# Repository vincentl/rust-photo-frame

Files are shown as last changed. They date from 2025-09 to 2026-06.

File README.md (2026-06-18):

# Photo Frame

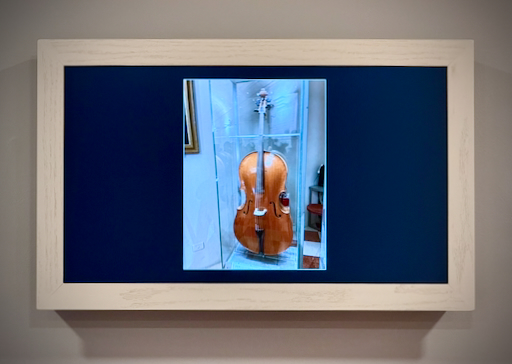
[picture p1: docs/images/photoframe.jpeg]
photo frame on grey wall with cream colored wooden frame displaying black matted image of a string instrument


Build a wall-mounted digital photo frame from a Raspberry Pi 5 and a 4K monitor. It runs a self-managing slideshow from a local photo library: GPU-accelerated transitions, customizable matting, a smart playlist that favors newer photos while keeping the rotation evenly spread, and a built-in Wi-Fi recovery portal — all on-device, no cloud dependency after setup.

**Built for makers and hobbyists** who want a bespoke display they fully control, not a subscription appliance.

---

## What you'll build

A kiosk-mode Raspberry Pi 5 that:

- Cycles through photos in `/var/lib/photoframe/photos` with smooth GPU transitions and matting
- Favors freshly added photos and spreads the rotation so it never feels repetitive
- Wakes and sleeps on a configurable schedule (or stays on always — your choice)
- Recovers from Wi-Fi drops by raising a hotspot with a QR-code-guided web UI for re-provisioning credentials
- Accepts control commands over a Unix socket for scripting and hardware button integration

---

## What you'll need

| Component | Notes |
| --- | --- |
| Raspberry Pi 5 (4 GiB+) | 8 GiB recommended for 4K with effects |
| 4K monitor | Tested with Dell S2725QC 27" 4K. HDMI-CEC is not used. |
| Power | Pi 5 runs off the monitor's USB-C PD port; a 27W USB-C supply only if your monitor lacks PD |
| HDMI cable | Short, high-quality run; the display won't tolerate a marginal cable |
| High-endurance microSD  | 32 GiB+ recommended for always-on use |
| Momentary pushbutton | Optional — wires to Pi 5 power pads for hardware wake/sleep |
| Mounting + enclosure | French-cleat + shadow-box reference build with CAD files in `maker/` |

Full BOM and physical assembly: **[docs/build.md](docs/build.md)**.

---

## Get started

1. **Build the frame** — [docs/build.md](docs/build.md): BOM, button wiring, fabrication
2. **Install the software** — [docs/install.md](docs/install.md): SD card → first wake
3. **Preview effects** — a labeled tour of every transition and mat so you can choose which to configure: stage photos, run `showcase/activate.sh` on the Pi (see [showcase/README.md](showcase/README.md))
4. **Tune the experience** — [docs/configure.md](docs/configure.md): transitions, mats, schedule. Start from a ready-made config in [examples/](examples/README.md) (minimal, showcase tour, or the everything kitchen-sink)
5. **Run it day-to-day** — [docs/operate.md](docs/operate.md): commands and troubleshooting

Optional deeper dives (cloud sync, Wi-Fi internals, power model, memory tuning, kiosk stack) live in **[docs/advanced.md](docs/advanced.md)**; rendering performance, measurement tools, and 4K60 tuning live in **[docs/performance.md](docs/performance.md)**.

If you want to modify the code, see **[CONTRIBUTING.md](CONTRIBUTING.md)** and the contributor guides under **[developer/](developer/)**.

---

## Transitions & mats

The frame ships nine GPU **transitions** (how one photo gives way to the next) and nine **mats** (the border/background framing each photo).

| Transitions | |
| --- | --- |
| `fade` | cross-fade (optionally through black) |
| `wipe` | directional linear wipe with a feathered edge |
| `push` | incoming photo slides in, pushing the old one out |
| `e-ink` | e-paper-style flash + stripe reveal |
| `dissolve` | film-style value-noise threshold dissolve |
| `radial-wipe` | circle or diamond reveal growing from a center point |
| `venetian-blinds` | horizontal/vertical slat reveal |
| `crossfade-zoom`  | cross-fade with a gentle Ken-Burns zoom |
| `iris` | mechanical camera-iris: blades close over the photo and reopen on the next |

| Mats | |
| --- | --- |
| `fixed-color` | solid color border (one or more swatches) |
| `blur` | blurred copy of the photo as the backdrop |
| `studio` | museum mat board with a 45° bevel and linen-weave texture |
| `fixed-image` | your own image as the backdrop |
| `gradient` | linear or radial gradient between two colors |
| `vignette` | solid color with darkened edges |
| `cinematic-blur` | blurred backdrop with darken + vignette (Apple-TV-aerial look) |
| `passe-partout`  | clean 45° bevel mat board, no weave (a crisper `studio`) |
| `drop-shadow` | photo floated above a solid mat with a soft drop shadow |

Preview them live with the [showcase](showcase/README.md) tour. For commented examples of every option see [`config.yaml`](config.yaml); for the complete reference (every key, default, and behavior) see the Transition and Matting sections of [docs/configure.md](docs/configure.md).

---

## Repository layout

```
crates/photoframe/     Main slideshow application (GPU rendering, viewer pipeline)
crates/buttond/        Hardware button daemon + wake/sleep scheduling
crates/wifi-manager/   Captive portal and Wi-Fi recovery agent
crates/config-model/   Shared configuration types
setup/                 Provisioning scripts for Raspberry Pi OS
docs/                  build, install, configure, operate, advanced
showcase/              showcase.yaml, activate/deactivate scripts — labeled tour of every effect
maker/                 Physical build files (STL, SVG, SCAD)
developer/             Contributor guides (testing, architecture) + debug scripts
tests/                 Manual smoke tests and diagnostics scripts
config.yaml            Annotated example configuration
```

---

## How it works (optional deep dive)

The runtime is five async pipeline tasks — plus a Unix control-socket task — communicating over bounded channels. This keeps memory predictable and decouples CPU decode from GPU rendering.

```mermaid
flowchart LR
  MAIN[Main] --> FILES[PhotoFiles]
  MAIN --> MAN[PhotoManager]
  MAIN --> LOAD[PhotoLoader]
  MAIN --> AFFECT[PhotoEffect]
  MAIN --> VIEW[PhotoViewer]
  MAIN --> CTRL[Control socket]

  FILES -->|inventory updates| MAN
  MAN -->|invalid photo| FILES
  MAN -->|photo requests| LOAD
  LOAD -->|decoded image| AFFECT
  AFFECT -->|processed image| VIEW
  LOAD -->|invalid photo| FILES
  VIEW -->|displayed event| MAN

  BUTTOND[buttond / CLI] -->|set-state, toggle| CTRL
  CTRL -->|viewer commands| VIEW
```

- **PhotoFiles** — watches the library and maintains an inventory of available images
- **PhotoManager** — schedules photos on a virtual timeline. A half-life _weight_ favors newly added photos and fades them toward parity over a configurable period. Photos copied in while the frame is running debut within a few slides via a priority queue (it wins against the rotation at odds equal to its weight), so a just-added album appears almost immediately, then settles into the spaced rotation. A refractory _minimum-spacing_ rule keeps that rotation even — a photo can't return until a configurable fraction of the library has played — which avoids clumps and starvation _without changing how often each photo appears_ (set `playlist.order: weighted-random` for plain independent sampling). Weighting-preserving and offline-simulatable via `--playlist-dry-run`
- **PhotoLoader** — decodes JPEG/PNG in parallel (configurable concurrency) to RGBA pixel buffers
- **PhotoEffect** — optionally applies print-simulation effects (paper texture, gallery lighting)
- **PhotoViewer** — GPU-accelerated rendering with configurable matting and transitions via WGPU/Wayland
- **Control socket** (Unix) — accepts `set-state` / `toggle-state` commands from `buttond` (hardware button and wake/sleep schedule) or the CLI, and forwards them to the viewer

---

## References

- **Studio mat weave texture.** Adapted from Mike Cauchi's breakdown of tillable cloth shading. ["Research – Tillable Images and Cloth Shading"](https://www.mikecauchiart.com/single-post/2017/01/23/research-tillable-images-and-cloth-shading).
- **Print simulation shading.** Based on Rohit A. Patil, Mark D. Fairchild, and Garrett M. Johnson, ["3D Simulation of Prints for Improved Soft Proofing"](https://repository.rit.edu/cgi/viewcontent.cgi?article=1159&context=other).

---

## AI Statement

This project was developed with significant assistance from multiple AI tools:

- **Anthropic**: Claude Code with Sonnet & Opus models was used for design discussions, code generation, debugging, and drafting documentation.
- **OpenAI**: Codex with various GPT models was used for design discussions, code generation, debugging, and drafting documentation.

---

## License

MIT License — see [LICENSE](LICENSE) for full text.

© 2026 Vincent Lucarelli

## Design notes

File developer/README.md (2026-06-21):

# Developer

Documentation and tooling for working on the photo frame. End-user docs live in
[../README.md](../README.md) and [../docs/](../docs/); the contributor entry
point is [../CONTRIBUTING.md](../CONTRIBUTING.md).

## Guides

- **[testing.md](testing.md)** — automated checks, the on-device test plan, and the release checklist.
- **[architecture.md](architecture.md)** — setup-script architecture and kiosk-stack debugging.

## Scripts

Run these on a live Pi unless noted (the guides give context):

- `capture-system-baseline.sh` — snapshot system + toolchain versions under `artifacts/upgrade-baseline-<timestamp>/` (used by the dependency upgrade runbook).
- `overlay-test.sh` — overlay takeover smoke-test for Sway (focus/fullscreen behavior before Wi-Fi recovery testing).
- `suspend-wifi.sh` — simulate a Wi-Fi authentication failure to exercise the wifi-manager recovery path.
- `fake-btime.sh` — copy a file with a forced creation time (btime); handy for testing the playlist's new-photo weighting.
- `gather-playlist-metrics.sh` — pull `photo-log.txt` + `photo-list.txt` off the frame (needs `metrics: true`) for the last N days or all retained journal. `gather-playlist-metrics.sh [DAYS|all] [OUTDIR]`.
- `analyze-playlist-metrics.py` — **runs off-device** on those two files: audits coverage/starvation, recurrence spacing, weighting, and FIFO debut latency. Self-documenting header (how to gather/run/interpret) plus `--help`.
- `systemd/wifi-overlay-test.service` — unit used by the overlay takeover test.

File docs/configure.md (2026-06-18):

# Configure

The active configuration on an installed system is `/etc/photoframe/config.yaml` (edit with `sudo`). When running from source, pass the config path on the CLI.

After editing, restart the kiosk to apply:

```bash
sudo systemctl stop greetd.service && sleep 1 && sudo systemctl start greetd.service
```

> Always edit `/etc/photoframe/config.yaml`, not the template at `/opt/photoframe/etc/photoframe/config.yaml` — the template gets overwritten on redeploy.

The visual feature blocks (`transition`, `matting`, `photo-effect`) all use a shared `selection` + `active` structure described below.

## Quick start

For most edits, this is the sequence:

1. Set `photo-library-path` to your actual photo root.
2. Tune slide pacing with `global-photo-settings.dwell-ms`.
3. Pick one transition preset in `transition.active`.
4. Pick one mat preset in `matting.active`.
5. Validate without launching the viewer:

   ```bash
   cargo run -p photoframe -- --playlist-dry-run 1
   ```

## Choosing a starting config

You don't have to start from scratch. The repo ships several starting points
(details and a comparison table in [examples/README.md](../examples/README.md)):

- [`config.yaml`](../config.yaml) — the rich, fully-commented default the installer
  seeds; every transition and mat with varied colors and angles. Most people start here.
- [`examples/minimal.yaml`](../examples/minimal.yaml) — the smallest valid file; build up
  from defaults.
- [`examples/use-showcase.yaml`](../examples/use-showcase.yaml) — a labeled tour of every
  transition and mat (see [showcase/README.md](../showcase/README.md)).
- [`examples/everything.yaml`](../examples/everything.yaml) — every kind *and* every
  parameter variant, to trim down.

Copy one over `/etc/photoframe/config.yaml` (or crib blocks from it) and restart the kiosk.

## Starter configuration

```yaml
photo-library-path: /var/lib/photoframe/photos
# ├── cloud/  # managed by sync jobs; safe to resync or replace wholesale
# └── local/  # manual drops (USB, scp) that should survive sync resets

# Render/transition settings
transition:
  selection: random # fixed, random, or sequential
  active:
    - kind: fade
      duration-ms: 400
global-photo-settings:
  dwell-ms: 12000 # Time an image remains fully visible (ms)
  oversample: 1.0 # GPU render oversample vs. screen size
  max-upscale-factor: 1.0 # Limit for enlarging small images
viewer-preload-count: 3 # Images the viewer preloads; also sets viewer channel capacity
loader-max-concurrent-decodes: 4 # Concurrent decodes in the loader
startup-shuffle-seed: null # Optional deterministic seed for initial shuffle

photo-effect:
  active: [] # Optional effects; add entries (e.g., print-simulation) to enable

playlist:
  new-multiplicity: 3 # How many copies of a brand-new photo to schedule per cycle
  half-life: 3 days # How quickly that multiplicity decays back toward 1

matting:
  selection: random
  active:
    - kind: fixed-color
      minimum-mat-percentage: 0.0 # % of each screen edge reserved for the mat border
      colors: [[0, 0, 0], [32, 32, 32]]
    - kind: blur
      minimum-mat-percentage: 3.5
      sigma: 32.0
      sample-scale: 0.125
      backend: neon  # arm64 vector path; falls back to cpu automatically
```

If the frame launches to a black screen, check that `photo-library-path` points to a directory the runtime can read and that the kiosk account has access. The directory should contain `cloud/` and `local/` subdirectories — the runtime merges both. Validate a YAML edit quickly with `cargo run -p photoframe -- --playlist-dry-run 1`, which parses the config without opening the render window.

## Top-level keys

| Role | Keys |
| --- | --- |
| **Required** | `photo-library-path` |
| **Schema** | `config-version` |
| **Core timing** | `transition`, `global-photo-settings`, `playlist` |
| **Performance tuning**  | `viewer-preload-count`, `loader-max-concurrent-decodes`, `global-photo-settings.oversample` |
| **Deterministic runs**  | `startup-shuffle-seed` |
| **Presentation** | `photo-effect`, `matting` |
| **Greeting / Sleep** | `greeting-screen`, `sleep-screen` |
| **Runtime control** | `control-socket-path` |
| **External scheduling** | `awake-schedule` (consumed by `buttond`) |
| **Power button daemon** | `buttond` |
| **Showcase / preview**  | `showcase` |

## Key reference

### `config-version`

- **Purpose:** Declares which config-schema version the file targets, so a config written for a newer, incompatible schema fails fast with a clear message instead of a confusing per-key error.
- **Required?** Optional; defaults to the current supported version (`1`).
- **Accepted values & defaults:** A positive integer. This build supports `1`. A value higher than the build supports is rejected at startup with a message telling you to update photoframe.
- **Notes:** Leave at `1` unless a release note instructs otherwise. The version only bumps on a breaking config-schema change, which will be documented in the git history / release notes.

### `photo-library-path`

- **Purpose:** Sets the root directory that will be scanned recursively for supported photo formats.
- **Required?** Yes.
- **Accepted values & defaults:** Any absolute or relative filesystem path. The setup pipeline provisions `/var/lib/photoframe/photos` with `cloud/` and `local/` subdirectories.
- **Effect on behavior:** Switching the path changes the library the watcher monitors; the viewer reloads the playlist when the directory contents change.
- **Notes:** Keep the `cloud/` and `local/` folders under the configured root. Use `cloud/` for sync-managed content (rclone, Nextcloud) and `local/` for manual imports the sync should never prune.

### `control-socket-path`

- **Purpose:** Selects where the application exposes its Unix domain control socket.
- **Required?** Optional; defaults to `/run/photoframe/control.sock`.
- **Accepted values & defaults:** Any filesystem path, typically under `/run`, `/run/user/<uid>`, or another writable runtime directory.
- **Notes:** The kiosk provisioning script creates `/run/photoframe` (mode `0770`, owned by `kiosk:kiosk`) and installs a tmpfiles entry so the directory exists after every boot. If you override the setting, pre-create the directory with matching ownership: `sudo install -d -m 0770 -o kiosk -g kiosk /run/photoframe`.

### `transition`

- **Purpose:** Controls how the viewer blends between photos.
- **Required?** Optional; when omitted the frame uses a 400 ms fade.
- **Accepted values & defaults:** Mapping documented in [Transition configuration](#transition-configuration).
- **Effect on behavior:** Adjust duration, direction, randomness, or transition family — from subtle fades to bold pushes or e‑ink reveals.

### `global-photo-settings`

- **Purpose:** Core photo timing and sizing parameters.
- **Required?** Optional; sensible defaults apply when omitted.
- **Keys and defaults:**
  - `dwell-ms` (u64, default `2000`): How long to show the current photo before transitioning.
  - `oversample` (float, default `1.0`): GPU render oversample relative to screen size. Must be positive.
  - `max-upscale-factor` (float, default `1.0`): Maximum enlargement applied when fitting small photos inside the mat.

### `viewer-preload-count`

- **Purpose:** Number of decoded images the viewer keeps queued ahead of the current slide.
- **Required?** Optional. Default `3`.
- **Effect on behavior:** Higher counts buffer more content, smoothing playback on slower storage but increasing memory usage. See [Advanced › Memory tuning](advanced.md#memory-tuning) for sizing guidance.

### `loader-max-concurrent-decodes`

- **Purpose:** Limits how many images the CPU decoding task processes simultaneously.
- **Required?** Optional. Default `4`. Minimum `1`.

### `startup-shuffle-seed`

- **Purpose:** Seeds the initial RNG used when shuffling the first playlist.
- **Required?** Optional. `null` (default) draws entropy from the system RNG.
- **Effect:** Providing a seed freezes the opening order — useful for demos, debugging, or deterministic tests.

### `playlist`

- **Purpose:** Tunes how the weighting system surfaces new photos and how evenly the slideshow spreads them.
- **Required?** Optional.
- **Defaults:** three copies for new images, one-day half-life, `weighted-spread` order at `min-spacing` 0.7.

See [Playlist weighting](#playlist-weighting) for the algorithm.

### `photo-effect`

- **Type:** mapping (see [Photo effect configuration](#photo-effect-configuration))
- **Default:** disabled (`active: []`)
- **What it does:** Inserts an optional post-processing stage between the loader and viewer. The built-in `print-simulation` effect relights each frame with directional shading and paper sheen. Add it to `active` to enable; leave the list empty to keep the stage off.

### `greeting-screen`

- **Purpose:** Styles the GPU-rendered welcome card displayed while the library is warming up.
- **Required?** Optional.
- **Keys:**
  - `message` (string, default `Initializing…`)
  - `font` (string font name; falls back to bundled face)
  - `stroke-width` (float DIP, default `16.0`)
  - `corner-radius` (float DIP, default `0.75 × stroke-width`)
  - `duration-seconds` (float ≥ 0, default `4.0`)
  - `colors.background`, `colors.font`, `colors.accent` (hex sRGB strings)
- **Effect:** The renderer fits and centers the message inside a rounded double-line frame. `duration-seconds` guarantees the greeting remains on screen for at least that many seconds before the first photo appears.
- **Notes:** Colors accept `#rgb`, `#rgba`, `#rrggbb`, or `#rrggbbaa`. Low-contrast combinations log a warning.

### `sleep-screen`

- **Purpose:** Styles the card shown as the frame transitions into sleep.
- **Keys:** Mirror `greeting-screen` aside from `duration-seconds`, which does not apply when sleeping.
- **Effect:** Shares the same renderer as the greeting card, so sizing rules and readability checks are identical.

### Wake/sleep control

- **How it works:** The application has no internal schedule. After startup it remains asleep until another client sends `set-state` or `toggle-state` commands over the control socket.
- **Manual control:** Pipe JSON such as `{"command":"set-state","state":"awake"}` or `{"command":"toggle-state"}` to `/run/photoframe/control.sock` (override via `control-socket-path`).
- **Automation:** Deploy `buttond` (see below) and populate the shared `awake-schedule` block. `buttond` evaluates the schedule, issues `set-state` commands at the appropriate boundaries, and runs display power hooks on your behalf.

Example schedule fragment consumed by `buttond`:

```yaml
awake-schedule:
  timezone: America/New_York
  awake-scheduled:
    daily:
      - ["07:30", "22:00"]
    weekend:
      - ["09:00", "23:00"]
```

`awake-schedule` supports wrap-past-midnight windows, weekday/weekend overrides, and per-day exceptions. Times use `HH:MM` or `HH:MM:SS`. To wrap past midnight, give a range whose start is **later** than its end — e.g. `["21:00", "07:00"]` keeps the frame awake from 9 PM until 7 AM the next morning. An empty list for a day key (e.g. `friday: []`) means **sleep all day on that day** — remove the key to fall back to the `daily` window.

### `buttond` (power button daemon)

`buttond` watches the Pi 5 power-pad button via evdev and orchestrates scheduled wake/sleep transitions. It also drives DPMS commands so the panel actually powers down between schedule windows.

```yaml
buttond:
  device: null                      # optional explicit evdev path
  debounce-ms: 20                   # ignore chatter within this window
  single-window-ms: 250             # treat releases shorter than this as taps
  double-window-ms: 400             # wait this long for a second tap
  force-shutdown: true              # for systemctl: add -i and --no-ask-password
  shutdown-command:
    program: /usr/bin/systemctl
    args: [poweroff]
  screen:
    off-delay-ms: 3500
    display-name: HDMI-A-2          # wlr-randr output name; null = auto-detect
    on-command:
      program: /opt/photoframe/bin/powerctl
      args: [wake]
    off-command:
      program: /opt/photoframe/bin/powerctl
      args: [sleep]
```

Pair the block with a top-level `awake-schedule` to describe the desired wake windows.

**`buttond.screen.display-name` discovery.** The connector name must be queried inside the kiosk Wayland session:

```bash
# display is usually wayland-1; find it with: sudo ls /run/user/$(id -u kiosk)/wayland-*
sudo -u kiosk env XDG_RUNTIME_DIR=/run/user/$(id -u kiosk) WAYLAND_DISPLAY=wayland-1 wlr-randr
```

Common values: `HDMI-A-1`, `HDMI-A-2`. Setting `display-name` explicitly avoids auto-detect ambiguity on systems with multiple connectors.

**`force-shutdown`** controls whether `buttond` augments a systemctl command with `-i` (ignore inhibitors) and `--no-ask-password`. The default `true` makes `systemctl poweroff -i --no-ask-password` succeed without prompts. If you point `shutdown-command.program` at something other than `systemctl`, `buttond` strips those flags automatically.

**Runtime behavior:**

- **Single press:** resolves the current screen state and sends the appropriate `set-state` command to the control socket, then toggles the screen. If the display was off it immediately runs the wake command; if on, it delays for `off-delay-ms` (so the sleep card renders) before running the sleep command. The daemon inspects `wlr-randr` on each press, so restarts and manual overrides stay in sync.
- **Double press:** executes `shutdown-command`. Polkit allows `kiosk` to issue the request without prompting.
- **Long press:** bypassed so Pi 5 firmware can force power-off.
- **Scheduled transitions:** when `awake-schedule` is present, `buttond` waits for the greeting delay, applies the schedule's current state, then drives transitions using `set-state`.
- **Manual override:** a single press overrides the schedule until the next scheduled wake/sleep boundary, then the frame resumes following the schedule automatically. Press again to undo immediately. For example, pressing to sleep during a wake window keeps the frame asleep until that window ends; pressing to wake during a sleep window keeps it awake until the next scheduled wake.

`buttond` auto-derives `XDG_RUNTIME_DIR` and `WAYLAND_DISPLAY` for its `wlr-randr`/sway probes. Auto-detection scans `/dev/input/by-path/*power*` before falling back to `/dev/input/event*`. Set `buttond.device` if the wrong input is chosen. Provisioning pins `HandlePowerKey=ignore` in `/etc/systemd/logind.conf` so logind doesn't interpret presses as shutdown requests; only `buttond` reacts.

### `matting`

- **Purpose:** Chooses the mat/background style rendered behind every photo.
- **Required?** Optional.
- **Defaults:** `{ selection: fixed, active: [{ kind: fixed-color }] }` with a black swatch.

See [Matting configuration](#matting-configuration) for the full reference.

### `showcase`

- **Purpose:** Turns the slideshow into a labeled, deterministic tour of every registered transition and mat. On-screen captions identify each effect so you can copy the name directly into your real config.
- **Required?** Optional; defaults to disabled.
- **Keys:**

| Key | Type | Default | Meaning |
|-----|---|---|---|
| `enabled` | `bool` | `false` | Activates showcase mode. Overrides `transition.active` and `matting.active` with auto-enumerated sequential lists. |
| `caption` | `bool` | `true` | Show a text label (`transition: X mat: Y`) in the bottom-left corner of each frame. |
| `dwell-ms` | `u64` | `4000` | Milliseconds each photo is held; overrides `global-photo-settings.dwell-ms` when showcase is on. |
| `fixed-image-path` | path | — | Opt-in: include the `fixed-image` mat in the tour using this file as the backdrop. Omitting the path silently skips `fixed-image`. |

When `showcase.enabled` is true, `startup-shuffle-seed` defaults to `1` if unset, and `transition.active`/`matting.active` in the same file are ignored.

See [showcase/README.md](../showcase/README.md) and [Showcase mode](#showcase-mode) for usage.

## Showcase mode

Showcase mode is the fastest way to choose transitions and mats. It auto-enumerates every built-in effect, displays each one with a live caption, and advances to the next after a configurable dwell.

**Workflow (on the Pi):**

1. Stage media under `/var/lib/photoframe/showcase/photos/` (and optionally a `backgrounds/background.jpg` backdrop). See [showcase/README.md](../showcase/README.md).
2. Run `./showcase/activate.sh` — it backs up your live config, swaps in `showcase/showcase.yaml`, and restarts the kiosk into the tour.
3. Watch the captions. When you see an effect you like, the caption tells you the exact `kind` key.
4. Copy the kind(s) into your real `config.yaml` under `transition.active` and/or `matting.active`.
5. Run `./showcase/deactivate.sh` to restore your normal slideshow.

**Self-maintaining:** the tour is built at startup from `TransitionKind::ALL` and `MattingKind::ALL`. When future effects are added to the frame, they automatically appear in the tour without any edits to `showcase.yaml`.

**Interactive control** (e.g. advancing manually via a socket command) is not implemented — the tour advances on a timed dwell. This fits the frame's passive, keyboard-less Pi kiosk model; a `showcase-next` control command may be added in the future.

## Playlist weighting

Each photo is scheduled on a virtual timeline. A photo's **weight** sets how often it
appears: `weight(age) = max(1, new_multiplicity × 0.5^(age / half_life))`. Brand-new
photos peak at `new-multiplicity` and decay by half every `half-life` toward the
equilibrium weight of 1. After each showing a photo is rescheduled a random gap ahead
whose average length is `1 / weight`, so higher-weight photos recur sooner while still
being spaced apart (no bursts, no back-to-back repeats). Adding or removing photos
updates the schedule incrementally without resetting progress.

**Scheduling `order`** selects how each photo's showings are *spaced* around that
`1 / weight` average, without changing the average itself (so weighting is identical
across orders):

- `weighted-spread` (default) draws a **refractory (minimum-wait) gap**: a deterministic
  floor that no showing may fall below, plus exponential jitter above it. The
  `min-spacing` knob (`[0.0, 1.0)`) sets the floor as a fraction of one library "lap" — a
  photo's mean recurrence interval, which equals the library size in displays. So
  `min-spacing = 0.5` means *"a photo cannot return until at least half the library has
  played."* `0.7` (the shipped value) is a good balance of even coverage and
  unpredictability.
- `weighted-random` draws a plain **exponential** gap — memoryless, which makes it
  statistically equivalent to i.i.d. uniform-with-replacement. Simple, but high gap
  variance: some photos clump together while others go unseen for a long time. Identical
  to `weighted-spread` with `min-spacing: 0.0`; opt in only if you want raw randomness.

The gap law is `gap = f/weight + (1 − f)/weight · Exp(1)` with `f = min-spacing`. Its
mean is `1/weight` for every `f`, so **a photo's long-run show frequency never
changes** — only its spacing does (coefficient of variation `= 1 − f`). The floor also
auto-scales with weight, so a high-weight new photo is still allowed back sooner.

**Prompt debut for new photos.** The minimum-spacing floor would otherwise delay a
freshly copied-in photo's *first* appearance by a full `min-spacing` lap (tens of
minutes on a large library). To avoid that, photos discovered while the frame is
running enter a small priority queue and debut ahead of the timeline, chosen by a
biased coin: the new photo wins against the normal rotation at odds equal to its weight
(`w : 1`). So a fresh photo (weight ≈ `new-multiplicity`) appears within a few slides,
while the rest of the rotation still shows ~`1/(w+1)` of the time — no stall. After its
debut the photo joins the spaced timeline normally. This applies only to runtime
additions; the startup scan and `--playlist-dry-run` schedule straight onto the
timeline, so simulation stays deterministic.

Turn on `metrics: true` (see [Performance → Measuring](performance.md#measuring)) and
grep `photo_display_metric` to measure the effect — the `gap` column is the number of
displays between successive showings of a photo. Under `weighted-spread` it stays around
or above `min-spacing × inventory` (the floor is exact in the scheduler's virtual clock;
display counts vary slightly), and its variance shrinks as `min-spacing` rises.

`age` is the difference between the current time and the photo's filesystem creation timestamp — i.e. **when the file was staged to the frame, not its EXIF capture date**. The frame prefers the filesystem birth time (`st_birthtime`), falling back to mtime and then to "now" only if birth time is unavailable; EXIF is never consulted. So copying photos onto the frame makes them "new" regardless of when they were taken. With `metrics: true`, each `photo_display_metric` line reports `age_days` and `created_source` (`birthtime`/`mtime`/`now`) so you can confirm photos are aged by birth time and not silently falling back to mtime — which a timestamp-preserving copy (`cp -p`, `rsync -t`/`-a`) could otherwise reintroduce. The clock defaults to `SystemTime::now()` but can be frozen via `--playlist-now <RFC3339>`.

### Testing the weighting

```bash
cargo run -p photoframe --release -- \
  config.yaml \
  --playlist-now 2025-01-01T00:00:00Z \
  --playlist-dry-run 32 \
  --playlist-seed 1234
```

Prints the **weight** (relative show frequency; equilibrium = 1.0) for each discovered photo and the first 32 scheduled entries. Run with the same seed twice to confirm deterministic output.

### Playlist knobs

| Field | Required? | Default | Accepted values | Effect on the slideshow |
| --- | --- | --- | --- | --- |
| `new-multiplicity` | Optional  | `3` | Integer ≥ 1 | Sets the peak weight for a brand-new photo; higher values surface newcomers more often before they decay. |
| `half-life` | Optional  | `1 day` | Positive duration string parsed by [`humantime`](https://docs.rs/humantime) | Controls how quickly the weight decays back to equilibrium; shorter half-lives return to normal faster. |
| `order` | Optional  | `weighted-spread` | `weighted-spread`, `weighted-random` | Scheduling algorithm. `weighted-spread` (default) adds a minimum-wait floor before a photo can recur; `weighted-random` is plain exponential-gap (i.i.d. random). Weighting (average frequency) is identical for both. |
| `min-spacing` | Optional  | `0.7` | Float in `[0.0, 1.0)` | For `weighted-spread` only: minimum wait before a photo repeats, as a fraction of one library lap. `0.0` equals `weighted-random`; `0.5` waits half the library. Preserves show frequency; only spacing changes. Ignored by `weighted-random`. |

## Photo-effect configuration

The optional `photo-effect` task sits between the loader and the viewer. When enabled it reconstructs the decoded RGBA pixels, applies any configured effects, and forwards the modified image downstream. Leave `photo-effect.active` empty (or omit the block) to short-circuit the stage. Duplicate entries to weight the random picker or alternate presets sequentially.

### Scheduling effects

| Key | Required? | Default | Accepted values | Effect |
| --- | --- | --- | --- | --- |
| `selection` | Optional  | `fixed` when `active` has one entry, otherwise `random` | `fixed`, `random`, `sequential` | Controls how the viewer iterates through `active`. `fixed` locks to the first entry, `random` chooses independently per slide, `sequential` advances in order and loops. |
| `active` | Yes | — | Array of effect entry maps | Declares the effect variants that are eligible. Repeat entries to weight the random picker or alternate presets in sequential mode. |

### Print-simulation effect

`print-simulation` mimics how a framed print interacts with gallery lighting. It derives a shallow height-field from local luminance gradients, shades that relief with a configurable key light, and layers in ink compression plus paper sheen so highlights glow like coated stock.

- `light-angle-degrees` (float, default `135.0`): direction of the simulated gallery lighting in degrees clockwise from +X.
- `relief-strength` (float ≥ 0, default `0.35`): scale factor on the derived height-field.
- `ink-spread` (float ≥ 0, default `0.18`): tone compression coefficient that emulates dye absorption.
- `sheen-strength` (float ≥ 0, default `0.22`): how strongly paper sheen blends into highlights.
- `paper-color` (RGB array, default `[245, 244, 240]`): base tint of the reflective sheen layer.
- `debug` (bool, default `false`): when `true`, only the left half of the image receives the effect — useful for A/B comparison.

## Transition configuration

The `transition` block controls how the viewer blends between photos. Supply one or more entries under `transition.active`; each begins with a required `kind` (`fade`, `wipe`, `push`, `e-ink`, `dissolve`, `radial-wipe`, `venetian-blinds`, `crossfade-zoom`, or `iris`) followed by family-specific fields.

| Key | Required? | Default | Accepted values | Effect |
| --- | --- | --- | --- | --- |
| `selection` | Optional  | `fixed` when `active` has one entry, otherwise `random` | `fixed`, `random`, or `sequential` | Controls how the viewer iterates through `active`. |
| `active` | Yes | — | Array of transition entry maps | Declares the transition variants that are eligible. Repeat entries to weight the random picker or alternate presets in sequential mode. |

When `selection` is omitted, the runtime infers it: a single entry becomes `fixed`; multiple entries default to `random`. `selection: fixed` requires exactly one entry, while `selection: sequential` or `selection: random` accept any non-empty list.

Each active entry accepts:

- **`duration-ms`** (integer, default `400` for `fade`, `wipe`, `push`; `1600` for `e-ink`): total runtime of the transition. Must be positive.

The remaining knobs depend on the family:

- **`fade`**
  - **`through-black`** (boolean, default `false`): fade to black completely before revealing the next image.
- **`wipe`**
  - **`angles`** (array of floats, default `[0.0]`): wipe directions in degrees (`0°` left→right, `90°` top→bottom). At least one finite value required. Each angle expands into its own canonical option; repeat values to bias direction.
  - **`angle-jitter`** (float ≥ 0, default `0.0`): random jitter within ±the supplied degrees.
  - **`softness`** (float, default `0.05`, clamped `0.0–0.5`): feathers the wipe edge.
- **`push`**
  - **`angles`** (array of floats, default `[0.0]`): direction the new image pushes from.
  - **`angle-jitter`** (float ≥ 0, default `0.0`): randomizes the push direction.
- **`e-ink`**
  - **`flash-count`** (integer, default `0`, capped at `6`): alternating black/flash pulses before the reveal.
  - **`reveal-portion`** (float, default `0.55`, clamped `0.05–0.95`): fraction of the timeline spent flashing before stripes start uncovering.
  - **`stripe-count`** (integer ≥ 1, default `24`): horizontal bands sweeping in.
  - **`flash-color`** (`[r, g, b]` array, default `[255, 255, 255]`): RGB color for the bright flash phases. Channels outside `0–255` are clamped.
- **`dissolve`** — threshold a value-noise field by progress (classic film dissolve).
  - **`softness`** (float 0–0.5, default `0.1`): width of the smoothstep band around the threshold. `0` = hard per-pixel pop.
  - **`scale`** (float > 0, default `64.0`): noise cell size in pixels (smaller = finer grain).
- **`radial-wipe`** — circle or diamond reveal growing from a center point.
  - **`softness`** (float 0–0.5, default `0.1`): edge feather width.
  - **`shapes`** (list of `circle` and/or `diamond`, default `[circle]`): distance metric (Euclidean vs. Manhattan). Each entry expands into its own slot, so `[circle, diamond]` shows both.
  - **`center`** (`[x, y]` normalized UV, default `[0.5, 0.5]`): reveal origin.
- **`venetian-blinds`** — horizontal or vertical stripe reveal.
  - **`stripe-count`** (integer ≥ 1, default `16`): number of blind slats.
  - **`softness`** (float 0–0.5, default `0.1`): feather of each slat's edge.
  - **`orientations`** (list of `horizontal` and/or `vertical`, default `[horizontal]`): slat direction. Each entry expands into its own slot, so `[horizontal, vertical]` shows both.
- **`crossfade-zoom`** — fade combined with a subtle scale (gentle Ken-Burns dissolve).
  - **`zoom`** (float 0–0.5, default `0.06`): maximum fractional scale change.
  - **`current-zooms-in`** (boolean, default `true`): if true the outgoing photo scales up while fading.
  - **`next-zooms-in`** (boolean, default `true`): if true the incoming photo starts slightly zoomed and settles.
- **`iris`** — mechanical camera-iris diaphragm (default `duration-ms` `2600`): annular petals with rounded ends pivot closed over the current photo, then reopen on the next. Petal geometry (radii, width, pivots, swing) is derived from the screen size and blade count, so only look-related knobs are exposed.
  - **`blades`** (integer, default `9`, clamped `5–14`): petal count.
  - **`color`** (`[r, g, b]` array, default `[42, 42, 49]`): base petal color. Mid-dark colors show the petal shading best; near-black flattens it.
  - **`petal-sheen`** (float 0–1, default `0.45`): strength of the directional sheen — a fixed virtual light that brightens blades facing it and darkens those opposite, making the individual petals read as distinct. `0` renders perfectly flat petals, distinguished only by the overlap-shadow seams (the look of a real anodized-metal iris); `1.0` is the maximum lighting swing.
  - **`overlap-shadow`** (float 0–1, default `0.6`): darkness of the soft shadow each petal casts on the one beneath it along the overlap seam.
  - **`min-aperture`** (float 0–0.4, default `0.05`): fraction of the screen circumradius left open at full close; the photos crossfade behind the petals while the aperture is at its smallest.
  - **`swirl`** (float −1–1, default `-0.45`): signed twist of the whole petal rosette while closing, as if both iris rings counter-rotate. `0` keeps the rosette orientation fixed; the sign sets the twist direction.

Examples are in [Transition examples](#transition-examples).

## Matting configuration

The `matting` block prepares the background behind each photo. During parsing the viewer normalizes the section into a canonical list:

1. Read `matting.active` from top to bottom and record each entry's `kind` plus its options.
2. Expand inline collections in place. Every swatch in a `colors` array, every `photo-average` token, and every fixed-image `path` becomes its own canonical slot while preserving the entry's order.
3. Attach the resulting slots to their underlying renderer (`fixed-color`, `blur`, `studio`, or `fixed-image`).

`matting.selection` operates on that expanded list. `random` samples from every canonical slot — duplicates weight the draw — while `sequential` walks the expanded order before looping. Duplicating colors, paths, or `active` entries is the way to bias rotation; the outer `selection` controls traversal.

| Key | Required? | Default | Accepted values | Effect |
| --- | --- | --- | --- | --- |
| `selection` | Optional  | `fixed` when the canonical list has one slot; otherwise `random` | `fixed`, `random`, or `sequential` | Governs how the viewer iterates through the canonical mat list. |
| `active` | Yes | — | Array of mat entry maps | Declares the mat variants. Duplicate swatches or paths expand into multiple canonical slots. |
| `fill-when-fits` | Optional  | disabled (omit to keep matting on every photo) | Map (see below) | Renders photos already close to the screen aspect full-bleed (no mat) so they fully use a large display. |

### `fill-when-fits`

When present, each photo is evaluated **before** mat selection: if its aspect ratio is close enough to the display that filling the screen only crops a little, the viewer may render it edge-to-edge (center-crop to cover) instead of matting it. Because the decision happens before selection, an ineligible photo simply falls through to normal mat selection — the `sequential` counter and `random`/`fixed` pools are untouched.

- **`maximum-crop-percentage`** (float, default `5.0`): a photo is eligible when filling the screen crops less than this percentage off the single overflowing axis. The check is purely aspect-ratio based, so it is independent of resolution. A photo is also only eligible when it is large enough to fill the screen within `global-photo-settings.max-upscale-factor`.
- **`skip-matting-probability`** (float, default `1.0`, clamped `0–1`): for an eligible photo, the biased-coin probability of actually skipping the mat. `1.0` always fills eligible photos, `0.0` never does (feature effectively off), and values in between mix full-bleed photos with matted ones.

Each active entry accepts:

- **`minimum-mat-percentage`** (float, default `0.0`): fraction of each screen edge reserved for the mat border. Clamped `0–45%`.

The remaining controls depend on `kind`:

- **`fixed-color`**
  - **`colors`** (array of `[r, g, b]` triples, default `[[0, 0, 0]]`): one or more RGB swatches to rotate through. Channels outside `0–255` are clamped.
  - **`color`** (`[r, g, b]` triple): convenience alias for `colors` with one swatch.
- **`blur`**
  - **`sigma`** (float, default `32.0`): Gaussian blur radius applied to a scaled copy of the photo.
  - **`sample-scale`** (float, default `0.125`): ratio between canvas resolution and the intermediate blur buffer. Higher values sharpen the backdrop at higher cost.
  - **`backend`** (`cpu` or `neon`, default `neon`): blur implementation. `neon` opts into the vector-accelerated path on 64-bit ARM and falls back to `cpu` when unavailable.
- **`studio`**
  - **`colors`** (array containing `[r, g, b]` triples and/or the string `photo-average`; default `[photo-average]`): palette entries used for the mat base. `photo-average` reuses the slide's average color. **`color`** is a convenience alias for a single entry.
  - **`bevel-width-px`** (float, default `3.0`).
  - **`bevel-color`** (`[r, g, b]` array, default `[255, 255, 255]`).
  - **`texture-strength`** (float, default `1.0`): strength of the simulated paper weave (`0.0` = flat matte).
  - **`warp-period-px`** (float, default `5.6`): horizontal spacing between vertical warp threads.
  - **`weft-period-px`** (float, default `5.2`): vertical spacing between horizontal weft threads.
- **`fixed-image`**
  - **`path`** (string or string array, required): filesystem paths to the backdrop image(s). The renderer loads them at startup; an empty array disables the entry.
  - **`fit`** (`cover`, `contain`, or `stretch`; default `cover`).
- **`gradient`** — linear or radial gradient between two colors.
  - **`start-color`** (`[r, g, b]`, default `[20, 20, 28]`): color at the top / left / center.
  - **`end-color`** (`[r, g, b]`, default `[70, 70, 90]`): color at the bottom / right / outer edge.
  - **`direction`** (`vertical`, `horizontal`, or `radial`; default `vertical`).
  - **`angle-degrees`** (float, default `0.0`): optional rotation for linear gradients; ignored for `radial`.
- **`vignette`** — solid color with darkened edges.
  - **`colors`** (array of `[r, g, b]` triples and/or `photo-average`; default `[[241, 233, 210]]` (parchment)): base mat color(s). Multiple entries expand to multiple slots. **`color`** is a convenience alias for a single value (also accepts `photo-average`).
  - **`strength`** (float 0–1, default `0.6`): how dark the corners get.
  - **`radius`** (float 0–1, default `0.75`): where the falloff begins, as a fraction of the half-diagonal.
  - **`softness`** (float 0–1, default `0.5`): width of the falloff band.
- **`cinematic-blur`** — blurred photo backdrop with a darken and vignette overlay (Apple-TV-aerial look).
  - **`sigma`** (float, default `32.0`): same as `blur.sigma`.
  - **`sample-scale`** (float, default `0.125`): same as `blur.sample-scale`.
  - **`backend`** (`cpu` or `neon`, default `neon`): same as `blur.backend`.
  - **`darken`** (float 0–1, default `0.35`): uniform darkening applied over the blur.
  - **`vignette-strength`** (float 0–1, default `0.5`): extra edge darkening.
- **`passe-partout`** — clean 45° core-bevel mat board without linen weave (crisper alternative to `studio`).
  - **`colors`** (array of `[r, g, b]` triples and/or `photo-average`; default `[photo-average]`): mat board color(s). Multiple entries expand to multiple slots. **`color`** is a convenience alias for a single entry.
  - **`bevel-width-px`** (float, default `3.0`).
  - **`bevel-color`** (`[r, g, b]`, default `[255, 255, 255]`).
- **`drop-shadow`** — soft drop shadow under the photo on a solid mat.
  - **`colors`** (array of `[r, g, b]` triples and/or `photo-average`; default `[[235, 235, 235]]`): mat background color(s). Multiple entries expand to multiple slots. **`color`** is a convenience alias for a single value (also accepts `photo-average`).
  - **`shadow-color`** (`[r, g, b]`, default `[0, 0, 0]`): shadow tint.
  - **`shadow-opacity`** (float 0–1, default `0.4`): shadow strength at its darkest.
  - **`shadow-blur-px`** (float, default `24.0`): softness of the shadow edge.
  - **`shadow-offset-px`** (`[x, y]` integer pair, default `[0, 12]`): shadow displacement; positive y is downward.

> Store operator-managed background images under `/var/lib/photoframe/backgrounds`. The setup pipeline treats `/opt/photoframe` as read-only and refreshes it on redeploy.

Examples are in [Matting examples](#matting-examples).

## Photo-effect examples

### Sequential print-simulation presets

```yaml
photo-effect:
  selection: sequential
  active:
    - kind: print-simulation
      light-angle-degrees: 110.0
    - kind: print-simulation
      light-angle-degrees: 60.0
      debug: true
```

## Transition examples

### Simple fade

```yaml
transition:
  active:
    - kind: fade
      duration-ms: 450
```

### Fade through black

```yaml
transition:
  active:
    - kind: fade
      duration-ms: 600
      through-black: true
```

### Weighted random mix

```yaml
transition:
  selection: random
  active:
    - kind: fade
      duration-ms: 450
    - kind: push
      duration-ms: 520
      angles: [0.0]
    - kind: push
      duration-ms: 520
      angles: [180.0]
```

Repeating the `push` entry gives that family twice the draw weight versus `fade`.

### Sequential rotation with duplicates

```yaml
transition:
  selection: sequential
  active:
    - kind: push
      duration-ms: 520
      angles: [0.0]
    - kind: wipe
      duration-ms: 520
      angles: [90.0]
    - kind: push
      duration-ms: 520
      angles: [180.0]
```

## Matting examples

### Single studio mat

```yaml
matting:
  active:
    - kind: studio
      minimum-mat-percentage: 3.5
      bevel-width-px: 4.0
```

### Weighted random palette with duplicates

```yaml
matting:
  selection: random
  active:
    - kind: fixed-color
      colors:
        - [0, 0, 0]
        - [32, 32, 32]
    - kind: fixed-color
      colors:
        - [210, 210, 210]
        - [240, 240, 240]
      minimum-mat-percentage: 6.0
    - kind: blur
      minimum-mat-percentage: 7.5
      sigma: 18.0
```

The first entry contributes two canonical slots (dark swatches), the second adds two more (light swatches), and the blur entry adds one slot. With `selection: random`, four out of five draws land on a solid mat; blur shows roughly 20% of the time.

### Sequential rotation with fixed-image

```yaml
matting:
  selection: sequential
  active:
    - kind: studio
      minimum-mat-percentage: 6.0
    - kind: fixed-image
      path: [/var/lib/photoframe/backgrounds/linen.png]
      fit: contain
    - kind: studio
      minimum-mat-percentage: 4.0
```

### Full-bleed for near-fit photos

```yaml
matting:
  fill-when-fits:
    maximum-crop-percentage: 5.0
    skip-matting-probability: 1.0
  selection: random
  active:
    - kind: fixed-color
      colors:
        - [0, 0, 0]
    - kind: blur
```

Photos within 5% of the display's aspect ratio fill the screen edge-to-edge with no mat; everything else rotates through the black swatch and blur mats as usual. Lower `skip-matting-probability` (for example `0.5`) to occasionally still mat the near-fit photos.

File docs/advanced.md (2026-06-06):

# Advanced

Optional and deeper-dive topics: cloud sync, Wi-Fi recovery internals, power/sleep model, memory tuning, and the kiosk stack.

---

## Cloud sync

The frame can keep `/var/lib/photoframe/photos/cloud/` in sync with cloud storage on a timer. Photos in `cloud/` appear in rotation alongside anything in `local/`. Everything below is optional — skip it if you only add photos manually.

### How it works

- The sync service downloads photos into `/var/lib/photoframe/photos/cloud/`.
- `/var/lib/photoframe/photos/local/` is never touched.
- `photoframe-sync.timer` triggers the sync (hourly default).
- The timer is **disabled by default**; it activates only after you configure a source.

Sync is safe while the frame is displaying photos: it stages downloads, then promotes them to `cloud/` in a single step. Unchanged files are hard-linked across staging and `cloud/`, so sync uses no extra disk space.

### Supported providers

The frame uses [rclone](https://rclone.org), which supports 40+ providers including Google Drive (`drive`), Dropbox (`dropbox`), S3 (`s3`), OneDrive (`onedrive`), Backblaze B2 (`b2`), iCloud Drive (`iclouddrive`), SFTP, WebDAV. Full list: `rclone help backends`.

For a NAS on your local network, you can use rsync directly — see [Using rsync instead](#using-rsync-instead).

### Setup

**1. Configure an rclone remote** on the Pi:

```bash
rclone config
```

The wizard walks through provider selection and OAuth (it prints a URL to authorize in a browser, then asks for the confirmation code). Verify when done:

```bash
rclone listremotes        # e.g. "gdrive:"
rclone ls gdrive:My\ Photos/Frame
```

**2. Copy the rclone config to the kiosk user.** rclone stores config at `~/.config/rclone/rclone.conf`. The wizard ran as your operator user, but the sync service runs as `kiosk`:

```bash
sudo mkdir -p /home/kiosk/.config/rclone
sudo cp ~/.config/rclone/rclone.conf /home/kiosk/.config/rclone/rclone.conf
sudo chown -R kiosk:kiosk /home/kiosk/.config/rclone
```

**3. Set the sync source.** Edit `/etc/photoframe/sync.env`:

```bash
sudo nano /etc/photoframe/sync.env
```

Uncomment and set:

```bash
RCLONE_REMOTE=gdrive:My Photos/Frame
```

Format is `remote-name:path` — the remote name must exactly match `rclone listremotes`.

**4. Test a manual sync:**

```bash
sudo systemctl start photoframe-sync.service
sudo journalctl -u photoframe-sync.service -f
ls /var/lib/photoframe/photos/cloud/
```

**5. Enable the hourly timer:**

```bash
sudo systemctl enable --now photoframe-sync.timer
systemctl list-timers photoframe-sync.timer
```

### Changing the sync schedule

```bash
sudo systemctl edit photoframe-sync.timer
```

Add (replacing `OnCalendar=` with your schedule):

```ini
[Timer]
OnCalendar=
OnCalendar=*-*-* 02:00:00
```

The empty `OnCalendar=` clears the default before applying yours. Common values:

| Schedule | `OnCalendar=` |
| --- | --- |
| Every hour (default) | `hourly` |
| Every 15 minutes | `*:0/15` |
| Once a day at 2 AM | `*-*-* 02:00:00` |
| Twice a day | `*-*-* 06,18:00:00` |

### Using rsync instead

```bash
sudo nano /etc/photoframe/sync.env
```

Set:

```bash
SYNC_TOOL=rsync
RSYNC_SOURCE=user@nas.local:/photos/frame/
# RSYNC_FLAGS=-av --delete  # optional override
```

The Pi must be able to SSH to the source without a password. Set up a key for the `kiosk` user:

```bash
sudo -u kiosk ssh-keygen -t ed25519 -N "" -f /home/kiosk/.ssh/id_ed25519
sudo -u kiosk ssh-copy-id user@nas.local
```

### Sync troubleshooting

| Symptom | Likely cause | Fix |
| --- | --- | --- |
| `RCLONE_REMOTE must be set` in logs | `sync.env` not configured | Edit `/etc/photoframe/sync.env` |
| `Failed to create file system for ... not found` | Remote name wrong | `rclone listremotes`; check spelling |
| `directory not found` | Path doesn't exist | `rclone lsd gdrive:` to list folders |
| Auth errors / token expired | OAuth token needs refresh | `rclone config reconnect gdrive:` as operator, then copy config to kiosk |
| Photos don't appear after sync | Wrong file format | Only JPEG and PNG; `rclone ls` to verify types |
| `permission denied` writing to `cloud/` | Permissions issue | `sudo chown -R kiosk:kiosk /var/lib/photoframe/photos/cloud` |

If you configured rclone as your operator user but the service runs as `kiosk`, the most common issue is the rclone config not being present for `kiosk` — copy it as in step 2.

---

## Wi-Fi recovery

`wifi-manager` is the frame's single entry point for Wi-Fi monitoring, hotspot recovery, and captive-portal provisioning. It wraps NetworkManager's `nmcli`, spawns the recovery web UI, and persists operational breadcrumbs under `/var/lib/photoframe`.

### What it does

- Polls NetworkManager for the interface's connection state.
- Treats Wi-Fi as online when the interface is associated to an infrastructure SSID (link-level only — no internet reachability requirement).
- Creates/updates the `pf-hotspot` NetworkManager profile and brings it online with a random three-word passphrase.
- Serves an HTTP UI for SSID/password entry on `192.168.4.1:8080`, plus a QR code (`/var/lib/photoframe/wifi-qr.png`) phones can scan to jump to the portal.
- Uses Sway IPC to present a fullscreen overlay with hotspot instructions whenever Wi-Fi needs attention. Can also stop/relaunch the photo app (`app-handoff` mode).
- Emits structured logs for deterministic states (`Online`, `OfflineGrace`, `RecoveryHotspotActive`, `ProvisioningAttempt`, `RecoveryBackoff`).

### Subcommands

The deployed binary lives at `/opt/photoframe/bin/wifi-manager`:

| Subcommand | Purpose |
| --- | --- |
| `watch` | Default daemon. Monitors connectivity, raises hotspot/UI when offline, reconnects when provisioning succeeds. |
| `ui` | Runs only the HTTP UI server (auto-spawned by `watch`; useful for debugging). |
| `qr` | Generates `/var/lib/photoframe/wifi-qr.png`. |
| `nm` | Thin wrapper around `nmcli` operations. Safe to run manually for diagnostics. |
| `overlay` | Renders the on-device recovery overlay window. Auto-invoked by the watcher. |

`--help` and `--version` are permitted as root; all other modes refuse `UID==0`.

### Configuration

Template at `/opt/photoframe/etc/wifi-manager.yaml` (staged from `setup/assets/app/etc/wifi-manager.yaml`):

```yaml
interface: wlan0
check-interval-sec: 5
offline-grace-sec: 30
recovery-mode: app-handoff
recovery-reconnect-probe-sec: 300
recovery-connect-timeout-sec: 20
wordlist-path: /opt/photoframe/share/wordlist.txt
var-dir: /var/lib/photoframe
hotspot:
  connection-id: pf-hotspot
  ssid: PhotoFrame-Setup
  ipv4-addr: 192.168.4.1
ui:
  # Bind the recovery portal to the hotspot address so it is reachable only on
  # the recovery AP, never on the home LAN.  Leave unset to follow hotspot
  # ipv4-addr automatically; set 0.0.0.0 only for local testing.
  bind-address: 192.168.4.1
  port: 8080
photo-app:
  launch-command:
    - /usr/local/bin/photoframe
    - /etc/photoframe/config.yaml
  app-id: photoframe
overlay:
  command:
    - swaymsg
  photo-app-id: photoframe
  overlay-app-id: wifi-overlay
```

| Key | Description |
| --- | --- |
| `interface` | Wireless device monitored (default `wlan0`). |
| `check-interval-sec` | Base delay between connectivity probes; small jitter added internally. |
| `offline-grace-sec` | Seconds offline before the hotspot activates. |
| `recovery-mode` | `app-handoff` (default) stops/relaunches photo app; `overlay` keeps slideshow running under overlay. |
| `recovery-reconnect-probe-sec` | Seconds between auto-reconnect probes while hotspot mode is active. |
| `recovery-connect-timeout-sec` | Maximum wait for infrastructure association when applying credentials. |
| `wordlist-path` | Source of the random three-word passphrase. |
| `var-dir` | Runtime artifact directory. |
| `hotspot.connection-id` | NetworkManager profile name. |
| `hotspot.ssid` | Recovery hotspot SSID. |
| `hotspot.ipv4-addr` | Hotspot interface address. |
| `ui.bind-address`, `ui.port` | HTTP UI bind. |
| `photo-app.launch-command`, `photo-app.app-id` | Used in `app-handoff` mode. |
| `overlay.command`, `overlay.photo-app-id`, `overlay.overlay-app-id` | Sway IPC wiring for the overlay. |

After editing: `sudo systemctl restart photoframe-wifi-manager.service`.

### Runtime files

All under `/var/lib/photoframe`, owned by `kiosk`:

- `hotspot-password.txt` — current random passphrase for `PhotoFrame-Setup`
- `wifi-qr.png` — QR pointing to `http://<hotspot-ip>:<port>/`
- `wifi-request.json` — ephemeral credential request from `POST /submit` (mode `0600`)
- `wifi-last.json` — latest provisioning attempt record (inputs masked, result + timestamps)
- `wifi-state.json` — watcher state (`state`, `reason`, optional `attempt_id`)

### NetworkManager permissions

`wifi-manager` runs as `kiosk`. The setup pipeline installs `/etc/polkit-1/rules.d/90-photoframe-nm.rules` granting the kiosk group the NetworkManager actions needed to add, modify, and activate Wi-Fi profiles. Without this rule, manual `nm` subcommands fail with `Insufficient privileges`.

### Service management

```bash
sudo journalctl -u photoframe-wifi-manager.service -f          # tail logs
sudo systemctl restart photoframe-wifi-manager.service          # after config edit
/opt/photoframe/bin/print-status.sh                             # status summary
sudo -u kiosk /opt/photoframe/bin/wifi-manager nm add --ssid "HomeWiFi" --psk "secret"
sudo nmcli connection up pf-hotspot                             # force recovery hotspot for testing
```

For day-2 triage steps, see [Operate › Wi-Fi failure triage](operate.md#wi-fi-failure-triage).

### Disable wifi-manager

```bash
sudo systemctl stop photoframe-wifi-manager.service
sudo systemctl disable photoframe-wifi-manager.service
sudo systemctl mask photoframe-wifi-manager.service       # prevents setup scripts from re-enabling
sudo nmcli connection delete pf-hotspot || true            # optional: drop the hotspot profile
```

Re-enable: `sudo systemctl unmask photoframe-wifi-manager.service && sudo systemctl enable --now photoframe-wifi-manager.service`.

---

## Power and sleep

`buttond` owns wake/sleep scheduling and DPMS commands. Configuration is documented in [Configure › `buttond`](configure.md#buttond-power-button-daemon) — this section explains the model and the `powerctl` tool.

### Always-on vs. scheduled

- **No `awake-schedule`:** `buttond` keeps the frame awake at all times. Manual sleep/wake commands still work.
- **With `awake-schedule`:** `buttond` drives the frame between awake and asleep at each boundary, applying the schedule's current state after the greeting delay.

### powerctl

`/opt/photoframe/bin/powerctl` bootstraps the Wayland environment, issues `wlr-randr` DPMS requests, and falls back to `vcgencmd display_power`.

> `powerctl` must run as the `kiosk` user. It searches for a Wayland session owned by the running UID. Any other user produces "no sway process found for uid N".

```bash
sudo -u kiosk /opt/photoframe/bin/powerctl wake
sudo -u kiosk /opt/photoframe/bin/powerctl sleep
sudo -u kiosk /opt/photoframe/bin/powerctl wake HDMI-A-2   # explicit connector
```

When `buttond.screen.display-name` is set in config, `buttond` always passes it to `powerctl`. When omitted, `powerctl` auto-detects the first connected output.

### Manual overrides

Pipe JSON to the control socket to override the schedule temporarily:

```bash
echo '{"command":"set-state","state":"awake"}'  | sudo -u kiosk socat - UNIX-CONNECT:/run/photoframe/control.sock
echo '{"command":"set-state","state":"asleep"}' | sudo -u kiosk socat - UNIX-CONNECT:/run/photoframe/control.sock
echo '{"command":"toggle-state"}'               | sudo -u kiosk socat - UNIX-CONNECT:/run/photoframe/control.sock
```

Manual overrides persist until the next schedule boundary — the override clears the moment the schedule's own desired state matches it, at which point the frame resumes following the schedule. Pressing again toward the opposite state agrees with the schedule and clears the override immediately (a natural "undo"). Overrides are in-memory, so a `buttond` restart resets to schedule-following.

### Pi 5 + Dell S2725QC notes

- **Skip `/sys/class/backlight`** — external HDMI panels don't expose a kernel backlight; writing there is a no-op.
- **Primary method:** `wlr-randr --output <NAME> --off|--on` via `powerctl`.
- **Fallback:** `vcgencmd display_power 0|1` still works on Pi 5 KMS. Default `powerctl` chains both.
- **CEC:** the Dell S2725QC does not implement HDMI-CEC. `cec-ctl` cannot power it down.

---

## Memory tuning

How `photoframe` uses RAM at runtime, and how to tune it down.

### Budget by Pi model

The frame keeps several decoded frames in memory simultaneously (configurable via `viewer-preload-count`). On a 3840×2160 display with `oversample: 1.0`, a single RGBA image is ~33 MiB. With the default preload of 3 plus intermediate matting copies, steady-state can exceed 400 MiB before OS overhead.

| Pi RAM | OS + system | Available to frame | Default preload | Recommended oversample |
| --- | --- | --- | --- | --- |
| 2 GiB | ~500 MiB | ~1.5 GiB | reduce to 1 | 0.75 |
| 4 GiB | ~500 MiB | ~3.5 GiB | 3 (default) | 1.0 |
| 8 GiB | ~500 MiB | ~7.5 GiB | 4–5 | 1.0–1.5 |

Heavy matting (studio, blur, fixed-image) and large backgrounds increase usage. Monitor with:

```bash
ps -o pid,rss,vsz,comm -p $(pgrep photoframe)
# or in htop: F4 to filter by 'photoframe'
```

### Pipeline: where memory goes

1. **Loader decode buffer** — source decoded to raw RGBA. Channel between loader and viewer holds `viewer-preload-count` of these.
2. **Matting worker input** — clone of the decoded frame sent to the CPU matting pipeline.
3. **Matting output canvas** — full-screen RGBA canvas at display resolution × `oversample`. ~33 MiB per 4K frame.
4. **GPU upload staging** — padded staging buffer aligned for WGPU row requirements, held until upload completes.
5. **Fixed-image backgrounds** — each configured background is decoded once and cached at full canvas resolution indefinitely.

With three frames in flight, copies 1–4 stack across all three.

### Mitigation levers

Apply in order — each has diminishing returns:

**1. Reduce `viewer-preload-count`** (highest impact)

```yaml
viewer-preload-count: 1   # default 3
```

Cutting from 3 to 1 trims ~200 MiB on a 4K display. 1–2 still hides most decode latency on fast SD cards.

**2. Dial back `oversample`**

```yaml
global-photo-settings:
  oversample: 0.75   # default 1.0
```

Reduces every matting canvas and GPU texture by 44% (0.75² = 0.56).

**3. Cull large backgrounds.** Each `fixed-image` background is cached at full canvas resolution forever. A list of five 4K backgrounds adds ~165 MiB permanently. Keep the list short or pre-scale backgrounds.

**4. Switch to lighter matting styles.** `fixed-color` requires no intermediate copies. `blur` and `studio` are heavier. Disabling matting (`active: []`) is the most aggressive option.

**5. Constrain source resolution.** Pre-scale very large source photos (50 MP RAW exports) to display resolution before adding them.

### Profiling

```bash
watch -n 2 'ps -o pid,rss,vsz,comm -p $(pgrep photoframe)'
```

The footprint stabilizes after the first few transitions. Take a steady-state reading with the frame awake and cycling, then compare before and after each tuning change.

### What happens when memory runs out

The Linux OOM killer terminates processes. `photoframe` is not always the first target — `wireplumber` and others may go first. Signs of OOM: photos stop updating; `photoframe` exits and greetd restarts the session (greeting reappears); `dmesg` shows "Out of memory: Kill process".

```bash
sudo dmesg | grep -i "oom\|killed" | tail -20
sudo journalctl -t photoframe -n 100 | grep -i "killed\|error"
```

---

## Kiosk stack

The frame boots straight into the Wayland app via greetd on Debian 13 (Trixie). greetd launches a dedicated Sway session on tty1 and runs the photo frame as the `kiosk` user — no display manager shims or PAM templates.

### Provisioning

`sudo ./setup/system/install.sh` (called from `install-all.sh`) performs the kiosk-related actions:

- Verifies `/etc/os-release` reports `VERSION_CODENAME=trixie`.
- Applies Pi 5 boot tweaks (set `ENABLE_4K_BOOT=0` to skip the 4K60 profile).
- Installs Wayland/kiosk dependencies: `greetd`, `sway`, `swaybg`, `swayidle`, `swaylock`, `wayland-protocols`, `dbus`, `dbus-user-session`.
- Creates the locked `kiosk` user with `video`, `render`, `input`, and `seat` group membership (`seat` is required to access `/run/seatd.sock`).
- Provisions `/run/photoframe` as `kiosk:kiosk` mode `0770` plus a tmpfiles entry for boot-time creation.
- Installs `/usr/local/bin/photoframe-session`.
- Writes `/etc/greetd/config.toml` so tty1 runs `photoframe-session` as `kiosk`.
- Disables competing display managers (`gdm3`, `sddm`, `lightdm`), enables `greetd` as `display-manager`, and masks `getty@tty1.service`.
- Deploys the `photoframe-wifi-manager.service`, `buttond.service`, and `photoframe-sync.timer` units.

### Expected state

`/etc/greetd/config.toml`:

```toml
[terminal]
vt = 1

[default_session]
command = "/usr/local/bin/photoframe-session"
user = "kiosk"
```

- The wrapper launches Sway via `dbus-run-session`; `seatd.service` provides seat management (Sway connects to `/run/seatd.sock`).
- Sway config: `/usr/local/share/photoframe/sway/config`.
- `greetd` owns tty1; no autologin hacks.
- Launch chain: `greetd → photoframe-session → dbus-run-session → sway` (with `seatd.service` providing seat access via `/run/seatd.sock`).

### Verification

```bash
grep VERSION_CODENAME /etc/os-release
sudo systemctl status greetd
sudo systemctl status display-manager
sudo journalctl -u greetd -b
```

Expected: `greetd` reports `active (running)`; the unit command line includes `/usr/local/bin/photoframe-session`; the journal shows the kiosk session and slideshow startup.

### Idempotent reruns

Re-running provisioning after OS or app updates is supported. Idempotent status lines like `getty@tty1.service already masked; skipping disable/mask` are normal.

For deeper debug workflows (manual Sway launch, overlay tests, kiosk-shell environment export), see [developer/architecture.md › Debugging the kiosk stack](../developer/architecture.md#debugging-the-kiosk-stack).

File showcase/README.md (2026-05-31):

# Photo frame showcase

A self-maintaining tour that cycles through **every** registered transition and
mat, with each photo labeled in the bottom-left corner so you can map what you
see to a config key.

- **Config:** [`showcase.yaml`](showcase.yaml) — `showcase.enabled: true` with a
  4-second dwell and `startup-shuffle-seed: 1` for a reproducible run.
- **How it works:** when `showcase.enabled: true`, the frame ignores any
  `transition.active` / `matting.active` in the config and builds both lists
  automatically from its internal `TransitionKind::ALL` / `MattingKind::ALL`
  arrays. Adding a new effect to the frame automatically adds it to the tour —
  no manual edits required.

## Quick start (on the Pi)

```bash
# 1. Stage your media (use your own or grab the reference set — see "The photo set" below)
sudo install -d -o kiosk -g kiosk -m 0755 \
  /var/lib/photoframe/showcase/photos \
  /var/lib/photoframe/showcase/backgrounds
sudo cp /path/to/your/*.jpg /var/lib/photoframe/showcase/photos/
sudo cp /path/to/backdrop.jpg /var/lib/photoframe/showcase/backgrounds/background.jpg
sudo chown -R kiosk:kiosk /var/lib/photoframe/showcase

# 2. Activate (backs up your config, swaps in showcase.yaml, restarts the kiosk)
./showcase/activate.sh
#    watch it: journalctl -t photoframe -f

# 3. Restore your normal slideshow when done
./showcase/deactivate.sh
```

`activate.sh` creates the media directories for you (owned by the `kiosk`
service user) and warns if `photos/` is empty, so you can run it first and stage
photos after — but the slideshow stays empty until photos are present.

## Media locations

| Path | Purpose |
|---|---|
| `/var/lib/photoframe/showcase/photos/` | Slideshow photos. Must be readable by the `kiosk` service user — staging here (not under your home directory) avoids permission issues. |
| `/var/lib/photoframe/showcase/backgrounds/background.jpg` | Backdrop for the `fixed-image` mat. Kept outside `photos/` so it isn't shown as a slideshow photo. If absent, the `fixed-image` mat is simply skipped. |

## What the caption shows

Each frame displays a single line in the bottom-left, e.g.:

```
transition: crossfade-zoom    mat: passe-partout
```

When `fill-when-fits` triggers (a near-16:9 photo renders full-bleed), the mat
label reads `full-bleed`. Copy the names you like directly into your real
`config.yaml`.

## The photo set

Provide **9 photos** in `photos/`. The spread of aspect ratios is what makes the
mat showcase effective (portrait photos in a widescreen frame show the most mat).

| Count | Role | Aspect | Notes |
|---|---|---|---|
| 3 | **Fill** (full-bleed) | ≈ 16:9 (1.69–1.87) | render edge-to-edge with no mat |
| 4 | Portrait, matted | e.g. 2:3, 3:4, 4:5 | big pillarbox mats — the best mat showcase |
| 1 | Landscape, matted | ≈ 3:2 | close-ish but crops > 5%, so it shows the threshold declining a near-fit photo |
| 1 | **Panorama**, matted | extreme wide, e.g. 3:1 | best mat demo, and proves fill-when-fits declines wide photos |

Target balance: **4 landscape (3 fill + 1 matted) : 4 portrait : 1 panorama**.

A reference set with this exact spread is available as a release asset. Run
`showcase/download-photos.sh` to fetch it into `showcase/photos/` (already
gitignored), then copy from there when staging on the Pi.

For the `fixed-image` backdrop, use a 16:9 image ≥ 3840×2160 at
`backgrounds/background.jpg`.

## Turning off the caption

Set `showcase.caption: false` in `showcase.yaml` for a clean loop with no labels
(useful for screen-recordings of the effects), then re-run `./activate.sh`.

## Running locally (dev machine)

`make showcase` runs the tour against the path in `showcase.yaml`. That path
defaults to the Pi location `/var/lib/photoframe/showcase/photos`; for a local
run, copy `showcase.yaml` and point `photo-library-path` at a local folder, then
`cargo run -p photoframe -- your-local-showcase.yaml`. Note the frame needs a
Wayland/X compositor — it won't open a window from a bare SSH shell.

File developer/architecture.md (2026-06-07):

# Architecture & kiosk-stack debugging

How the provisioning pipeline is structured, and how to debug the kiosk stack on
a live Pi. For the test plan and release gate see [testing.md](testing.md).

---

## Setup script architecture

The provisioning pipeline lives under `setup/` and is fully idempotent — every stage can be re-run safely after OS updates or image refreshes.

### Standard deployment flow

```bash
./setup/install-all.sh                # all-in-one
./setup/tools/verify.sh               # post-install health check
sudo ./setup/system/tools/diagnostics.sh
```

`install-all.sh` provisions the OS (sudo), builds and deploys the app as your unprivileged user, and activates kiosk services. Set `CARGO_BUILD_JOBS` to cap build parallelism on low-memory devices.

### System provisioning (Trixie only)

```bash
sudo ./setup/system/install.sh
```

Run before building so toolchain and kiosk dependencies are ready. `install.sh` executes numbered modules under `setup/system/modules/`:

- `10-apt-packages.sh` — graphics stack, NetworkManager, Sway, build tools.
- `20-rust.sh` — system-wide Rust toolchain under `/usr/local/cargo`.
- `40-kiosk-user.sh` — locked `kiosk` user, runtime directories, polkit rule.
- `50-greetd.sh` — Sway session wrapper greetd launches on tty1.
- `60-systemd.sh` — `photoframe-wifi-manager.service`, `buttond.service`, `photoframe-sync.timer`.

Plus `dtoverlay=vc4-kms-v3d-pi5,cma-512` boot config for GPU CMA, swapfile replaced with `systemd-zram-generator` (half-RAM zram), Pi 5 firmware tweaks (`ENABLE_4K_BOOT=0` to skip the 4K60 profile).

### Application deployment

```bash
./setup/application/deploy.sh
```

Compiles the workspace, stages binaries and documentation under `setup/application/build/stage`, ensures the kiosk service user exists, and installs artifacts into `/opt/photoframe`. Modules:

- `10-build.sh` — compiles `wifi-manager`, `photoframe`, `buttond` in release mode (never as root).
- `20-stage.sh` — stages binaries, config templates, wordlist, and `docs/` content.
- `30-install.sh` — installs into `/opt/photoframe`; seeds `/etc/photoframe/config.yaml` if missing.

### Diagnostics

```bash
sudo ./setup/system/tools/diagnostics.sh
```

Inspects the greetd session, kiosk user, and display-manager wiring. Run from the device when display login fails or the kiosk session won't start.

### Shared systemd helper library

Provisioning and diagnostics scripts use `setup/lib/systemd.sh`. Source pattern:

```bash
SCRIPT_DIR="$(cd "$(dirname "${BASH_SOURCE[0]}")" && pwd)"
# shellcheck source=../lib/systemd.sh
source "${SCRIPT_DIR}/../lib/systemd.sh"
```

Helper groups:

- Availability and reload: `systemd_available`, `systemd_daemon_reload`
- Unit lifecycle: `systemd_enable_unit`, `systemd_start_unit`, `systemd_restart_unit`, `systemd_stop_unit`
- Enable/disable/mask: `systemd_enable_now_unit`, `systemd_disable_unit`, `systemd_disable_now_unit`, `systemd_mask_unit`, `systemd_unmask_unit`, `systemd_set_default_target`
- State checks: `systemd_unit_exists`, `systemd_is_active`, `systemd_is_enabled`, `systemd_status`, `systemd_unit_property`
- Unit/drop-in management: `systemd_install_unit_file`, `systemd_install_dropin`, `systemd_remove_dropins`

---

## Debugging the kiosk stack

For developer-only debugging on a live Pi when normal operator runbooks aren't enough.

### Manual debug launch (advanced)

In normal operation `photoframe` is started by greetd via `/usr/local/bin/photoframe-session`. For low-level debugging you can run a standalone Sway session as `kiosk`.

Prerequisite (one-time):

```bash
sudo loginctl enable-linger kiosk
```

Launch:

```bash
sudo -u kiosk \
  XDG_RUNTIME_DIR="/run/user/$(id -u kiosk)" \
  dbus-run-session \
  sway -c /usr/local/share/photoframe/sway/config
```

### Debugging without journald capture

Logs to stdout:

```bash
sudo -u kiosk \
  XDG_RUNTIME_DIR="/run/user/$(id -u kiosk)" \
  dbus-run-session \
  env PHOTOFRAME_LOG=stdout \
  env RUST_LOG='photoframe::tasks::viewer=debug,info' \
  sway -c /usr/local/share/photoframe/sway/config
```

Logs to file:

```bash
sudo -u kiosk \
  XDG_RUNTIME_DIR="/run/user/$(id -u kiosk)" \
  dbus-run-session \
  env PHOTOFRAME_LOG='file:/var/tmp/photoframe.log' \
  env RUST_LOG='photoframe::tasks::viewer=debug,info' \
  sway -c /usr/local/share/photoframe/sway/config

sudo tail -f /var/tmp/photoframe.log
```

### Overlay takeover test

Verify overlay focus/fullscreen behavior before Wi-Fi recovery testing.

One-time install:

```bash
sudo install -D -m 0755 developer/overlay-test.sh /usr/local/bin/overlay-test
sudo install -D -m 0644 developer/systemd/wifi-overlay-test.service /etc/systemd/system/wifi-overlay-test.service
sudo systemctl daemon-reload
```

Run:

```bash
sudo systemctl start wifi-overlay-test.service
sudo -u kiosk bash developer/overlay-test.sh status
sudo -u kiosk bash developer/overlay-test.sh hide
```

Troubleshooting:

- `systemctl status greetd` — Sway session up?
- `sudo sh -lc 'uid=$(id -u kiosk); ls "/run/user/$uid"/sway-ipc.*.sock'` — IPC socket present?
- `journalctl -u wifi-overlay-test.service -n 50 --no-pager`

### Kiosk shell with live Sway environment

Open an interactive shell as `kiosk` with compositor environment exported:

Stale `sway-ipc.*.sock` files from earlier sessions can linger in the runtime dir, so sort by mtime
(`-t`) and take the newest — not the lowest PID:

```bash
sudo sh -lc '
  uid=$(id -u kiosk)
  RUNDIR="/run/user/$uid"
  SWAYSOCK="$(ls -t "$RUNDIR"/sway-ipc.*.sock | head -1)"
  WAYLAND_DISPLAY="$(basename "$(ls -t "$RUNDIR"/wayland-* | head -1)")"
  exec sudo --preserve-env=RUNDIR,SWAYSOCK,WAYLAND_DISPLAY \
    -u kiosk env XDG_RUNTIME_DIR="$RUNDIR" SWAYSOCK="$SWAYSOCK" WAYLAND_DISPLAY="$WAYLAND_DISPLAY" bash -l
'
```

Inside that shell:

- Verify env: `echo "$XDG_RUNTIME_DIR" "$SWAYSOCK" "$WAYLAND_DISPLAY"`
- Test IPC: `swaymsg -s "$SWAYSOCK" -t get_tree >/dev/null && echo ok || echo fail`

### Manually simulate a Wi-Fi failure

`developer/suspend-wifi.sh` stashes the active profile keyfile, swaps in a Wi-Fi connection with a deliberately wrong PSK, and tries to activate it. Run from a multiplexer or with `nohup` so it survives SSH drops:

```bash
sudo nohup bash developer/suspend-wifi.sh wlan0 >/tmp/wifi-test.log 2>&1 & disown
```

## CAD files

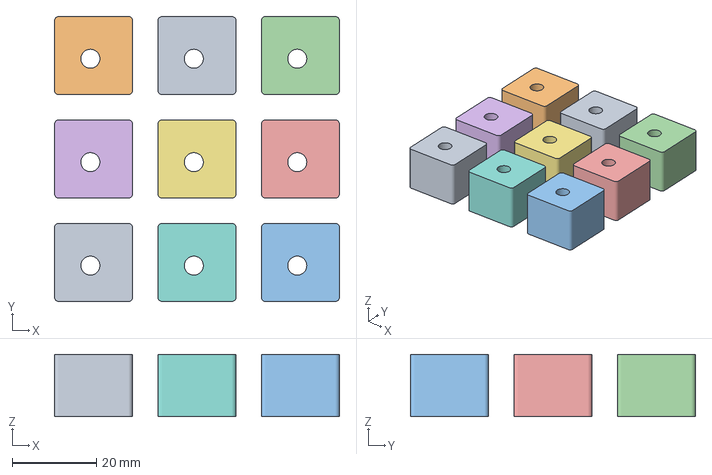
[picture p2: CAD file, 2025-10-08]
maker/cleat-spacers.3mf
67.5 x 67.5 x 14.8 mm
cleat-spacers.stl x 9

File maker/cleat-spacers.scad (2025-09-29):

// Simple blocks with a hole to space cleat on Dell S2725QC, OpenSCAD (units: mm)

// ----- Parameters you can tweak -----
corner_radius = 1.0;   // "slightly rounded corners" — adjust if you like
hole_d        = 4.5;   // hole diameter
edge_offset   = 11.0;  // distance of hole center from right/top edges

// Part specs
size1   = 17.0;   height1 = 10.75; // Part 1
size2   = 18.5;   height2 = 14.0;  // Part 2

$fn = 64; // smoothness for circles/cylinders

// ----- Helper: rounded square that ends up exactly 'size' × 'size' -----
module rounded_square(size, r=1.0) {
    // Build a size×size rounded rectangle by minkowski-expanding a smaller square
    // with a circle of radius r. The inner square is (size-2r).
    minkowski() {
        square(size - 2*r, center=false);
        circle(r=r);
    }
}

// ----- Helper: block with through-hole at (right/top) offsets -----
module block_with_hole(size, height, r, hole_dia, offset_rt) {
    difference() {
        // Main body
        linear_extrude(height)
            rounded_square(size, r);

        // Through-hole: 11 mm from right and 11 mm from top edges
        translate([size - offset_rt, size - offset_rt, -1])
            cylinder(h = height + 2, d = hole_dia);  // overshoot Z so it's definitely through
    }
}

// ----- Individual parts -----
module part1() block_with_hole(size1, height1, corner_radius, hole_d, edge_offset);
module part2() block_with_hole(size2, height2, corner_radius, hole_d, edge_offset);

// ----- Preview both (side-by-side). Comment one out to export STLs separately. -----
translate([0, 0, 0])      part1();
translate([max(size1,size2) + 10, 0, 0]) part2();

// To export:
// 1) Comment out the other part so only one remains visible.
// 2) Design -> Export -> Export as STL.

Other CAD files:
maker/cleat-spacers.stl

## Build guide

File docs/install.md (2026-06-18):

# Install

Blank microSD → running slideshow. Follow the steps in order.

**Time:** ~20 min active + 20–40 min unattended build on a Pi 5.

**Command context:** run as your operator account (e.g. `frame`) over SSH; use `sudo` where shown.

> **sudo requires your password.** Raspberry Pi OS no longer configures passwordless sudo. Every `sudo` command in this guide will prompt for the password you set during imaging. Enter it once — your session caches it for ~15 minutes, so subsequent `sudo` calls won't re-prompt.

---

## Two accounts you'll meet

- **Operator account** (e.g. `frame`) — your SSH login. You use this for maintenance, `sudo`, and `scp`.
- **Service account** (`kiosk`) — runs greetd, Sway, the photo app, the Wi-Fi manager, and `buttond`. You'll need `sudo -u kiosk` for anything that touches the Wayland session (`powerctl`, `socat` to the control socket).

---

## Prepare an SSH key

Raspberry Pi Imager wants a public key during setup:

```bash
ls ~/.ssh/id_*.pub
# or generate one:
ssh-keygen -t ed25519 -f ~/.ssh/photoframe -C "frame@photoframe.local"
```

Optional shortcut in `~/.ssh/config`:

```
Host photoframe
    HostName photoframe.local
    User frame
    IdentityFile ~/.ssh/photoframe
    IdentitiesOnly yes
```

---

## Step 1 — Flash the SD card

1. Install [Raspberry Pi Imager](https://www.raspberrypi.com/software/).
2. Insert your microSD; launch the imager.
3. **Choose Device:** Raspberry Pi 5
4. **Choose OS:** Raspberry Pi OS (64-bit) — the **Trixie** (Debian 13) build.
5. **Choose Storage:** your microSD.
6. **Edit Settings**:
   - Hostname: `photoframe`
   - Username/password: create a dedicated user (e.g. `frame`) with a strong password — **this password is required even with key-only SSH** because `sudo` authenticates against it
   - Configure Wireless LAN: SSID, passphrase, country code
   - Set locale, timezone, keyboard
7. **Services**: enable SSH → **Allow public-key authentication only** → paste your public key.
8. **Save → Yes → Write** and wait for verification.

---

## Step 2 — First boot and OS check

1. Insert the SD card, connect the display, power on.
2. Wait ~1 minute for Wi-Fi association, then SSH:

   ```bash
   ssh -i ~/.ssh/photoframe frame@photoframe.local
   ```

3. Confirm the OS — the setup scripts require Trixie:

   ```bash
   grep VERSION_CODENAME /etc/os-release    # must say trixie
   ```

4. Update packages:

   ```bash
   sudo apt update && sudo apt upgrade -y
   ```

---

## Step 3 — Clone and install

```bash
sudo apt install -y git
git clone https://github.com/vincentl/rust-photo-frame.git photoframe
cd photoframe
./setup/install-all.sh
```

The script uses `sudo` internally for system-level steps (your credential is still cached from Step 2 — no extra prompt). It:

- Installs system packages (graphics stack, NetworkManager, Sway, greetd, build tools) and a system-wide Rust toolchain.
- Stages a bootloader EEPROM update if one is available (older Pi 5 bootloaders reduce GPU memory bandwidth by ~35%; the staged update applies on the next reboot).
- Builds the four crates (`photoframe`, `buttond`, `wifi-manager`, `config-model`).
- Provisions the `kiosk` user, polkit rules, runtime directories, zram swap, and Pi 5 boot tweaks.
- Installs binaries, unit files, and a starter config to `/opt/photoframe`.
- Wires up greetd on tty1 and starts the kiosk session, Wi-Fi watcher, and `buttond`.

> **Build killed with `signal: 9`?** The Rust build ran out of memory. Cap parallelism: `CARGO_BUILD_JOBS=2 ./setup/install-all.sh`.

When the script returns, **reboot once** (`sudo reboot`) so any staged bootloader update takes effect, then SSH back in — this also picks up the `kiosk` group membership added during setup. Then verify:

```bash
exit
ssh -i ~/.ssh/photoframe frame@photoframe.local
cd photoframe
./setup/tools/verify.sh
```

You should see all checks green. Warnings appear yellow; errors red.

### What got installed where

```txt
/opt/photoframe/       Read-only runtime: binaries, unit files, config templates
/var/lib/photoframe/   Writable state: photos, hotspot artifacts, runtime files
/etc/photoframe/       Active configuration (edit this with sudo)
```

Re-running the installer updates `/opt/photoframe` without touching `/etc/photoframe/config.yaml` or your photo library.

The first install seeds `/etc/photoframe/config.yaml` from the repo's rich default `config.yaml`. To start from a different baseline (a minimal file, the showcase tour, or the everything kitchen-sink), copy one from [`examples/`](../examples/README.md) over it and restart the kiosk.

---

## Step 4 — Add your photos

Photos live under `/var/lib/photoframe/photos`, scanned recursively. Use the `local/` subdirectory for manual imports (the `cloud/` subdirectory is reserved for the optional sync service).

From your laptop, use `rsync` (not `scp` — the sftp subsystem doesn't load supplementary groups, so `scp` writes silently fail):

```bash
rsync -a -e "ssh -i ~/.ssh/photoframe" /path/to/photos/ frame@photoframe.local:/var/lib/photoframe/photos/local/
```

Or locally on the Pi:

```bash
cp /path/to/photos/* /var/lib/photoframe/photos/local/
```

Confirm:

```bash
find /var/lib/photoframe/photos -type f | wc -l
```

**Supported formats:** JPEG, PNG. Other formats are silently skipped.

**Custom mat backgrounds:** drop JPEG/PNG files into `/var/lib/photoframe/backgrounds/`, then uncomment the `fixed-image` block in `/etc/photoframe/config.yaml`. See [Configure](configure.md).

---

## Step 5 — First boot: what to expect

When everything is working, the display goes through these states in order:

1. **Blank** (a few seconds) — greetd is launching Sway and handing off the compositor.
2. **Greeting card** ("Warming up your photo memories…", a few seconds) — the app is scanning the library and pre-decoding the first images.
3. **Display goes dark — this is normal.** After the greeting the frame enters sleep state. The process is running, the GPU is idle, and it's waiting for either a wake command or a scheduled wake window.
4. **Photos cycle** — once awake, the slideshow begins.

### Wake the frame

Send a JSON command over the Unix control socket:

```bash
echo '{"command":"set-state","state":"awake"}' \
  | sudo -u kiosk socat - UNIX-CONNECT:/run/photoframe/control.sock
```

Photos should begin cycling within a few seconds.

### Confirm it's healthy

```bash
sudo systemctl status greetd photoframe-wifi-manager buttond
```

All three should report `active (running)`. Live photo logs:

```bash
sudo journalctl -t photoframe -f
```

Healthy output:

```
photoframe: scanning /var/lib/photoframe/photos
photoframe: found 42 photos
photoframe: loaded sunset.jpg (3840x2160)
photoframe: displaying photo 3 of 42
photoframe: transition fade 450ms
```

If the greeting never appeared at all, see [Operate › Troubleshooting](operate.md#black-screen-from-the-start--no-greeting-ever-appears).

### Always-on operation

Leave `awake-schedule` commented out in `/etc/photoframe/config.yaml` (the default) and the frame stays awake until you explicitly send a sleep command. To run on a schedule, see [Configure › Wake/sleep control](configure.md#wakesleep-control).

---

## Step 6 (optional) — Cloud photo sync

The installer ships a disabled `photoframe-sync` service that pulls photos from a cloud provider or NAS into `/var/lib/photoframe/photos/cloud/` on a timer. See [Advanced › Cloud sync](advanced.md#cloud-sync) for the full guide.

---

## Step 7 (optional) — Remote administration

SSH key auth over LAN is the recommended baseline. For access outside your network:

- **Tailscale** — private mesh with stable hostnames across NAT
- **Raspberry Pi Connect** — browser-based remote access

Keep direct LAN SSH as a fallback so you can recover if the remote agent goes down.

---

## First-install troubleshooting

| Symptom | Likely cause | Quick fix |
| --- | --- | --- |
| Build killed with `signal: 9` | OOM during Rust build | `CARGO_BUILD_JOBS=2 ./setup/install-all.sh` |
| `VERSION_CODENAME` is not `trixie` | Wrong OS image | Re-flash with Raspberry Pi OS (64-bit) Trixie |
| `verify.sh` reports failures | Service didn't start | `sudo systemctl status greetd` and check `journalctl -u greetd -b` |
| Screen dark after greeting | Frame in sleep state — normal | Send the wake command from Step 5 |
| Permission denied writing photos | New `kiosk` group not picked up by SSH session | `exit`, then SSH back in |

For anything else, see [Operate › Troubleshooting](operate.md#troubleshooting).

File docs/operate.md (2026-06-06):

# Operate

Day-to-day commands, status checks, and troubleshooting for a frame you own and maintain.

> Run commands from your operator SSH session unless noted. `sudo -u kiosk` is required for anything that touches the Wayland session (`powerctl`, `socat` to the control socket from a root shell).

---

## Command cheat sheet

### Control the frame

| What you want | Command |
| --- | --- |
| Wake (start cycling) | `echo '{"command":"set-state","state":"awake"}' \| sudo -u kiosk socat - UNIX-CONNECT:/run/photoframe/control.sock` |
| Sleep (stop cycling, blank) | `echo '{"command":"set-state","state":"asleep"}' \| sudo -u kiosk socat - UNIX-CONNECT:/run/photoframe/control.sock` |
| Toggle wake ↔ sleep | `echo '{"command":"toggle-state"}' \| sudo -u kiosk socat - UNIX-CONNECT:/run/photoframe/control.sock` |
| Screen on (DPMS) | `sudo -u kiosk /opt/photoframe/bin/powerctl wake` |
| Screen off (DPMS) | `sudo -u kiosk /opt/photoframe/bin/powerctl sleep` |
| Screen on, explicit output | `sudo -u kiosk /opt/photoframe/bin/powerctl wake HDMI-A-2` |

### Check status

| What you want | Command |
| --- | --- |
| Quick health check | `./setup/tools/verify.sh` |
| Full status summary | `/opt/photoframe/bin/print-status.sh` |
| Live photo logs | `sudo journalctl -t photoframe -f` |
| Wi-Fi manager logs | `sudo journalctl -u photoframe-wifi-manager.service -f` |
| Button daemon logs | `sudo journalctl -u buttond.service -f` |
| All service status | `sudo systemctl status greetd photoframe-wifi-manager buttond` |
| Count photos in library | `find /var/lib/photoframe/photos -type f \| wc -l` |
| List display outputs | `sudo -u kiosk env XDG_RUNTIME_DIR=/run/user/$(id -u kiosk) WAYLAND_DISPLAY=wayland-1 wlr-randr` |
| Check control socket | `sudo ls -l /run/photoframe/control.sock` |

### Manage

| What you want | Command |
| --- | --- |
| Restart kiosk (reliable) | `sudo systemctl stop greetd.service && sleep 1 && sudo systemctl start greetd.service` |
| Edit config | `sudo nano /etc/photoframe/config.yaml` |
| Apply config changes | restart kiosk (above) |
| Add photos from laptop | `rsync -a -e ssh /path/to/photos/ frame@photoframe.local:/var/lib/photoframe/photos/local/` |
| Add photos locally | `sudo cp /path/*.jpg /var/lib/photoframe/photos/local/ && sudo chown kiosk:kiosk /var/lib/photoframe/photos/local/*` |
| Trigger manual cloud sync | `sudo systemctl start photoframe-sync.service` |
| Update software | `git pull && ./setup/application/deploy.sh` |

> **Don't use `systemctl restart greetd`** — it can race with logind seat handoff on tty1 and leave the session in a bad state. Always stop, sleep, then start.

### Diagnose

| What you want | Command |
| --- | --- |
| Last 50 photo logs | `sudo journalctl -t photoframe -n 50 --no-pager` |
| Logs since boot | `sudo journalctl -t photoframe -b --no-pager` |
| Wi-Fi state | `sudo cat /var/lib/photoframe/wifi-state.json` |
| Check swap | `swapon --show` |
| Collect log bundle | `tests/collect_logs.sh` |
| Run diagnostics script | `sudo ./setup/system/tools/diagnostics.sh` |

---

## Daily operations

### Running the showcase

The showcase is a labeled tour of every transition and mat so you can choose which to configure. See [showcase/README.md](../showcase/README.md) for the full guide and photo setup.

```bash
# 1. Stage media (once)
sudo install -d -o kiosk -g kiosk -m 0755 \
  /var/lib/photoframe/showcase/photos /var/lib/photoframe/showcase/backgrounds
sudo cp /path/to/*.jpg /var/lib/photoframe/showcase/photos/
sudo cp /path/to/backdrop.jpg /var/lib/photoframe/showcase/backgrounds/background.jpg
sudo chown -R kiosk:kiosk /var/lib/photoframe/showcase

# 2. Activate (backs up config, swaps in showcase.yaml, restarts the kiosk)
./showcase/activate.sh
journalctl -t photoframe -f          # watch the tour

# 3. Restore your normal slideshow
./showcase/deactivate.sh
```

### Daily health check

```bash
./setup/tools/verify.sh
/opt/photoframe/bin/print-status.sh
sudo systemctl status greetd photoframe-wifi-manager buttond
```

Expected: all three services `active (running)`, `print-status.sh` exits cleanly.

### Reading the photo logs

`sudo journalctl -t photoframe -f` shows the slideshow loop:

| Line pattern | Meaning |
| --- | --- |
| `loaded <path>` | A photo was decoded and queued |
| `displaying photo N of M` | Active cycling |
| `transition <kind> <duration>ms` | GPU transition started |
| `invalid photo <path>` | Decode failed; that file is skipped until restart |
| `state change: asleep → awake` | Frame received a wake command |
| `schedule: sleeping until HH:MM` | `buttond` put the frame to sleep based on schedule |

### Adding photos

Both `local/` (manual imports, never overwritten by sync) and `cloud/` (managed by the sync service) under `/var/lib/photoframe/photos` are scanned recursively. Supported formats: JPEG, PNG.

From your laptop, use `rsync` (not `scp` — the sftp subsystem doesn't load supplementary groups, so `scp` writes silently fail):

```bash
rsync -a -e "ssh" /path/to/photos/ frame@photoframe.local:/var/lib/photoframe/photos/local/
# With a non-default key:
rsync -a -e "ssh -i ~/.ssh/photoframe" /path/to/photos/ frame@photoframe.local:/var/lib/photoframe/photos/local/
```

Or locally on the Pi:

```bash
sudo cp /path/to/photos/*.jpg /var/lib/photoframe/photos/local/
sudo chown kiosk:kiosk /var/lib/photoframe/photos/local/*.jpg
```

If you get **permission denied** during `rsync`, your SSH session predates the install (which added your account to the `kiosk` group). Log out and reconnect.

### Editing configuration

Edit `/etc/photoframe/config.yaml` (not the template at `/opt/photoframe/etc/photoframe/config.yaml` — that's overwritten on redeploy). Restart the kiosk to apply changes. See [Configure](configure.md) for the full reference.

### Updating the software

```bash
cd ~/photoframe
git pull
./setup/application/deploy.sh
```

`deploy.sh` builds in the background and restarts services at the end. `/etc/photoframe/config.yaml` and `/var/lib/photoframe/` are untouched. If the update includes system-level changes (new packages, unit changes), run the full installer instead:

```bash
./setup/install-all.sh
```

### Triggering a manual cloud sync

If `photoframe-sync.timer` is enabled, it runs automatically. To trigger now:

```bash
sudo systemctl start photoframe-sync.service
sudo journalctl -u photoframe-sync.service -f
```

Check the next scheduled run: `systemctl list-timers photoframe-sync.timer`. To set up cloud sync for the first time, see [Advanced › Cloud sync](advanced.md#cloud-sync).

### Wi-Fi recovery validation

After a fresh install, confirm Wi-Fi recovery works *before* mounting the frame:

```bash
make -f tests/Makefile wifi-recovery
```

If your SSH session is over `wlan0`, run inside `tmux` so it survives the test disconnecting Wi-Fi:

```bash
tmux new -s wifi-recovery
ALLOW_WIFI_SSH_DROP=1 make -f tests/Makefile wifi-recovery
# After reconnect:
tmux attach -t wifi-recovery
```

For deeper Wi-Fi behavior, see [Advanced › Wi-Fi recovery](advanced.md#wi-fi-recovery).

---

## Troubleshooting

### Screen shows greeting then goes black

**This is the most common first-boot surprise — it's not a crash.** After the greeting the frame enters sleep state. The GPU is idle and the display blanks. The frame is waiting for a wake command or a schedule window.

```bash
echo '{"command":"set-state","state":"awake"}' \
  | sudo -u kiosk socat - UNIX-CONNECT:/run/photoframe/control.sock
```

If you have an `awake-schedule` configured, also check that the current local time falls inside a wake window and that the timezone is correct. An empty list for a day key (e.g. `friday: []`) means **sleep all day on that day** — delete the key to fall back to `daily`.

### `powerctl wake` returns "no sway process found for uid N"

`powerctl` looks for a Wayland session owned by the running UID. The kiosk session belongs to `kiosk`, not your operator account. Always run with `sudo -u kiosk`:

```bash
sudo -u kiosk /opt/photoframe/bin/powerctl wake
```

### No photos cycling after the frame wakes

1. **Library empty?** `find /var/lib/photoframe/photos -type f | head -20` — add photos if it returns nothing.
2. **Permission error?** If you copied as root, `sudo chown -R kiosk:kiosk /var/lib/photoframe/photos/`.
3. **Unsupported format?** Only JPEG and PNG decode; check `sudo journalctl -t photoframe -n 50 --no-pager` for `invalid photo` lines.

### Black screen from the start — no greeting ever appears

The kiosk session (greetd + Sway) didn't start.

```bash
sudo systemctl status greetd.service
sudo journalctl -u greetd.service -b --no-pager | tail -40
```

Re-run the deploy: `./setup/application/deploy.sh`. greetd may not fully initialize without an active HDMI signal — confirm the display is connected and powered on before booting.

### Frame wakes or sleeps at the wrong time

Most often a misconfigured `awake-schedule`. Check:

- `timezone` is a valid IANA name (`America/New_York`, `Europe/London`, etc.). Wrong timezones fire boundaries at unexpected local times.
- A `day-of-week: []` entry (e.g. `friday: []`) means **sleep all day**. Delete the key to fall back to `daily`.
- The `daily` window is the default when no specific day key matches.

Restart `buttond` after editing: `sudo systemctl restart buttond.service`. `buttond` logs each evaluation — `sudo journalctl -u buttond.service -f` shows the next boundary.

### Build fails with "signal: 9" / "killed"

OOM during the Rust build. Common on Pi 4, rare on Pi 5.

```bash
CARGO_BUILD_JOBS=2 ./setup/install-all.sh
# or, deploy only:
CARGO_BUILD_JOBS=2 ./setup/application/deploy.sh
```

Verify swap: `swapon --show` should list `zram0`. If missing, re-run `sudo ./setup/system/install.sh`.

### Install fails: "OS codename must be trixie"

Setup requires Debian 13. Re-flash with the Trixie 64-bit Raspberry Pi OS image. See [Install › Step 1](install.md#step-1--flash-the-sd-card).

### Wi-Fi provisioning hotspot never appears

When the frame loses Wi-Fi, it should raise the `PhotoFrame-Setup` hotspot after about 30 seconds.

```bash
sudo systemctl status photoframe-wifi-manager.service
sudo journalctl -u photoframe-wifi-manager.service -f
```

If the service is stopped: `sudo systemctl start photoframe-wifi-manager.service`. If it's running but no hotspot appears, confirm the configured interface matches your hardware:

```bash
grep '^interface:' /opt/photoframe/etc/wifi-manager.yaml
nmcli -t -f DEVICE,TYPE,STATE device status
```

Wait the full grace period (30 s default) after disconnecting. For deeper Wi-Fi triage, see [Advanced › Wi-Fi recovery](advanced.md#wi-fi-recovery).

### Wi-Fi failure triage

When recovery is stuck, gather artifacts before changing anything:

1. `/opt/photoframe/bin/print-status.sh`
2. ```bash
   sudo cat /var/lib/photoframe/wifi-state.json
   sudo cat /var/lib/photoframe/wifi-last.json
   sudo ls -l /var/lib/photoframe/wifi-request.json
   ```
3. ```bash
   nmcli dev status
   nmcli connection show --active
   ```
4. Confirm Sway socket exists for kiosk:
   ```bash
   sudo sh -lc 'uid=$(id -u kiosk); ls "/run/user/$uid"/sway-ipc.*.sock'
   ```
5. Try the manual credential apply path:
   ```bash
   sudo -u kiosk /opt/photoframe/bin/wifi-manager nm add --ssid "<ssid>" --psk "<password>"
   ```
6. Collect a log bundle:
   ```bash
   tests/collect_logs.sh
   sudo journalctl -u photoframe-wifi-manager.service --since "15 min ago" --no-pager
   ```

If step 5 reports `Insufficient privileges`, re-run provisioning to reinstall the polkit rule.

### Cannot write photos to `/var/lib/photoframe/photos`

Your operator account was added to the `kiosk` group during install, but your current SSH session predates that change.

```bash
exit
ssh frame@photoframe.local
groups   # should now include "kiosk"
```

### Monitor stays on but photos freeze or stop updating

Likely an OOM kill. Check:

```bash
sudo journalctl -t photoframe -n 100 --no-pager | grep -i "killed\|oom\|memory"
sudo dmesg | grep -i "oom\|killed" | tail -20
```

To reduce memory use, edit `/etc/photoframe/config.yaml`:

```yaml
viewer-preload-count: 1    # was 3
global-photo-settings:
  oversample: 0.75         # was 1.0
```

Restart the kiosk after editing. See [Advanced › Memory tuning](advanced.md#memory-tuning) for a full budget breakdown.

### Display power commands run but the monitor stays on

Output name mismatch. Find the connector:

```bash
# wlr-randr must run in the kiosk Wayland session (display is usually wayland-1;
# find it with: sudo ls /run/user/$(id -u kiosk)/wayland-*)
sudo -u kiosk env XDG_RUNTIME_DIR=/run/user/$(id -u kiosk) WAYLAND_DISPLAY=wayland-1 wlr-randr
```

Update `buttond.screen.display-name` in `/etc/photoframe/config.yaml` to match (e.g. `HDMI-A-2`), then `sudo systemctl restart buttond.service`. See [Advanced › Power and sleep](advanced.md#power-and-sleep).

### `socat` command not found

```bash
sudo apt install -y socat
```

### `verify.sh` reports warnings about greetd

On a first deploy, `verify.sh` may warn about greetd if system provisioning was not yet complete. Re-run both stages:

```bash
sudo ./setup/system/install.sh
./setup/application/deploy.sh
./setup/tools/verify.sh
```

### Collect logs for a bug report

```bash
tests/collect_logs.sh
sudo journalctl -t photoframe --since "30 min ago" --no-pager > /tmp/photoframe.log
sudo journalctl -u photoframe-wifi-manager.service --since "30 min ago" --no-pager >> /tmp/photoframe.log
```

Attach both outputs when filing an issue.

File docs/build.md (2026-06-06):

# Build the Frame

> ## ⚠️ Safety & Disclaimer — Read Before You Build ⚠️
>
> This project involves 🔥 **heat and fire risk**, ⚡ **mains electrical work**, and 🛠️ **power tools** (laser cutter, table/miter saw, drill). It also describes 🧱 **mounting a heavy display on a wall**, which can fall and cause serious injury or death if improperly secured.
>
> - 🔥 **Thermals / fire:** A powered display sealed in a wooden enclosure is a long-term fire hazard if ventilation or cooling is inadequate. Do not leave it running unattended until you have verified safe sustained operating temperatures.
> - ⚡ **Electrical:** Mains wiring and outlet work must comply with your local electrical code and may legally require a licensed electrician and/or a permit. If in doubt, hire a professional.
> - 🧱 **Mounting:** Anchor the wall mount to structural framing rated for the load. Verify your fasteners, anchors, and wall type — a falling display can injure or kill.
> - 📏 **Your hardware differs:** Component specs, VESA depth, monitor power delivery, and dimensions vary between builds. Re-verify every measurement, clearance, and electrical assumption against **your** parts before cutting, drilling, or powering on.
>
> This guide is provided **"as is," without warranty of any kind**, express or implied. **You assume all risk.** The author(s) accept **no liability** for any injury, death, property damage, or loss arising from building, using, modifying, or relying on this project. By proceeding you accept full responsibility for your own safety and for compliance with all applicable laws and codes.

---

## Bill of materials

**Display & Compute**

| Item | Spec / Notes |
| --- | --- |
| Monitor | Dell 27" 4K, model S2725QC. Portrait-capable, USB-C with PD (powers the Pi), 100mm VESA. |
| Raspberry Pi 5 | 4GB handles 1080p with effects; 8GB recommended for 4K with heavy matting. Pi 4 is untested. |
| Active cooler for Raspberry Pi 5 | GeeekPi aluminum heatsink and cooling fan, or similar. |
| Power expansion board for Raspberry Pi 5 | GeeekPi with Always-ON switch & automatic startup, or similar. |
| microSDXC card | 32GB+ high-endurance recommended for always-on writes; SanDisk 128GB Extreme or similar. |

**Cabling & Controls**

| Item | Spec / Notes |
| --- | --- |
| 4K HDMI cable | Short (≤1m), high-quality; this build uses a 50cm cable with a 90° right-angle micro-HDMI connector. |
| USB-C cable | 6 inch. Powers the Pi from the monitor's USB-C PD port. |
| Momentary pushbutton | Optional; with 2-pin connector. Wires to the Pi 5 J2 power pads for hardware wake/sleep — see [Power button wiring](#power-button-wiring). |
| 2-pin header, right angle | Soldered to the Raspberry Pi J2 power button pads. |

**Frame — Wood & Joinery**

| Item | Spec / Notes |
| --- | --- |
| Birch plywood | Ripped to 2.625″-wide strips for the frame box. |
| Oak stock | ¼″ × 3.5″ × 48″, ripped to ¼″ × 1.625″ strips for the face frame. |
| Pocket screws | Two per joint. |
| Wood glue | Titebond III or similar. |
| Adhesive felt | 2″-wide roll, cut to thin strips. |

**Finish**

| Item | Spec / Notes |
| --- | --- |
| Flat black spray paint | Coats the plywood box.  |
| Paint or stain | For the oak face frame. |

**Mounting & Hardware**

| Item | Spec / Notes |
| --- | --- |
| Poplar 1×3 stock | Ripped at 45° for the French cleat; a same-thickness block serves as the bottom-VESA spacer. |
| Laser-cut mounting bracket | 1.5mm black acrylic Raspberry Pi bracket. SVG design in [`../maker/`](../maker/). |
| 3D-printed spacer blocks | PETG; space the wood cleat off the top VESA points. STL in [`../maker/`](../maker/). |
| M4 × 40mm flat-head cap screws (×4) | Through cleat/spacer into the VESA mount; verify length against VESA requirements. |
| M2.5 spacers and standoffs | Stack power hat over fan; machine screws fasten the bracket to the standoffs. |
| Cleat-to-wall fasteners | Wood/lag screws into studs (or wall anchors) to hang the French cleat. |
| Assorted screws | Flat-head wood screws, machine screws. |

---

## Power button wiring

The button is **optional**. The frame can be controlled entirely over SSH or via a wake/sleep schedule. If you want a physical button:

**What to use:** a normally-open momentary pushbutton (6mm tactile or a panel-mount button).

**Where it goes:** the Raspberry Pi 5 has a dedicated 2-pin **power button header (J2)** near the USB-C inlet. This is _not_ a GPIO pin — it's the same circuit as the button on the official Pi 5 case. Wire your button across pins 1 and 2 of J2. No resistors or capacitors needed; debouncing is handled in software by `buttond`. In the reference build a right-angle 2-pin header is soldered to the J2 pads and the momentary button connects to it with a dupont lead.

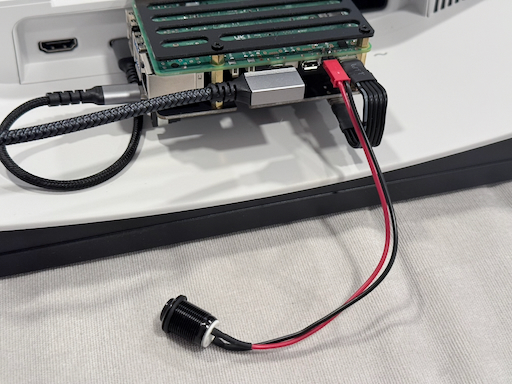
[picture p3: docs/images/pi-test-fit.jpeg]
Raspberry Pi 5 mounted on the monitor back with red and black wires running to a momentary button


**What it does:**

| Monitor State | Press | Action |
| --- | --- | --- |
| On | Single press | `buttond` toggles wake/sleep via the control socket |
| On | Double press | Executes the configured shutdown command (`systemctl poweroff`) |
| On | Long hold | Bypassed in software — Pi 5 firmware forces a hardware power-off (works even if the software is unresponsive) |
| Off | Press | Powers Pi on |

**Skipping the button:** leave J2 unwired and use SSH commands (see [Operate](operate.md)) or an `awake-schedule` (see [Configure](configure.md)) instead. The default `buttond` config has `device: null`, which skips evdev enumeration.

---

## Physical assembly

The reference build uses a French cleat for mounting, a 3D-printed Pi bracket on the rear of the monitor, and a wooden shadow box around the panel. CAD/laser files live in `../maker/`:

| File | Purpose |
| --- | --- |
| [`../maker/cleat-spacers.scad`](../maker/cleat-spacers.scad) / `.stl` / `.3mf` | French cleat spacer blocks (3D print) |
| [`../maker/cleat-drill-template.svg`](../maker/cleat-drill-template.svg) | Drill template for the cleat bolt pattern |
| [`../maker/pi5_bracket.svg`](../maker/pi5_bracket.svg) | Laser-cut bracket for mounting the Pi 5 to VESA hardware |

### Target hardware

- VESA pattern: 100×100 mm, M4 thread with shallow ~10 mm engagement
- Bolt length must clear the full stack — wood cleat + spacer + bracket — while still engaging the VESA thread (this build uses M4 × 40 mm)
- Spacer blocks raise cleat hardware 6 mm off the shell to prevent crushing

### Tools

| Tool | Notes |
| --- | --- |
| 3D printer (FDM) | Cleat spacers, optional Pi bracket. Print in PETG — these are load-bearing, and PLA can creep under sustained load near a warm panel. |
| Laser cutter | Required for the Pi bracket — the mounting holes need tighter tolerance than hand tools hold. |
| Drill + bits | M4 clearance for VESA, pilot holes for cleat |
| Pocket-screw jig | Frame joints; wood screws are a fallback |
| Miter or circular saw | Shadow-box lumber |

### Steps

The photos throughout this section are from the reference build — a deep frame around a 27″ Dell S2725QC, with a birch-plywood box, an oak face frame, and the Pi hung off the monitor's VESA mount on a French cleat. Treat them as one worked instance of the general steps, not the only way.

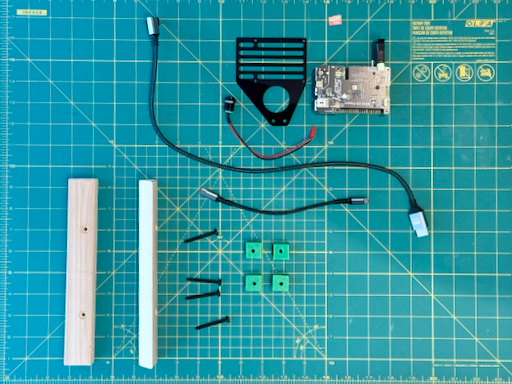
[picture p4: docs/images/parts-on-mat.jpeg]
wood cleat, cables, screws, spacer blocks, button, Raspberry Pi, and mounting bracket laid out on a green cutting mat


**1. Print the cleat spacers.** Slice `cleat-spacers.3mf` (or the STL) in PETG at 0.2 mm layer height, 40%+ infill, no supports. They sit between the cleat hardware and the monitor's rear shell so clamping force is distributed and the plastic doesn't crush.

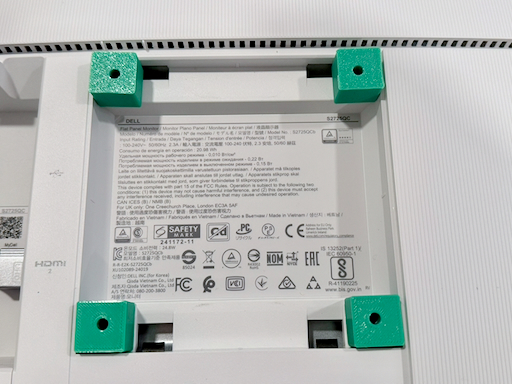
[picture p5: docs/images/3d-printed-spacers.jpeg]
four green 3D-printed spacer blocks positioned over the monitor's VESA mounting holes


**2. Mount the French cleat.** Print `cleat-drill-template.svg` at 100% scale and verify 100×100 mm spacing against your monitor before drilling. Install M4 × 40 mm flat-head cap screws through the cleat and spacers into the VESA holes, engaging ~10 mm of VESA thread — snug, not tight. Confirm the monitor hangs plumb on the receiver before finalizing.

For the wall-side receiver, span at least one stud. In the reference build the wall cleat is over 16″ long to land on a stud, with the far end carried by a 50 lb butterfly drywall anchor; the plaster patch covers a first outlet location that was blocked by a second stud inches from the anchor.

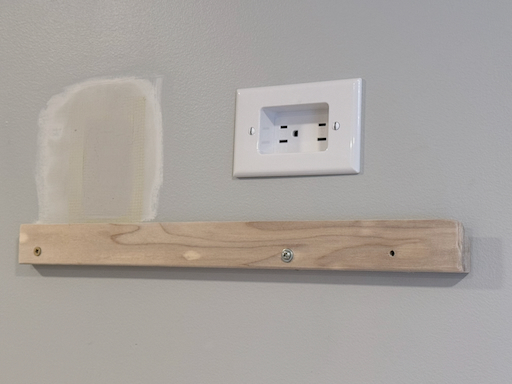
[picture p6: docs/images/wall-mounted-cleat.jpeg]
grey wall with a recessed electrical outlet, a plaster patch, and a long wooden French cleat


**3. Mount the Raspberry Pi.** Laser-cut `pi5_bracket.svg` from 3 mm acrylic — the M2.5 mounting holes have to land on the Pi's hole pattern precisely, which hand-drilling won't hold. Mount the Pi on the bracket with M2.5 standoffs, and orient it so the USB-C and micro-HDMI ports face the cable routing path.

Stack the power hat over the fan on the standoffs, and — if you're adding the button — solder the 2-pin header to the J2 power pads now (see [Power button wiring](#power-button-wiring)).

**Verify cooling (after first boot).** The Pi 5 drives the fan from the kernel, so confirm it once the Pi is running — ideally under load (the software build is a good moment). Read the live RPM, the cooling level, and the temperature:

```bash
# Live fan RPM (Pi 5 fan header / official Active Cooler):
grep -H . /sys/class/hwmon/hwmon*/fan1_input 2>/dev/null
# Cooling level the kernel is driving (0 = off … up to max):
for d in /sys/class/thermal/cooling_device*; do
  echo "$(cat "$d/type"): $(cat "$d/cur_state")/$(cat "$d/max_state")"
done
vcgencmd measure_temp
```

Under load the RPM should be clearly non-zero and the temperature should stay well under 80 °C (the Pi 5 throttles around 80–85 °C). If `fan1_input` doesn't exist, your fan isn't on the Pi's managed header — some HATs power it directly — so verify it the analog way: feel for airflow.

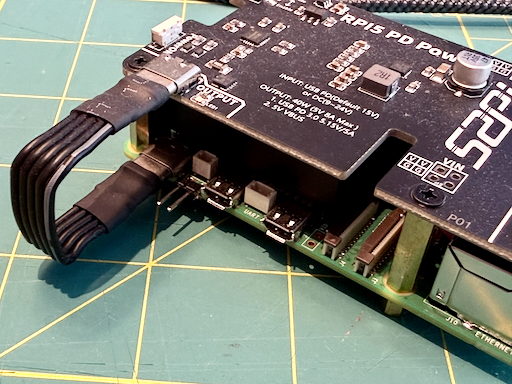
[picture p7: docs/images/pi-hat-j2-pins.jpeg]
Raspberry Pi 5 with power hat, a short hat-to-Pi USB cable, and a 2-pin header soldered to the J2 power pads


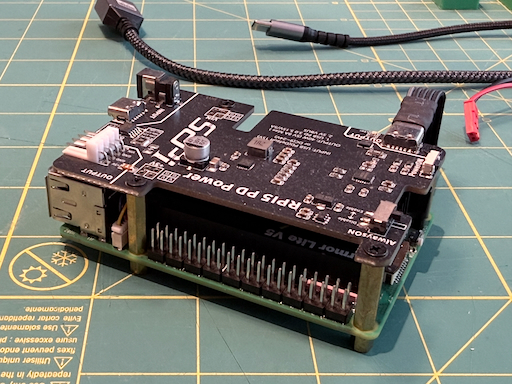
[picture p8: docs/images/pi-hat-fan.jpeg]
side view of the Raspberry Pi assembly with the power hat and fan stacked


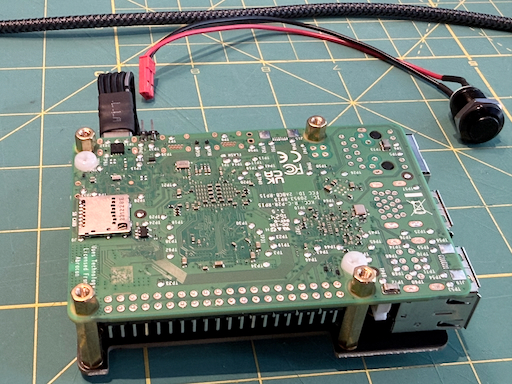
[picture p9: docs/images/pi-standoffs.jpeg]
bottom of the Raspberry Pi 5 with four brass M2.5 standoffs


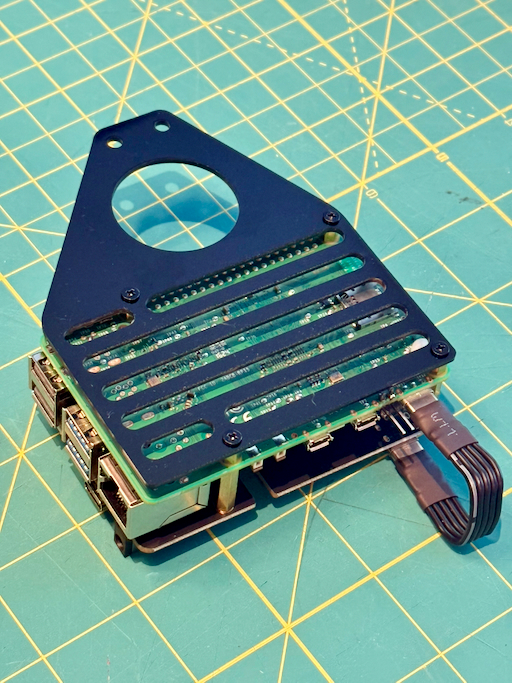
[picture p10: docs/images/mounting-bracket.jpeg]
black acrylic bracket fastened to the Pi standoffs with machine screws


The bracket then screws to the cleat spacer through pre-drilled pilot holes, so the whole Pi assembly rides on the monitor's VESA cleat.

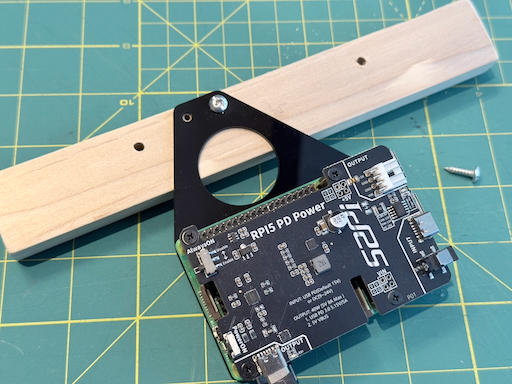
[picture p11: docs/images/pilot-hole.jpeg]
wood French cleat spacer with VESA bolt holes and a pre-drilled pilot hole for the bracket screw


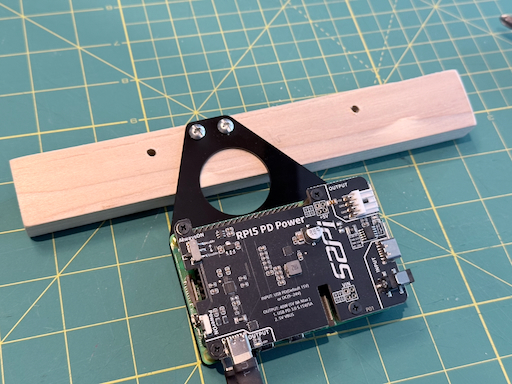
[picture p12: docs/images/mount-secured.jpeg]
acrylic Pi bracket secured to the wood cleat spacer with two flat-head screws


**4. Build the shadow box.** A shallow wooden frame around the monitor that conceals the Pi, cables, and hardware.

- **Depth:** Determine the wall-to-front-of-monitor distance and subtract approximately 0.5" for ventilation.
- **Construction:** 3/4-inch birch plywood with pocket screws at corners; wood glue.
- **Finish:** Matte black for the shadow box and paint or stain of choice for the face frame.

_As built:_ a birch-plywood box behind an oak face frame. The box is made from 2.625″-wide plywood strips; target inside dimensions 24 1/16″ × 14″, each cut ~1/16″ oversize for a snug fit, with two pocket screws and glue per joint. The face frame is ripped from ¼″ × 3.5″ oak into ¼″ × 1.625″ strips (one 48″ length yields a full frame); target inside opening 23½″ × 13¼″.

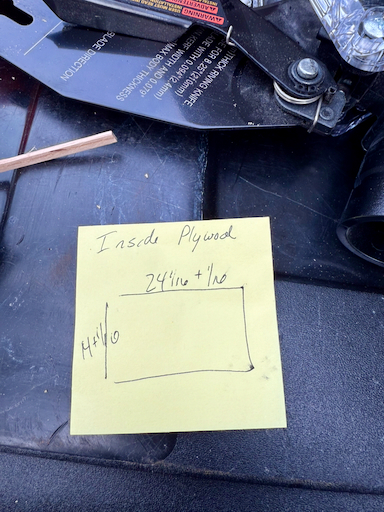
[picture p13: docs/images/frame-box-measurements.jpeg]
sticky note with a hand-drawn rectangle marked 24 1/16″ + 1/16″ wide and 14″ + 1/16″ tall — inside plywood box


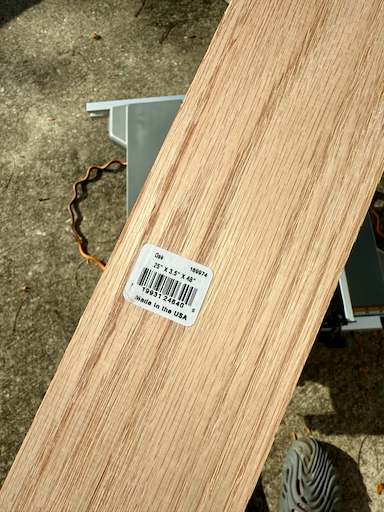
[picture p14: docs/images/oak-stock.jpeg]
oak stock labeled 0.25″ × 3.5″ × 48″ ripped into face-frame strips


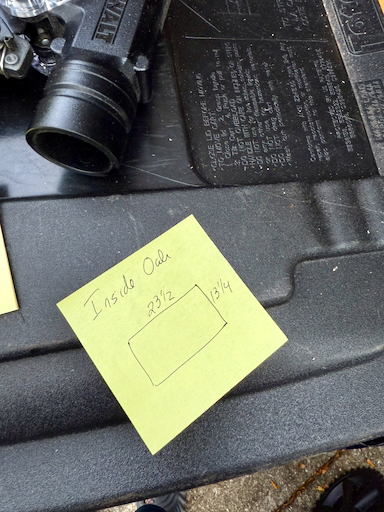
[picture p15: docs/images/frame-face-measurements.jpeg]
sticky note with a hand-drawn rectangle labeled 23½ × 13¼ — inside edge of the face frame


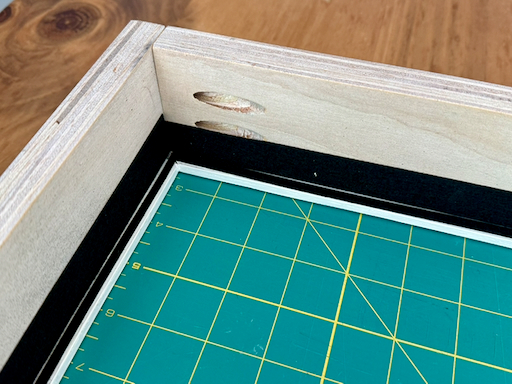
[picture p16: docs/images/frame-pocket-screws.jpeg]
inside view of the frame showing the angled holes for two pocket screws per joint


Line the face-frame back and the plywood sides with thin strips cut from 2″ adhesive felt — it protects the monitor's face and edges and gives a snug fit.

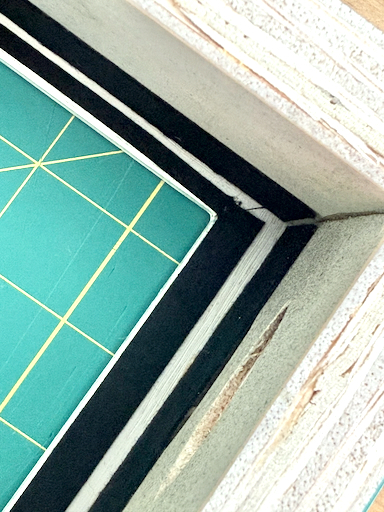
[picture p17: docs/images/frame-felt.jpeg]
corner of the plywood box with black adhesive-felt strips lining the inside


Drill the cross member to clear the monitor's speakers and vents. The button hole gets a larger counterbore on the inside to recess its retaining nut; the larger holes are sized and placed to line up with the panel's existing vents and speakers.

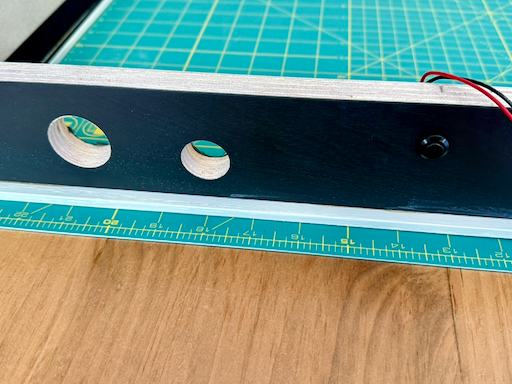
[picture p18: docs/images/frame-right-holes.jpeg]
black cross member with the button hole and two large holes aligned to the monitor's right speaker and a vent


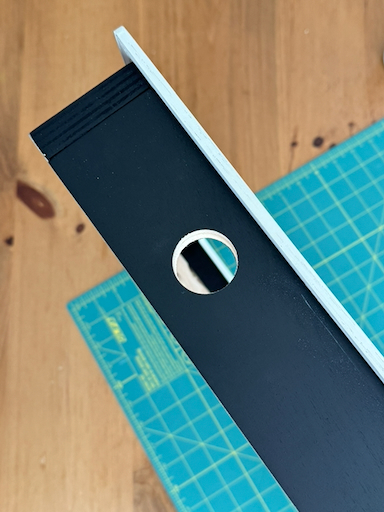
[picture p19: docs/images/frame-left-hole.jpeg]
black cross member with a 1.25″ hole drilled for the left speaker


The finished box stands ½″ off the wall, leaving a continuous gap behind the frame for convective airflow:

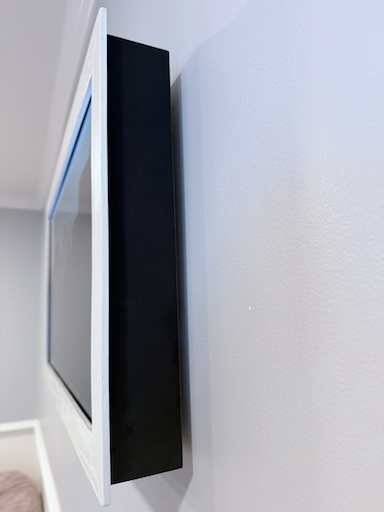
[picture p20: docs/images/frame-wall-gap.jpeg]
grey wall showing the half-inch gap to the black-painted side member of the frame


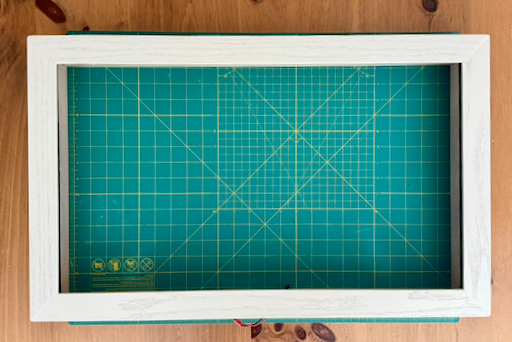
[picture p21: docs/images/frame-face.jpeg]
finished cream-colored oak face frame, front view, on a green cutting mat


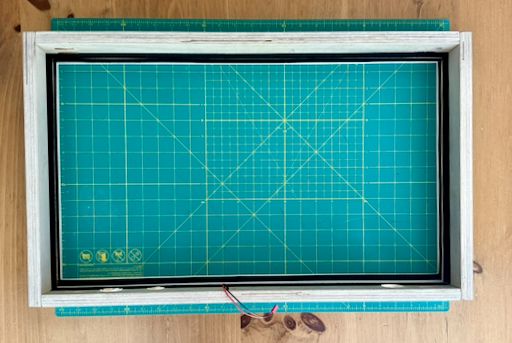
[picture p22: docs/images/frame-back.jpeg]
raw plywood edge of the box, rear view, with the momentary-button wiring visible at the bottom


**5. Cable management.**

- **HDMI:** short, high-quality micro-HDMI to HDMI. A right-angle micro-HDMI connector at the Pi is critical — it keeps the cable from side-loading the fragile micro-HDMI port.
- **USB-C power:** short, high-quality cable.
- **Button wire (if present):** route from J2 to the button cutout. A 2-pin JST or dupont connector at the Pi end makes service easy.

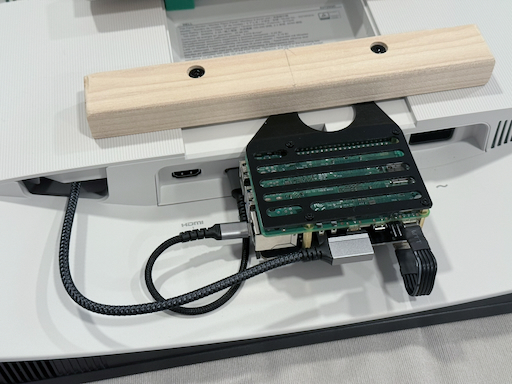
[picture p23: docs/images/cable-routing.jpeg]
HDMI and USB-C cables routed neatly across the back of the monitor


The monitor's own power cord is easiest to dress _after_ the cleat engages the wall — resting the excess on top of the upper cleat is cleaner than threading it between the cleats.

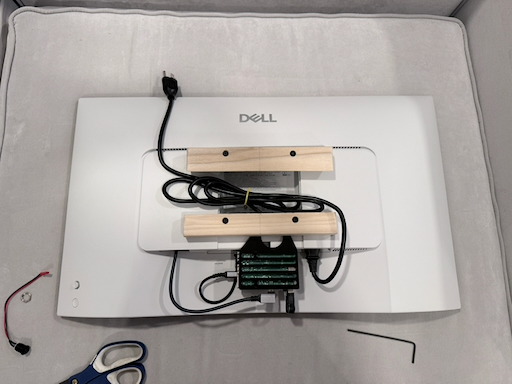
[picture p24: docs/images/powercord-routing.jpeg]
monitor power cord zip-tied and routed near the French cleats


**6. Final assembly.** With the Pi, cleat, and cables mounted to the monitor, hang it on the wall cleat and confirm it boots to the desktop, then fit the wooden frame over the panel. After installing the [software](install.md) and letting the slideshow run ~30 minutes, check temperatures over SSH with `vcgencmd measure_temp` — it should stay well under 80°C. Also sweep an infrared thermometer across several spots on the wall behind the frame to confirm no hot spots are building up in the enclosure. If anything climbs, widen the wall gap or improve airflow before leaving the frame unattended.

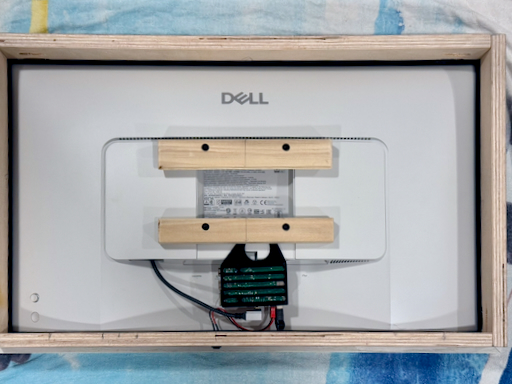
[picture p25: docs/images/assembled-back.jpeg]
monitor face-down on a towel showing the wooden frame, French cleats, and mounted Raspberry Pi 5


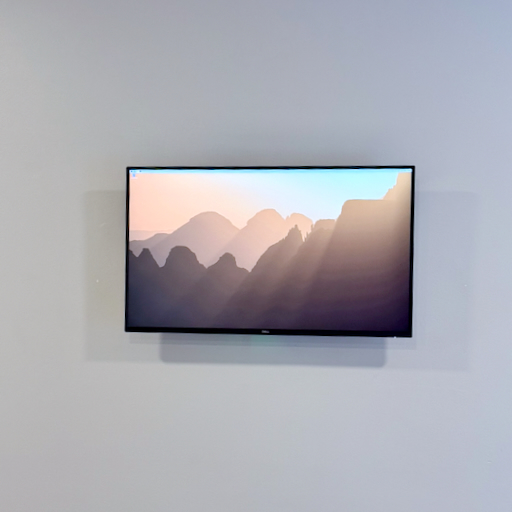
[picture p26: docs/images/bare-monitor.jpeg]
bare Dell monitor mounted on the wall showing the default Raspberry Pi OS desktop


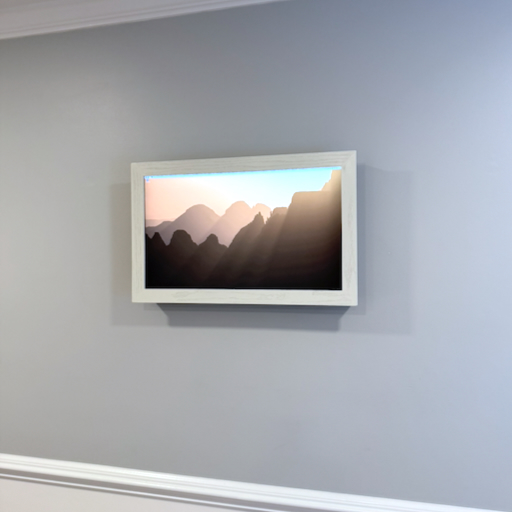
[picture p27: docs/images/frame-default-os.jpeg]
wooden frame installed around the default Raspberry Pi OS desktop on the wall


---

## Finished build

With the software running, the frame shows a brief greeting while the first photos warm up, and a sleep card before it powers the panel down.

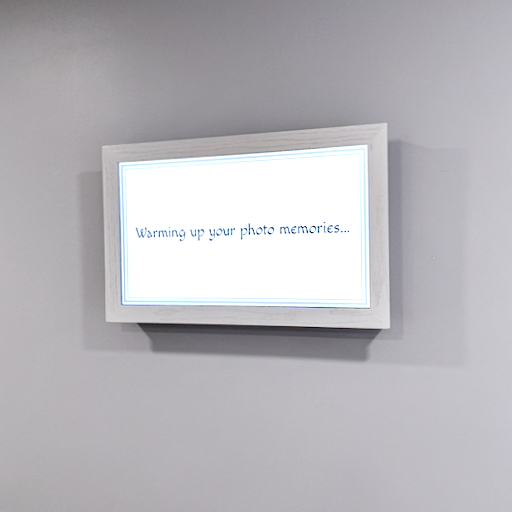
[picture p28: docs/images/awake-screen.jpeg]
wall-mounted photo frame with a white screen and black lettering reading "Warming up your photo memories..."


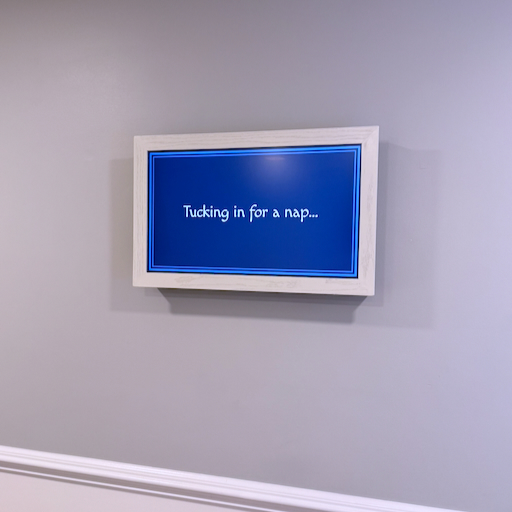
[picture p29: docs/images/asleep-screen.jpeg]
wall-mounted photo frame with a dark blue-grey screen and cream lettering reading "Tucking in for a nap..."


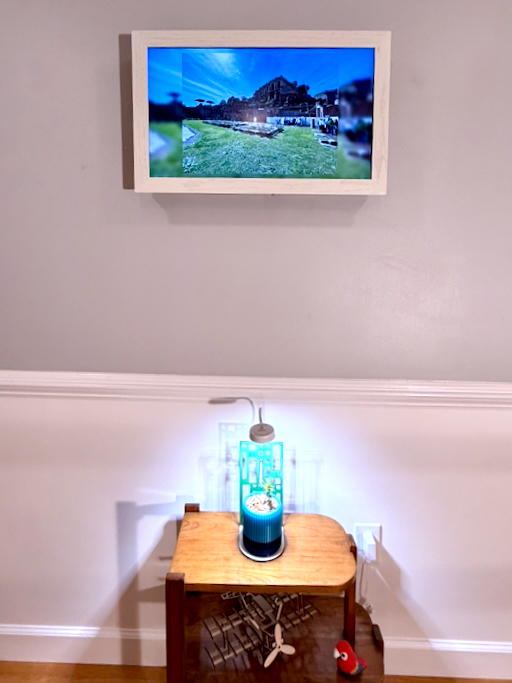
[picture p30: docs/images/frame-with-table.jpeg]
full wall view of the finished photo frame above a table


---

## Assembly checklist

- [ ] Cleat spacers printed and fit-checked on VESA holes
- [ ] French cleat mounted; monitor hangs plumb
- [ ] Pi bracket cut and Pi mounted
- [ ] HDMI connected with a right-angle micro-HDMI at the Pi
- [ ] USB-C power connected
- [ ] Button wire routed (if using)
- [ ] Shadow box built; ½″ wall gap for airflow
- [ ] Software fully installed and tested
- [ ] Thermal check passed (fan spins under load; temp stays < ~80 °C)

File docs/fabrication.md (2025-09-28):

# Fabrication

Document the physical build of your frame here—laser cutting, 3D printing, carpentry, and finishing work. The sections below capture the standard approach; adapt them to match your tools and materials.

## Laser cutting
- Export bezel or mat templates from your CAD tool in SVG or DXF format.
- Test the cut on cardboard to validate fit before committing to acrylic or wood.
- Mask visible surfaces to avoid smoke staining during the cut.

## 3D printing
- Model brackets that clamp the Raspberry Pi to VESA mount points or the display chassis.
- Print test pieces with draft settings to dial in tolerances before switching to final material.
- Add channels or clips for cable routing if you plan to hide wiring behind the frame.

## Carpentry and finishing
- Build a shallow shadow-box to house the monitor. Leave ventilation slots near the top for heat exhaust.
- Use pocket screws or biscuits on long runs so the frame remains rigid after repeated removals from the wall.
- Finish with paint or stain that complements the room lighting; satin sheens minimize glare from the display.

## Assembly checklist
1. Dry-fit the monitor, Pi, brackets, and wiring before final gluing or finishing.
2. Attach French cleats or your preferred wall-mounting hardware.
3. Install the electronics, route cables, and secure strain relief.
4. Close the frame, power it on, and run the software setup steps.

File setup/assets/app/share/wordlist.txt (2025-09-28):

acorn
airplane
ant
apple
apricot
apron
artichoke
asparagus
ball
balloon
bamboo
banana
basket
bean
bear
bed
bee
beet
berry
bike
bird
blackberry
blanket
block
blocks
blossom
blueberry
boat
book
bottle
bowl
broccoli
broom
brush
bus
butterfly
button
cabbage
cactus
camel
canoe
cantaloupe
car
cards
carrot
cart
cat
cauliflower
celery
chair
chard
checkers
cherry
chess
chicken
clock
clover
coconut
comb
corn
cow
crab
cucumber
cup
currant
daisy
dandelion
date
deer
desk
dice
dog
doll
dolphin
domino
donkey
door
drum
duck
eagle
eggplant
elephant
fern
ferry
fig
fish
fork
fox
frisbee
frog
game
garlic
giraffe
glass
glider
goat
goldfish
goose
grape
grapefruit
guava
hamster
helicopter
hippo
holly
honeysuckle
horse
hula
ivy
jeep
jellyfish
jet
jigsaw
jug
jump
kale
kangaroo
kayak
key
kite
kitten
kiwi
lamb
lamp
lavender
leek
lego
lemon
lettuce
lily
lime
lion
llama
lobster
lotus
magnolia
mango
maple
marble
marigold
melon
mint
mirror
monkey
moped
moss
motorcycle
mouse
mushroom
nectarine
oak
octopus
okra
olive
onion
orange
orchid
otter
owl
paddle
paint
palm
panda
pansy
papaya
parrot
parsnip
pea
peach
pear
penguin
pepper
petal
pig
pine
pineapple
plane
plate
plum
pomegranate
pony
poppy
potato
pumpkin
puppy
puzzle
rabbit
raccoon
racket
radio
radish
raft
raspberry
rocket
rope
rose
rowboat
rug
sage
sailboat
sandbox
scooter
seal
shark
sheep
ship
skunk
sled
slide
sloth
snail
snake
spinach
spoon
squash
squirrel
starfish
stool
strawberry
subway
sunflower
swan
swing
table
tag
tangerine
taxi
tiger
toad
tomato
top
towel
toy
tractor
train
tram
tricycle
truck
tulip
turnip
turtle
van
violet
wagon
watermelon
whale
whistle
white
willow
window
wolf
worm
yam
yo-yo
zebra
zucchini

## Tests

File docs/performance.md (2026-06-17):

# Performance

How the viewer reaches smooth 4K60 transitions on a Raspberry Pi 5, how to
measure it, and what to check when frame rates regress. Everything here was
learned the hard way during a week of profiling in June 2026; the punchline
is that **not one of the root causes was a slow shader** — they were
firmware, a missing driver package, the presentation mode, and CPU/GPU
contention. Measure the whole pipeline before optimizing any pass.

## Measuring

Two built-in tools, no extra software required:

**Per-transition stats** are logged at info level when any transition
finishes, but only when `metrics: true` is set in `config.yaml` (off by
default to keep the journal quiet):

```
journalctl -t photoframe -f | grep transition_frame_metric
# transition=iris frames=73 avg_fps=28.1 avg_frame_ms=35.5 best_frame_ms=2.3 worst_frame_ms=77.8
```

The same `metrics: true` flag also emits a `photo_display_metric` line each
time a photo reaches the screen, for auditing the scheduler's randomness:

```
journalctl -t photoframe -f | grep photo_display_metric
# seq=412 inventory=1873 distinct=389 shown_count=1 gap=-1 weight=1.00 age_days=4.2 created_source=birthtime path=/var/lib/photoframe/photos/cloud/2021/img_0420.jpg
```

`gap` is the number of displays since that photo was last shown (`-1` the
first time it appears); under uniform random selection it averages the
inventory size. `age_days` is the photo's age — `now − created_at` — which
drives the weight, and `created_source` records where `created_at` came from:
`birthtime` (the intended filesystem staging time), `mtime`, or `now` (a
fallback when birth time is unavailable). If `created_source` is ever not
`birthtime`, photos are being aged by something other than when they landed on
the frame, so check the sync tooling and filesystem (see the note in
[configure.md → Playlist weighting](configure.md#playlist-weighting)). To audit coverage, grep these lines over a long run, list
the library recursively (`find <photo-library-path> -type f`), and diff the
two sets: paths that never appear are starved, and a `gap` distribution that
clusters well below `inventory` means photos repeat too soon.

Each process also logs a one-time `playlist_scheduler` line at startup (before
`seq=1`) recording the scheme and parameters that produced the series, so a
journal spanning restarts or config changes can be segmented and interpreted:

```
journalctl -t photoframe | grep -E 'playlist_scheduler|photo_display_metric'
# playlist_scheduler order=weighted-spread refractory=0.700 min_spacing=0.700 new_multiplicity=3 half_life_secs=259200
```

`refractory` is the effective minimum-gap fraction in play (`0.000` for
`weighted-random`, which ignores `min_spacing`); `min_spacing` echoes the raw
config value.

Finally, the first time each photo reaches the screen it logs a one-shot
`photo_first_shown` line carrying `latency_secs` — the precise gap between the
file's birth time and its first appearance (`age_days` on the display line is too
coarse to see a minutes-scale lag):

```
journalctl -t photoframe | grep photo_first_shown
# seq=4104 inventory=822 weight=2.99 latency_secs=1624 created_source=birthtime path=/var/lib/photoframe/photos/local/2004/IMG_2875.jpeg
```

`latency_secs` is a true staging latency only for photos added at runtime; for
the startup-scanned library it is just the photo's age at first show, so filter
to photos whose birth time is later than the `playlist_scheduler` line when
measuring how quickly a fresh upload appears.

Use `-t photoframe` (syslog identifier), not `-u` — the app runs inside the
greetd session, not as its own systemd unit.

The stats measure *submission* cadence (when `present()` returns), which
matches what the panel displays only because transition redraws are paced
to the refresh interval. If `best_frame_ms` ever drops well below a vsync
(e.g. 0.4ms), frames are being submitted back-to-back and mailbox is
discarding some unseen — the displayed motion is then worse than the
numbers suggest. Trust your eyes (or a phone slow-mo recording of the
panel) over the log when they disagree.

For ground truth, film the panel with a phone's slo-mo camera and run
`developer/display-cadence.sh <video> <capture_fps>` — it recovers the true
displayed cadence from inter-frame differences: median update interval,
longest static runs (hangs), and an update timeline. This is the instrument
that separates pacing problems from animation-content problems.

**`frametest`** is a minimal fullscreen probe staged to
`/opt/photoframe/bin/frametest`. It renders selectable workloads — `solid`
(a clear, zero memory traffic), `tex` (one full-screen texture), `fade`
(two textures mixed, the cheapest real transition) — under a selectable
present mode (`fifo|mailbox|immediate`) and frame latency, printing cadence
once per second. Run it inside the kiosk session:

```bash
sudo -u kiosk env XDG_RUNTIME_DIR=/run/user/$(id -u kiosk) WAYLAND_DISPLAY=wayland-1 \
  /opt/photoframe/bin/frametest solid fifo
```

The ladder `solid fifo` → `solid mailbox` → `fade mailbox` separates pacing
problems (solid can't hit refresh rate) from throughput problems (solid
can, fade can't). When in doubt, start here — it takes five minutes and
rules out the entire application.

## Root causes and fixes (June 2026)

1. **Bootloader EEPROM memory regression.** Pi 5 bootloaders v2025.01.22
   through v2025.10.x shipped a memory configuration (fake NUMA +
   `SDRAM_BANKLOW`) that cut GPU memory bandwidth by roughly a third. The
   bootloader lives on the board, not the SD card — a fresh OS install does
   not fix it. Setup now stages updates (`setup/system/modules/35-firmware.sh`)
   and `verify.sh` warns when one is pending. Manual check:
   `sudo rpi-eeprom-update`.

2. **Missing GL drivers → CPU compositing.** The kiosk installs packages
   with `--no-install-recommends`; without `libgl1-mesa-dri`, sway cannot
   create a GPU renderer and silently falls back to pixman, compositing
   every 4K frame on the CPU (~30+ ms each). Symptoms: all transitions cost
   the same regardless of shader weight; `sway -d` logs show no GLES2
   renderer. The package is now explicit in the apt list and checked by
   `verify.sh`.

3. **FIFO presentation costs two vsyncs per frame.** Vulkan FIFO emulated
   over Wayland frame callbacks serializes against the compositor on stacks
   without the `wp_fifo_v1` protocol (sway 1.10 / wlroots 0.18): `frametest
   solid fifo` locks at a metronomic 33.3 ms on a 60 Hz output. The viewer
   therefore defaults to **mailbox** presentation, which latches the newest
   complete frame each vsync — measured 62.9 fps average on a 4K radial
   wipe.

   *Worth retrying with newer sway:* wlroots 0.19+ speaks `wp_fifo_v1`, so
   under sway 1.11+ proper FIFO should pace at full rate. The check is one
   command (`frametest solid fifo` ≈ 60 fps means FIFO is healthy); the
   switch is `PHOTOFRAME_PRESENT_MODE=fifo` in the launcher. There is no
   urgency — mailbox remains correct on both broken and fixed stacks.

   **Mailbox must be paced.** Mailbox never blocks, so an unpaced redraw
   loop submits frames faster than the compositor latches them; mailbox
   then discards the older ones unseen while the animation clock keeps
   advancing, so displayed motion is uneven (jerky) even though `avg_fps`
   looks healthy — the tell is `best_frame_ms` far below a vsync (e.g.
   0.4 ms). The viewer paces each transition redraw to ≥ one refresh
   (≈15 ms) since the last present, so submission cadence tracks display
   cadence: no discarded frames, even motion, honest stats.

4. **CPU/GPU contention during transitions.** Preparing the next photo
   runs a JPEG decode + NEON matting on worker threads and ends with a
   multi-megapixel `write_texture`. On the Pi's unified memory those bursts
   steal the same bandwidth the transition is rendering with, and a
   transition starting is exactly what drops the preload below target and
   kicks off the next prep — so the contention landed precisely during
   animations, as 50–140 ms worst frames. Both halves are now gated while a
   transition is animating: non-priority uploads are deferred, and new
   decode/matting work is not started. The long dwell (seconds) absorbs the
   deferral with room to spare.

## Render-cost design

The Pi 5's budget at 4K60 is roughly 30 GPU-ops per pixel per frame, so
full-screen passes are spent carefully:

- **Resting photos render at native resolution.** Sharpness when the image
  is still is the product; nothing below applies to dwell frames.
- **Transition frames render at 1/`TRANSITION_HALF_SCALE` (default 2)**
  into an offscreen intermediate and are upsampled — quarter the fill cost,
  hidden by motion. The final ~1% of each transition renders native so the
  incoming photo settles in sharp. Override per deployment with
  `PHOTOFRAME_TRANSITION_SCALE` (1 bypasses the intermediate entirely).
- **Iris petals render at 1/`IRIS_LAYER_SCALE` (default 4)** in their own
  premultiplied layer (`PHOTOFRAME_IRIS_LAYER_SCALE` to override). The
  petal SDF math runs on CPU-precomputed per-frame constants and avoids
  dynamically indexed local arrays, which the V3D compiler demotes to slow
  per-pixel scratch memory. The layer is `Rgba16Float`, not 8-bit: petals
  are very dark in linear light, so a smooth shading gradient spans only a
  few 8-bit levels and visibly bands — half-float has the dark-range
  precision to keep it smooth, at negligible cost on a quarter-res layer.
- **The main pass renders opaquely** (no blending) and composites letterbox
  regions over the background color in-shader, saving a destination read
  per pixel and keeping the surface eligible for direct scanout.

## Known limitation: direct scanout

sway attempts to scan out the fullscreen buffer every frame but the import
fails: v3dv allocates UIF-tiled swapchain buffers (modifier
`0x0700000000000006`), which the display controller cannot scan out, and
`MESA_VK_WSI_DEBUG=linear` does not change the negotiated modifier (tested
on Mesa 25.0). sway therefore composites — on the GPU, costing a few ms per
frame. Parked: not worth chasing while transitions hold 60 fps. Revisit
alongside a sway/wlroots/Mesa upgrade (`journalctl -t photoframe` with
`sway -d` shows per-frame scan-out decisions).

## Environment knobs

Set in `/usr/local/bin/photoframe` (the launcher); all optional:

| Variable | Values | Default |
| --- | --- | --- |
| `PHOTOFRAME_PRESENT_MODE` | `fifo` / `mailbox` / `immediate` | mailbox when available |
| `PHOTOFRAME_TRANSITION_SCALE` | 1–4 | 2 |
| `PHOTOFRAME_IRIS_LAYER_SCALE` | 1–8 | 4 |
| `WGPU_BACKEND` | `vulkan` / `gl` | vulkan |

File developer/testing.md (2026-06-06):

# Testing & release

The single home for verifying the photo frame: automated checks you can run on
any dev machine, the on-device test plan, and the release gate.

- Day-to-day operator commands → [docs/operate.md](../docs/operate.md)
- How the kiosk stack is built and debugged → [architecture.md](architecture.md)

---

## Automated checks (no Pi required)

Run on any macOS/Linux dev machine before pushing:

```bash
cargo fmt --all --check
cargo clippy --workspace --all-targets -- -D warnings
cargo test --workspace
cargo audit                          # dependency CVE scan (cargo install cargo-audit)
make -f tests/Makefile docs-links    # markdown link check
```

`cargo audit` should report **zero vulnerabilities**. A lone `paste`
*unmaintained* warning is expected and benign — it is a build-time proc-macro
pulled in only by wgpu's macOS Metal backend, which never compiles on the Pi.

---

## On-device test harness

The `tests/Makefile` targets run on the device after an install:

```bash
make -f tests/Makefile smoke           # 10–15 min full sanity
make -f tests/Makefile daily           # ≤3 min quick check
make -f tests/Makefile wifi-recovery   # captive-portal recovery
make -f tests/Makefile collect         # bundle logs for a report
```

> **Wi-Fi recovery over SSH:** `wifi-recovery` disconnects Wi-Fi mid-test. If your SSH session runs over `wlan0`, start it inside `tmux` and set `ALLOW_WIFI_SSH_DROP=1` so it survives the drop, then `tmux attach` once the frame reconnects. Full procedure in [docs/operate.md](../docs/operate.md).

Plus the post-install health checks:

```bash
./setup/tools/verify.sh
/opt/photoframe/bin/print-status.sh
sudo ./setup/system/tools/diagnostics.sh
```

### Pre-flight (on the Pi)

```bash
vcgencmd measure_temp
grep -H . /sys/class/hwmon/hwmon*/fan1_input 2>/dev/null   # fan RPM (non-zero under load)
sudo -u kiosk env XDG_RUNTIME_DIR=/run/user/$(id -u kiosk) WAYLAND_DISPLAY=wayland-1 wlr-randr
tests/collect_logs.sh        # baseline log capture
```

---

## Test scenarios

Conditions worth exercising across a release — each surfaces bugs that only show
in a specific combination (Wi-Fi vs Ethernet, internet down, large libraries, the
overnight sleep loop). Run the [phase checklist](#manual-phase-checklist) — or the
relevant `make` target — under each. For a solo build the **core three** cover
most releases; the rest are worth doing before a big change.

**Core — every release:**

| Scenario | Why it matters |
|---|---|
| Clean install → slideshow on your normal network | Baseline: the happy path works end to end |
| Wi-Fi up but **internet down** (pull the router's WAN/uplink) | The watcher must **not** false-trigger recovery |
| **Overnight burn-in** with a sleep schedule | Catches memory leaks and wake/sleep-loop drift |

**Before a big change:**

| Scenario | Why it matters |
|---|---|
| **Large library** (1–3k photos) over Wi-Fi | Decode/render/memory pressure (see [Advanced › Memory tuning](../docs/advanced.md#memory-tuning)) |
| **Update + rollback** — `git checkout <tag>`, redeploy, restart greetd | A redeploy doesn't break a running unit |

---

## Manual phase checklist

- **Blank-Pi install** — Flash latest Trixie 64-bit, boot, network up, `XDG_SESSION_TYPE=wayland` after first graphical login.
- **Project setup** — clone repo; `sudo ./setup/system/install.sh`; `./setup/application/deploy.sh`; customize `/etc/photoframe/config.yaml`; populate library.
- **Kiosk autostart** — `systemctl status greetd photoframe-wifi-manager photoframe-sync.timer`; reboot; confirm greetd claims tty1 and the app launches full-screen. Confirm the `kiosk` user can reach seatd: `id -nG kiosk` must include the group that owns `/run/seatd.sock` (`stat -c '%G' /run/seatd.sock`, normally `seat`). A missing membership fails every session at the wrapper's seatd check.
- **Display & frame rate** — the kiosk `wlr-randr` (pre-flight command above) shows the target mode (4K@60 preferred); short phone video documents smoothness; note tearing/flicker.
- **Button & power** — `sudo evtest` to identify input device; single press toggles **both** directions — test the round trip (awake → sleep, then sleep → wake); double press clean shutdown; long hold is bypassed for the Pi 5 firmware force-off (don't actually trigger it if there's risk of corruption).
- **Sleep schedule** — set a near-future window, restart kiosk, observe transitions; manual `set-state`/`toggle-state` over the control socket works. Exercise a wrap-past-midnight window (start later than end, e.g. `["21:00","07:00"]`).
- **Wi-Fi provisioning** — `make -f tests/Makefile wifi-recovery`; phone joins `PhotoFrame-Setup`, submits credentials, frame reconnects. Also exercise LAN-up/Internet-down (slideshow keeps advancing) and full Wi-Fi outage with later restoration (auto-reconnect).
- **Library ingest** — tiny library validates EXIF/mat/transitions; medium library run for 10–15 min with `top -H -p $(pidof photoframe)` and `vcgencmd measure_temp`. During the burn-in confirm the fan ramps under load (`grep -H . /sys/class/hwmon/hwmon*/fan1_input`) and the temperature holds under ~80 °C.
- **Updates & rollback** — `git checkout <release-tag>`, rebuild, restart greetd; rollback to previous tag; confirm unit files unchanged via `systemctl cat greetd.service`.
- **Power loss** — momentarily cut power; confirm auto-boot, kiosk service startup, slideshow resume; check `journalctl -b | grep -i fsck` and `dmesg | grep -i error`.
- **Diagnostics bundle** — `tests/collect_logs.sh`; verify artifact at `artifacts/FRAME-logs-*.tar.gz`.

### Acceptance criteria

- Cold boot to slideshow ready in ≤ 45 s after greetd starts.
- Display locked to desired mode with no sustained tearing.
- Button behaviors reliable (single-press sleep toggle, double-press shutdown).
- Sleep schedule respects configured windows; reacts to manual `toggle-state` immediately.
- Wi-Fi provisioning, outage resilience, and watcher recovery all succeed without slideshow halt.
- Medium-library playback smooth (CPU spikes <150% overall, no OOM or IO errors).
- Update deploys cleanly; rollback path verified.
- Power-loss recovery returns to slideshow without manual intervention.
- Diagnostics bundle captures all required evidence.

### Recovery & rollback notes

- **Bad config.yaml:** restore from a known-good backup (keep one before editing); validate YAML (`python3 -c "import yaml,sys; yaml.safe_load(open('/etc/photoframe/config.yaml'))"`); restart kiosk.
- **Service won't start:** `journalctl -u greetd.service -b` and `journalctl -u photoframe-wifi-manager.service -b`; rebuild binary; `sudo systemctl daemon-reload`.
- **Failed update:** `git checkout <previous-good>`; rebuild + restart; if binary corrupted, `rm -rf target/` and rebuild.
- **Network stuck offline:** `nmcli connection show`; `sudo systemctl restart NetworkManager`; collect logs.

---

## Dependency upgrade runbook

Use this before merging changes that also touch host dependencies.

**1. Maintenance branch:**

```bash
git checkout -b maintenance/upgrade-$(date +%Y%m%d)
```

**2. Capture baseline:**

```bash
./developer/capture-system-baseline.sh
```

Writes version snapshots under `artifacts/upgrade-baseline-<timestamp>/`.

**3. Refresh system packages on Pi:**

```bash
sudo apt update
sudo apt full-upgrade -y
sudo reboot
# After reboot:
sudo ./setup/system/install.sh
./setup/application/deploy.sh
./setup/tools/verify.sh
```

**4. Refresh Rust dependencies:**

```bash
cargo update -w
cargo check --workspace
cargo test --workspace
cargo clippy --workspace --all-targets -- -D warnings
cargo audit
```

If `cargo update -w` introduces regressions, pin only the problematic crates and document why in the commit message.

**5. Re-evaluate git patches** in `Cargo.toml` (`cosmic-text`, `glyphon`). Keep pins only when required for reproducible runtime or compatibility on Pi.

**6. Recovery validation on device** — run the wrong-password recovery, AP outage auto-reconnect, and `WAN down / Wi-Fi up` (no false trigger) checks via `make -f tests/Makefile wifi-recovery`.

---

## Release checklist

Before tagging a release:

1. **Automated checks green** — `cargo fmt --all --check`, `cargo clippy --workspace --all-targets -- -D warnings`, `cargo test --workspace`.
2. **`cargo audit` clean** — zero vulnerabilities (the `paste` unmaintained warning is acceptable).
3. **Fresh-image smoke on real hardware** — run the [phase checklist](#manual-phase-checklist) on a clean Trixie image, paying special attention to:
   - the kiosk user's `seat` group membership / `/run/seatd.sock` access,
   - power button (single = toggle, double = shutdown),
   - Wi-Fi recovery end-to-end.
4. **Versions & lockfile** — crate `version`s bumped, `Cargo.lock` committed.
5. **Upgrade note** — if unit files, the kiosk user's groups, or tmpfiles changed, existing installs must re-run system provisioning and reboot; call it out in the release notes.
6. **Tag and push.**

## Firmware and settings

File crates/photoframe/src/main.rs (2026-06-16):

mod config;
mod events;
mod gpu;
mod processing;
mod renderer;
mod tasks {
    pub mod files;
    pub mod greeting_screen;
    pub mod loader;
    pub mod manager;
    pub mod photo_effect;
    pub mod viewer;
}

use anyhow::{Context, Result};
use clap::Parser;
use humantime::{format_rfc3339, parse_rfc3339};
use std::io::{self, IsTerminal, Read};
use std::path::PathBuf;
use std::sync::Arc;
use std::time::{Duration, SystemTime};
use tokio::sync::mpsc;
use tokio::task::JoinSet;
use tokio_util::sync::CancellationToken;
use tracing_subscriber::EnvFilter;

#[cfg(unix)]
use chrono::{DateTime, Utc};
#[cfg(unix)]
use serde::Deserialize;
#[cfg(unix)]
use tokio::io::AsyncReadExt;
#[cfg(unix)]
use tokio::net::UnixListener;

use events::{
    Displayed, InvalidPhoto, InventoryEvent, LoadPhoto, PhotoLoaded, ViewerCommand, ViewerState,
};

#[derive(Debug, Parser)]
#[command(
    name = "photoframe",
    version,
    about = "GPU-accelerated digital photo frame slideshow"
)]
struct Args {
    /// Path to YAML config
    #[arg(value_name = "CONFIG")]
    config: PathBuf,
    /// Freeze playlist weighting at this RFC 3339 instant (useful for tests)
    #[arg(long = "playlist-now", value_name = "RFC3339")]
    playlist_now: Option<String>,
    /// Print the weighted playlist order without launching the UI
    #[arg(long = "playlist-dry-run", value_name = "ITERATIONS")]
    playlist_dry_run: Option<usize>,
    /// Deterministic RNG seed for playlist shuffling (applies to dry-run and live modes)
    #[arg(long = "playlist-seed", value_name = "SEED")]
    playlist_seed: Option<u64>,
}

#[tokio::main]
async fn main() -> Result<()> {
    // init tracing (RUST_LOG controls level, default = info)
    tracing_subscriber::fmt()
        .with_env_filter(
            EnvFilter::try_from_default_env().unwrap_or_else(|_| EnvFilter::new("info")),
        )
        .with_target(false)
        .compact()
        .init();

    let Args {
        config,
        playlist_now,
        playlist_dry_run,
        playlist_seed,
    } = Args::parse();

    let now_override = match playlist_now {
        Some(ts) => Some(parse_rfc3339(&ts).context("failed to parse --playlist-now")?),
        None => None,
    };

    let cfg = Arc::new(
        config::Configuration::from_yaml_file(&config)
            .with_context(|| format!("failed to load configuration from {}", config.display()))?
            .validated()
            .context("invalid configuration values")?,
    );
    tracing::info!(
        "Loaded configuration from {}:\n{:#?}",
        config.display(),
        cfg
    );

    if let Some(iterations) = playlist_dry_run {
        run_playlist_dry_run(&cfg, iterations, now_override, playlist_seed)?;
        return Ok(());
    }

    // Channels (bounded).  Capacities are chosen to bound memory while keeping the pipeline fluid:
    // - inv_tx: burst during startup scan can be large; 128 gives headroom without unbounded growth.
    // - invalid_tx / displayed_tx: low-frequency bookkeeping; 64 is generous.
    // - to_load_tx: intentionally small (4) so the manager stays in sync with what the loader needs.
    // - loaded_tx / processed_tx: sized to viewer_preload_count so the decode pipeline stays filled
    //   without buffering more decoded frames than the viewer will consume.
    // - viewer_control_tx: external control commands are rare; 16 is ample.
    let (inv_tx, inv_rx) = mpsc::channel::<InventoryEvent>(128);
    let (invalid_tx, invalid_rx) = mpsc::channel::<InvalidPhoto>(64);
    let (to_load_tx, to_load_rx) = mpsc::channel::<LoadPhoto>(4);
    let (loaded_tx, loaded_rx) = mpsc::channel::<PhotoLoaded>(cfg.viewer_preload_count);
    let (processed_tx, processed_rx) = mpsc::channel::<PhotoLoaded>(cfg.viewer_preload_count);
    let (displayed_tx, displayed_rx) = mpsc::channel::<Displayed>(64);
    let (viewer_control_tx, viewer_control_rx) = mpsc::channel::<ViewerCommand>(16);

    let cancel = CancellationToken::new();

    // Both the stdin watcher and the Ctrl-C handler call cancel.cancel().
    // CancellationToken::cancel() is idempotent, so whichever fires first wins and
    // the second call is a no-op.
    if io::stdin().is_terminal() {
        let cancel = cancel.clone();
        tokio::task::spawn_blocking(move || {
            let mut sink = Vec::new();
            match io::stdin().read_to_end(&mut sink) {
                Ok(_) => tracing::info!("stdin closed; initiating shutdown"),
                Err(err) => tracing::warn!("stdin watcher failed: {err}"),
            }
            cancel.cancel();
        });
    } else {
        tracing::debug!("stdin is not a terminal; skipping shutdown watcher");
    }

    {
        let cancel = cancel.clone();
        tokio::spawn(async move {
            if let Err(err) = tokio::signal::ctrl_c().await {
                tracing::warn!("ctrl-c handler failed: {err}");
                return;
            }
            tracing::info!("ctrl-c received; initiating shutdown");
            cancel.cancel();
        });
    }

    let mut tasks = JoinSet::new();

    #[cfg(unix)]
    {
        let cancel = cancel.clone();
        let control = viewer_control_tx.clone();
        let control_socket_path = cfg.control_socket_path.clone();
        let greeting_delay = cfg.greeting_screen.effective_duration();
        let schedule = cfg.awake_schedule.clone();
        tasks.spawn(async move {
            run_control_socket(
                cancel,
                control,
                control_socket_path,
                greeting_delay,
                schedule,
            )
            .await
            .context("control socket task failed")
        });
    }

    // PhotoFiles
    tasks.spawn({
        let cfg = Arc::clone(&cfg);
        let inv_tx = inv_tx.clone();
        let invalid_rx = invalid_rx;
        let cancel = cancel.clone();
        async move {
            tasks::files::run(cfg, inv_tx, invalid_rx, cancel)
                .await
                .context("files task failed")
        }
    });

    // PhotoManager
    tasks.spawn({
        let inv_rx = inv_rx;
        let displayed_rx = displayed_rx;
        let to_load_tx = to_load_tx.clone();
        let cancel = cancel.clone();
        let playlist = cfg.playlist.clone();
        let seed_override = playlist_seed;
        let metrics = cfg.metrics;
        async move {
            tasks::manager::run(
                inv_rx,
                displayed_rx,
                to_load_tx,
                cancel,
                playlist,
                now_override,
                seed_override,
                metrics,
            )
            .await
            .context("manager task failed")
        }
    });

    // PhotoLoader
    tasks.spawn({
        let to_load_rx = to_load_rx;
        let invalid_tx = invalid_tx.clone();
        let loaded_tx = loaded_tx.clone();
        let cancel = cancel.clone();
        let max_in_flight = cfg.loader_max_concurrent_decodes;
        async move {
            tasks::loader::run(to_load_rx, invalid_tx, loaded_tx, cancel, max_in_flight)
                .await
                .context("loader task failed")
        }
    });

    // PhotoEffect pipeline (optional post-processing)
    let photo_effect_cfg = cfg.photo_effect.clone();
    tasks.spawn({
        let from_loader = loaded_rx;
        let to_viewer = processed_tx.clone();
        let cancel = cancel.clone();
        let effect_cfg = photo_effect_cfg;
        async move {
            tasks::photo_effect::run(from_loader, to_viewer, cancel, effect_cfg)
                .await
                .context("photo-effect task failed")
        }
    });

    // Run the windowed viewer on the main thread (blocking) after spawning other tasks
    // This call returns when the window closes or cancellation occurs
    let viewer_result = tasks::viewer::run_windowed(
        processed_rx,
        displayed_tx.clone(),
        cancel.clone(),
        Arc::clone(&cfg),
        viewer_control_rx,
    )
    .context("viewer failed");

    if let Err(err) = &viewer_result {
        tracing::error!("{err:?}");
    }
    // Ensure other tasks are asked to stop
    cancel.cancel();

    // Drain JoinSet (wait for other tasks to complete)
    while let Some(res) = tasks.join_next().await {
        match res {
            Ok(Ok(())) => {}
            Ok(Err(e)) => tracing::error!("task error: {e:?}"),
            Err(e) => tracing::error!("join error: {e}"),
        }
    }

    viewer_result
}

fn run_playlist_dry_run(
    cfg: &config::Configuration,
    iterations: usize,
    now_override: Option<SystemTime>,
    seed: Option<u64>,
) -> Result<()> {
    let now = now_override.unwrap_or_else(SystemTime::now);
    let photos = tasks::files::discover_startup_photos(cfg)?;

    println!(
        "# playlist dry run\n# photos: {}\n# now: {}\n# iterations: {}\n# seed: {}\n# order: {} (min-spacing {:.3})\n",
        photos.len(),
        format_rfc3339(now),
        iterations,
        seed.map_or_else(|| "(random)".to_string(), |s| s.to_string()),
        cfg.playlist.order,
        cfg.playlist.refractory_fraction(),
    );

    if photos.is_empty() {
        println!(
            "(no photos discovered under {})",
            cfg.photo_library_path.display()
        );
        return Ok(());
    }

    println!("# weights (relative show frequency; equilibrium = 1.0):");
    for info in &photos {
        let weight = cfg.playlist.weight_for(info.created_at, now);
        println!("  {:>5.2} × {}", weight, info.path.display());
    }

    let plan = tasks::manager::simulate_playlist(
        photos.clone(),
        cfg.playlist.clone(),
        now,
        iterations,
        seed,
    );

    println!("\n# planned order:");
    if plan.is_empty() {
        println!("(playlist empty)");
    } else {
        for (idx, path) in plan.iter().enumerate() {
            println!("  {:>4}: {}", idx + 1, path.display());
        }
    }

    Ok(())
}

#[cfg(unix)]
#[derive(Debug, Deserialize, PartialEq, Eq)]
#[serde(tag = "command")]
enum ControlCommand {
    #[serde(rename = "toggle-state")]
    ToggleState,
    #[serde(rename = "set-state")]
    SetState { state: ControlState },
}

#[cfg(unix)]
#[derive(Debug, Clone, Copy, PartialEq, Eq, Deserialize)]
#[serde(rename_all = "lowercase")]
enum ControlState {
    Awake,
    Asleep,
}

#[cfg(unix)]
impl From<ControlState> for ViewerState {
    fn from(value: ControlState) -> Self {
        match value {
            ControlState::Awake => ViewerState::Awake,
            ControlState::Asleep => ViewerState::Asleep,
        }
    }
}

#[cfg(unix)]
struct SocketCleanup {
    path: std::path::PathBuf,
}

#[cfg(unix)]
impl Drop for SocketCleanup {
    fn drop(&mut self) {
        if let Err(err) = std::fs::remove_file(&self.path)
            && err.kind() != std::io::ErrorKind::NotFound
        {
            tracing::debug!(path = %self.path.display(), ?err, "failed to remove control socket");
        }
    }
}

#[cfg(unix)]
async fn run_control_socket(
    cancel: CancellationToken,
    control: mpsc::Sender<ViewerCommand>,
    socket_path: PathBuf,
    greeting_delay: Duration,
    schedule: Option<config::AwakeScheduleConfig>,
) -> Result<()> {
    if let Some(parent) = socket_path.parent()
        && let Err(err) = std::fs::create_dir_all(parent)
    {
        if err.kind() == std::io::ErrorKind::PermissionDenied {
            return Err(err).with_context(|| {
                format!(
                    "failed to create control socket directory {parent:?}; ensure the directory is writable or set control-socket-path"
                )
            });
        }
        return Err(err)
            .with_context(|| format!("failed to create control socket directory {parent:?}"));
    }

    if socket_path.exists() {
        match std::fs::remove_file(&socket_path) {
            Ok(_) => tracing::warn!(path = %socket_path.display(), "removed stale control socket"),
            Err(err) if err.kind() == std::io::ErrorKind::NotFound => {}
            Err(err) => {
                return Err(err).with_context(|| {
                    format!(
                        "failed to remove stale control socket at {}",
                        socket_path.display()
                    )
                });
            }
        }
    }

    let listener = UnixListener::bind(&socket_path)
        .with_context(|| format!("failed to bind control socket at {}", socket_path.display()))?;
    let _cleanup = SocketCleanup {
        path: socket_path.clone(),
    };

    tracing::info!(path = %socket_path.display(), "listening for control commands");

    if let Err(err) =
        run_initial_schedule_preamble(&cancel, &control, greeting_delay, schedule.as_ref()).await
    {
        tracing::warn!("control preamble failed: {err}");
    }

    loop {
        tokio::select! {
            _ = cancel.cancelled() => {
                tracing::debug!("shutdown requested; closing control socket");
                break;
            }
            accept_result = listener.accept() => {
                match accept_result {
                    Ok((stream, _addr)) => {
                        let control = control.clone();
                        tokio::spawn(async move {
                            if let Err(err) = handle_control_connection(stream, control).await {
                                tracing::warn!("control connection failed: {err}");
                            }
                        });
                    }
                    Err(err) => {
                        if err.kind() == std::io::ErrorKind::Interrupted {
                            continue;
                        }
                        return Err(err).context("failed to accept control connection");
                    }
                }
            }
        }
    }

    Ok(())
}

#[cfg(unix)]
async fn run_initial_schedule_preamble(
    cancel: &CancellationToken,
    control: &mpsc::Sender<ViewerCommand>,
    greeting_delay: Duration,
    schedule: Option<&config::AwakeScheduleConfig>,
) -> Result<()> {
    if !greeting_delay.is_zero() {
        tracing::debug!(
            delay = %humantime::format_duration(greeting_delay),
            "waiting for greeting preamble before applying schedule",
        );
        let delay = tokio::time::sleep(greeting_delay);
        tokio::pin!(delay);
        tokio::select! {
            _ = cancel.cancelled() => return Ok(()),
            _ = delay => {}
        }
    }

    if cancel.is_cancelled() {
        return Ok(());
    }

    let target_state = schedule
        .map(|schedule| scheduled_viewer_state(schedule, Utc::now()))
        .unwrap_or(ViewerState::Awake);

    tracing::info!(
        ?target_state,
        "control preamble sending initial viewer state"
    );
    control
        .send(ViewerCommand::SetState(target_state))
        .await
        .context("failed to send initial viewer state")?;

    Ok(())
}

#[cfg(unix)]
fn scheduled_viewer_state(
    schedule: &config::AwakeScheduleConfig,
    now: DateTime<Utc>,
) -> ViewerState {
    let local_now = now.with_timezone(&schedule.timezone());
    if schedule.is_awake_at(local_now) {
        ViewerState::Awake
    } else {
        ViewerState::Asleep
    }
}

#[cfg(all(test, unix))]
mod schedule_tests {
    use super::*;
    use chrono::TimeZone;

    #[test]
    fn scheduled_viewer_state_respects_intervals() {
        let yaml = r#"
timezone: "UTC"
awake-scheduled:
  daily:
    - ["06:00", "08:00"]
    - ["10:00", "22:00"]
"#;

        let schedule: config::AwakeScheduleConfig =
            serde_yaml::from_str(yaml).expect("valid schedule");

        let awake_morning = Utc
            .with_ymd_and_hms(2024, 5, 1, 7, 30, 0)
            .earliest()
            .expect("valid time");
        assert_eq!(
            scheduled_viewer_state(&schedule, awake_morning),
            ViewerState::Awake
        );

        let asleep_gap = Utc
            .with_ymd_and_hms(2024, 5, 1, 9, 0, 0)
            .earliest()
            .expect("valid time");
        assert_eq!(
            scheduled_viewer_state(&schedule, asleep_gap),
            ViewerState::Asleep
        );

        let awake_evening = Utc
            .with_ymd_and_hms(2024, 5, 1, 12, 0, 0)
            .earliest()
            .expect("valid time");
        assert_eq!(
            scheduled_viewer_state(&schedule, awake_evening),
            ViewerState::Awake
        );
    }
}

#[cfg(unix)]
async fn handle_control_connection(
    mut stream: tokio::net::UnixStream,
    control: mpsc::Sender<ViewerCommand>,
) -> Result<()> {
    let mut buf = Vec::with_capacity(128);
    stream
        .read_to_end(&mut buf)
        .await
        .context("failed to read control command")?;

    if buf.is_empty() {
        tracing::debug!("ignoring empty control payload");
        return Ok(());
    }

    let payload_text = String::from_utf8_lossy(&buf);

    let request: ControlCommand = match serde_json::from_slice(&buf) {
        Ok(command) => command,
        Err(err) => {
            tracing::warn!(payload = %payload_text, "invalid control payload: {err}");
            return Ok(());
        }
    };

    match request {
        ControlCommand::ToggleState => {
            tracing::info!(command = "toggle-state", "received control command");
            control
                .send(ViewerCommand::ToggleState)
                .await
                .context("failed to forward toggle-state command")?;
        }
        ControlCommand::SetState { state } => {
            let viewer_state: ViewerState = state.into();
            tracing::info!(
                command = "set-state",
                ?viewer_state,
                "received control command"
            );
            control
                .send(ViewerCommand::SetState(viewer_state))
                .await
                .context("failed to forward set-state command")?;
        }
    }

    Ok(())
}

#[cfg(unix)]
mod tests {
    #[test]
    fn deserialize_toggle_state_command() {
        let cmd: super::ControlCommand = serde_json::from_str(r#"{"command":"toggle-state"}"#)
            .expect("toggle-state should parse");
        assert_eq!(cmd, super::ControlCommand::ToggleState);
    }

    #[test]
    fn deserialize_set_state_awake() {
        let cmd: super::ControlCommand =
            serde_json::from_str(r#"{"command":"set-state","state":"awake"}"#)
                .expect("set-state should parse");

        assert_eq!(
            cmd,
            super::ControlCommand::SetState {
                state: super::ControlState::Awake
            }
        );
    }

    #[test]
    fn deserialize_set_state_asleep() {
        let cmd: super::ControlCommand =
            serde_json::from_str(r#"{"command":"set-state","state":"asleep"}"#)
                .expect("set-state should parse");

        assert_eq!(
            cmd,
            super::ControlCommand::SetState {
                state: super::ControlState::Asleep
            }
        );
    }

    #[test]
    fn deserialize_toggle_state_alias_rejected() {
        serde_json::from_str::<super::ControlCommand>(r#"{"command":"ToggleSleep"}"#)
            .expect_err("ToggleSleep should be rejected");
    }

    #[test]
    fn deserialize_set_state_alias_rejected() {
        serde_json::from_str::<super::ControlCommand>(r#"{"command":"set-state","state":"sleep"}"#)
            .expect_err("set-state sleep alias should be rejected");
    }

    #[test]
    fn deserialize_set_state_rejects_unknown() {
        let err = serde_json::from_str::<super::ControlCommand>(
            r#"{"command":"set-state","state":"invalid"}"#,
        )
        .expect_err("invalid state should fail");

        let message = err.to_string();
        assert!(message.contains("unknown variant"));
        assert!(message.contains("awake"));
        assert!(message.contains("asleep"));
    }
}

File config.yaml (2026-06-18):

# Recommended configuration for photoframe — a rich, tasteful default that shows
# off the frame's variety out of the box. This is the file the installer seeds to
# /etc/photoframe/config.yaml on first install. Adjust to taste.
#
# Other starting points live in examples/ (see examples/README.md):
#   examples/minimal.yaml      — the smallest valid config; build up from defaults
#   examples/use-showcase.yaml — enable the labeled tour of every transition and mat
#   examples/everything.yaml   — every kind AND every parameter variant, to trim down

# Config schema version. Leave at 1 unless a release note tells you to change it;
# the binary rejects a version it doesn't understand with a clear message.
config-version: 1

# Root directory for images. Keep media in the managed subdirectories to
# separate synced libraries from ad-hoc drops:
#   cloud/ — populated by rclone or other sync jobs; safe to wipe/reseed.
#   local/ — manual imports (USB, scp) that should persist across syncs.
photo-library-path: /var/lib/photoframe/photos

# Unix domain socket path for runtime control commands
control-socket-path: /run/photoframe/control.sock

# Hardware button daemon configuration
buttond:
  # Optional explicit evdev device path (autodetects when null)
  device: null
  debounce-ms: 20
  single-window-ms: 250
  double-window-ms: 400
  force-shutdown: true # true means -i --no-ask-password added to the systemctl poweroff call
  shutdown-command:
    program: /usr/bin/systemctl
    args: [poweroff]
  screen:
    off-delay-ms: 3500
    display-name: null # Optional wlr-randr output name, such as HDMI-A-1
    on-command:
      program: /opt/photoframe/bin/powerctl
      args: [wake]
    off-command:
      program: /opt/photoframe/bin/powerctl
      args: [sleep]

# Render/transition settings
transition:
  # Choose how the viewer advances through the entries below: fixed, random, or sequential.
  selection: random
  # One entry per transition kind, tuned for variety (multi-angle wipes/pushes,
  # both radial shapes, both blind orientations). Repeat a kind to weight it more
  # heavily, tweak any value, or delete entries you don't want. `showcase` mode
  # previews each kind individually with on-screen labels (see showcase/README.md).
  active:
    - kind: fade
      duration-ms: 450
      through-black: false # true: fade to black before revealing the next photo
    - kind: wipe
      duration-ms: 600
      angles: [0.0, 90.0, 180.0, 270.0] # directions to rotate through
      angle-jitter: 12.0 # randomize direction by ±this many degrees
      softness: 0.08
    - kind: push
      duration-ms: 520
      angles: [0.0, 90.0, 180.0, 270.0]
      angle-jitter: 8.0
    - kind: e-ink
      duration-ms: 1600
      flash-count: 0
      reveal-portion: 0.55
      stripe-count: 24
      flash-color: [255, 255, 255]
    - kind: dissolve # threshold value-noise field by progress
      duration-ms: 600
      softness: 0.1 # 0 = hard per-pixel pop, up to ~0.5 = soft edge
      scale: 64.0 # noise cell size in pixels
    - kind: radial-wipe # circle or diamond reveal from center
      duration-ms: 500
      softness: 0.1
      shapes: [circle, diamond] # circle | diamond; list several for variety
      center: [0.5, 0.5]
    - kind: venetian-blinds # horizontal/vertical stripe reveal
      duration-ms: 600
      stripe-count: 16
      softness: 0.1
      orientations: [horizontal, vertical]
    - kind: crossfade-zoom # fade combined with subtle scale
      duration-ms: 700
      zoom: 0.06
      current-zooms-in: true
      next-zooms-in: true
    - kind: iris # mechanical camera-iris: petals close over the photo, reopen on the next
      duration-ms: 2600
      blades: 12 # petal count (5-14); geometry is derived automatically
      color: [42, 42, 49] # base petal RGB; mid-dark shows the shading best
      petal-sheen: 0.5 # 0-1: directional sheen on the blades; 0 = flat petals
      overlap-shadow: 0.6 # 0-1: soft shadow each petal casts on its neighbor
      min-aperture: 0.01 # fraction of screen circumradius left open at the swap
      swirl: -0.45 # signed twist of the whole rosette while closing (0 = none)

# Global photo settings
global-photo-settings:
  # Dwell time (ms) the current image remains fully displayed before the next
  # transition. ~8-16 s is typical; lower is brisker, higher is calmer.
  dwell-ms: 10000
  # GPU render oversample factor (1.0 = native to screen)
  oversample: 1.0
  # Maximum enlargement applied when fitting small photos
  max-upscale-factor: 1.0

# Greeting screen displayed while the first images are prepared
greeting-screen:
  message: "Warming up your photo memories…"
  font: "Macondo"
  stroke-width: 16
  duration-seconds: 6
  colors:
    background: "#f0e8d5"   # warm parchment
    font: "#2d3748"         # soft charcoal
    accent: "#7da8a5"       # tranquil sea-glass teal
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

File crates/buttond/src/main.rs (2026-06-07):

use std::env;
use std::fmt;
use std::fs;
use std::io::{self, Write};
use std::os::fd::AsFd;
use std::os::unix::fs::{FileTypeExt, MetadataExt};
use std::os::unix::net::UnixStream;
use std::path::{Path, PathBuf};
use std::process::Command;
use std::sync::mpsc::{self, TryRecvError};
use std::sync::{Arc, Mutex};
use std::thread;
use std::time::{Duration, Instant};

use anyhow::{Context, Result, anyhow, bail};
use chrono::{Duration as ChronoDuration, Utc};
use clap::Parser;
use config_model::{AwakeScheduleConfig, GreetingScreenConfig};
use evdev::{Device, EventSummary, KeyCode};
use humantime::format_duration;
use nix::fcntl::{FcntlArg, OFlag, fcntl};
use serde::Deserialize;
use serde_json::json;
use tracing::{debug, error, info, warn};
use tracing_subscriber::EnvFilter;

#[derive(Debug, Clone, Parser)]
#[command(
    name = "buttond",
    about = "Power button handler for the Rust photo frame"
)]
struct Args {
    /// Path to the shared configuration file.
    #[arg(long, default_value = "/etc/photoframe/config.yaml")]
    config: PathBuf,

    /// Input device path (evdev). Auto-detects when omitted.
    #[arg(long)]
    device: Option<PathBuf>,

    /// Logging level (error|warn|info|debug|trace).
    #[arg(long, default_value = "info")]
    log_level: String,
}

fn main() -> Result<()> {
    let args = Args::parse();
    init_tracing(&args.log_level)?;

    let settings = ButtondSettings::load(&args.config, args.device.clone()).with_context(|| {
        format!(
            "failed to load configuration from {}",
            args.config.display()
        )
    })?;
    let device_override = settings.device.clone();
    let durations = settings.durations;
    let (mut runtime, scheduler_config) = settings.into_runtime()?;

    let mut scheduler_rx =
        scheduler_config.and_then(|config| spawn_scheduler(config, runtime.shared_state()));

    let (mut device, path) = open_device(device_override.as_ref())?;
    set_nonblocking(&device)
        .with_context(|| format!("failed to set {} non-blocking", path.display()))?;
    info!(device = %path.display(), "listening for power button events");

    let mut tracker = ButtonTracker::new(durations);

    loop {
        if let Some(rx) = scheduler_rx.as_ref() {
            let mut disconnected = false;
            loop {
                match rx.try_recv() {
                    Ok(SchedulerCommand::WakeUp) => {
                        if let Err(err) = runtime.wake_up(TransitionSource::Scheduled) {
                            error!(?err, "failed to process scheduled wake");
                        }
                    }
                    Ok(SchedulerCommand::GoToSleep) => {
                        if let Err(err) = runtime.go_to_sleep(TransitionSource::Scheduled) {
                            error!(?err, "failed to process scheduled sleep");
                        }
                    }
                    Err(TryRecvError::Empty) => break,
                    Err(TryRecvError::Disconnected) => {
                        warn!("scheduler channel disconnected");
                        disconnected = true;
                        break;
                    }
                }
            }
            if disconnected {
                scheduler_rx = None;
            }
        }

        let now = Instant::now();
        // Fire any deferred screen power-off whose delay has elapsed. Runs every
        // iteration so the panel powers down without ever blocking on a sleep.
        runtime.poll_pending_power_off(now);

        if let Some(action) = tracker.handle_timeout(now) {
            perform_action(action, &mut runtime);
            continue;
        }

        let idle = match device.fetch_events() {
            Ok(events) => {
                let mut handled = false;
                for event in events {
                    handled = true;
                    if let EventSummary::Key(_, KeyCode::KEY_POWER, value) = event.destructure() {
                        match value {
                            1 => {
                                tracker.on_press(Instant::now());
                            }
                            0 => {
                                if let Some(action) = tracker.on_release(Instant::now()) {
                                    perform_action(action, &mut runtime);
                                }
                            }
                            _ => {}
                        }
                    }
                }
                !handled
            }
            Err(err) if err.kind() == io::ErrorKind::WouldBlock => true,
            Err(err) => return Err(err).with_context(|| "failed reading input events"),
        };

        if idle {
            let mut sleep_for = tracker
                .time_until_deadline(Instant::now())
                .unwrap_or(Duration::from_millis(50));
            // Don't oversleep past a pending power-off deadline.
            if let Some(until_off) = runtime.time_until_power_off(Instant::now()) {
                sleep_for = sleep_for.min(until_off);
            }
            if !sleep_for.is_zero() {
                thread::sleep(sleep_for.min(Duration::from_millis(100)));
            }
        }
    }
}

struct ButtondSettings {
    device: Option<PathBuf>,
    durations: Durations,
    control_socket_path: PathBuf,
    shutdown_command: CommandSpec,
    screen_on_command: CommandSpec,
    screen_off_command: CommandSpec,
    screen_off_delay: Duration,
    screen_display_name: Option<String>,
    greeting_screen_delay: Duration,
    awake_schedule: Option<AwakeScheduleConfig>,
}

const FORCE_SHUTDOWN_FLAG: &str = "-i";
const NO_ASK_PASSWORD_FLAG: &str = "--no-ask-password";

fn configure_shutdown_args(program: &Path, args: &mut Vec<String>, force_shutdown: bool) {
    let program_name = program
        .file_name()
        .and_then(|n| n.to_str())
        .unwrap_or("")
        .to_ascii_lowercase();

    // Only systemctl understands -i/--no-ask-password for poweroff.
    let is_systemctl = program_name == "systemctl";

    if is_systemctl {
        configure_shutdown_flag(args, FORCE_SHUTDOWN_FLAG, force_shutdown);
        configure_shutdown_flag(args, NO_ASK_PASSWORD_FLAG, force_shutdown);
    } else {
        // Avoid passing systemctl-specific flags to other programs (e.g., loginctl).
        let before = args.len();
        args.retain(|arg| arg != FORCE_SHUTDOWN_FLAG && arg != NO_ASK_PASSWORD_FLAG);
        if before != args.len() {
            warn!(
                program = program_name,
                "stripped systemctl-only shutdown flags from non-systemctl program"
            );
        }
        if force_shutdown {
            warn!(
                program = program_name,
                "force-shutdown enabled but program is not systemctl; ignoring flags"
            );
        }
    }
}
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

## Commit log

2025-09-12 Tier-1 scaffolding: lib API, scan opts, circular buffer
    Add config/scan/buffer/events modules + error type
    Public API: scan_photos → build_buffer → run_slideshow
    Fix scan: don’t skip root dot-dirs; support depth control
    Add tests (scan + buffer) and rustdoc for public items
    Clean clippy warnings; add Cargo.toml metadata
    Add README and MIT LICENSEa
    [main.rs]
2025-09-14 GPU-ready pipeline scaffolding and robustness updates
    - Manager: add 50ms idle tick; keep pacing via loader backpressure; channel caps set to 1.
    - Files: delete invalid photos instead of quarantine; simplify logic; add tracing.
    - Config: drop photo_quarantine_path (update examples, tests).
    - Events: add MatMode and PreparedImageCpu; PhotoLoaded carries CPU-prepared image.
    - Loader: decode to RGBA8, stub EXIF orientation, send PreparedImageCpu; debug logs.
    - Viewer: wgpu offscreen renderer, texture upload, compute_dest_rect, mat modes (letterbox, studio, blur), basic crossfade, Displayed after dwell.
    - Shaders: add viewer_quad.wgsl and blur_bg.wgsl.
    - Tests: fix clippy issues; add viewer layo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
    [config.yaml, main.rs]
2025-09-14 Viewer sizing + upload robustness
    - Config: add oversample (default via struct Default), thread through main.
    - Events: SurfaceSize carries oversample.
    - Viewer: use surface*oversample for target size; clamp to device max; log resize.
    - Upload: compute_scaled_size to avoid oversize; log downscales; pad rows to 256B.
    - Helpers: compute_padded_stride, compute_scaled_size.
    - Tests: stride alignment, scaled size cases, config default + explicit oversample.
    - Loader: EXIF orientation via kamadak-exif; RGBA8 decode.
    [main.rs, viewer.rs]
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2025-09-15 viewer: add PNG loading overlay; drop glyphon; center-scale loading texture
    - Remove glyphon integration (version mismatch with wgpu 26)
    - Load assets/ui/loading.png via include_bytes!, upload as SRGB texture
    - Draw centered while no photo is ready using existing quad pipeline
    - Keep fullscreen + hidden cursor behavior
    Prep for next steps: orientation fix, crossfade, dwell, prefetch.
    [viewer.rs]
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2025-09-15 manager: rotate playlist on send; remove last_displayed
    - Keep items in playlist by rotating on successful send
    - Stop re-queuing on Displayed; Displayed is informational
    - Simplify logic to avoid scans and state coupling
    viewer: honor backpressure; stop dropping pending
    - Only receive PhotoLoaded when pending has capacity
    - Remove eviction of oldest pending; let channels fill
    - Preserves full pipeline and prevents silent drops
    [main.rs, viewer.rs]
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2026-03-03 Restructure README, deduplicate setup scripts, harden Wi-Fi recovery
    - README: lead with project description, hardware requirements, quick-start;
    collapse inline install steps in favour of docs/; fix PhotoAffect→PhotoEffect
    in diagram; remove broken fabrication.md link
    - setup: extract read_env_value/configure_sync_timer to setup/lib/systemd.sh;
    source the shared library from all five scripts that previously redefined them;
    fix broken diagnostics.sh reference; add sudo pre-flight check to deploy.sh;
    harden font download to emit a warning on failure rather than silently continuing
    - wifi-manager: harden recovery submission path (atomic writes, teardown race
    fix in web.rs, autoco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
    [mod.rs]
2026-03-03 Refactor and harden photoframe crate (steps 4-12)
    viewer: extract ~400 lines of utility functions into tasks/viewer/image_ops.rs;
    deduplicate Wipe/Push angle normalisation with angle_to_unit_vec(); collapse
    three-variant ViewerMode enum (all variants had identical fields) into a plain
    struct + ViewerModeKind discriminant, removing ~60 lines of repeated match arms
    manager: replace O(n²) prioritised-queue rebuild loop with a HashMap for O(1)
    lookups, keeping the same ordering semantics
    files: add SUPPORTED_EXTENSIONS constant; document TOCTOU benignness and
    WalkDir symlink-safety in comments; pass Arc<Configuration> instead of cloning
    loader: open each file once — read EXIF ori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
    [main.rs, viewer.rs]
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2026-03-03 Add portal URL QR code, fix hotspot response teardown, and pass clippy/fmt
    Wi-Fi recovery UX improvements:
    - overlay/ui.rs: show two QR codes side-by-side — left scans to join the
    hotspot (WIFI: URI), right opens the setup page in the browser without
    typing the IP address manually; fallback text shown below right QR when
    image unavailable
    - qr.rs: add generate_portal_qr() encoding http://<ip>:<port>/; add
    portal_qr_path() and wifi_qr_path() helpers; keep qr_path() as alias
    - watch.rs: generate portal QR on recovery entry alongside the existing
    Wi-Fi credentials QR
    - web.rs: add Connection: close header to the submit success response so
    the browser finalises the TCP connection b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
    [greeting_screen.rs]
2026-03-07 Complete documentation redesign for hobbyists and makers
    Fix a real bug: config.yaml shipped with awake-schedule enabled and
    friday: [] (all-day sleep on Fridays), causing a confusing black screen
    on first boot. Also fixes powerctl examples throughout to require
    sudo -u kiosk, matching how the tool actually works.
    New docs:
    - docs/installation.md: full install guide with time estimates, expected
    display behavior, and a prominent "why the screen goes dark" section
    - docs/first-boot.md: step-by-step normal boot sequence; explains sleep
    state and how to wake the frame
    - docs/troubleshooting.md: 11 symptom → cause → fix entries; leads with
    the black-screen-after-greeting issue
    - docs/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
    [config.yaml]
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2026-05-07 config: fix dwell time, greeting duration, and example polish
    Urgent fixes:
    - dwell-ms 2000 → 12000 ms: 2 s is too fast for a wall-mounted frame
    - greeting-screen duration-seconds 16 → 6: 16 s greeting is tedious on restart
    - Same dwell-ms fix applied to the starter config snippet in configure.md
    Polish:
    - e-ink flash-count 0 → 2, flash-color black → white: demonstrate the
    flash feature and restore the documented default color
    - Replace through-black: false (a no-op default) with a commented hint
    - wipe angle-list-degrees [45, 225] → [0, 90, 180, 270]: show all four
    cardinal directions instead of two diagonals on the same axis
    - fixed-color minimum-mat-percentage 0.0 → 2.0: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
    [config.yaml]
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2026-05-26 Tune default config for beautiful out-of-box experience
    Transitions:
    - e-ink flash-count 2 → 0 (no flash by default)
    - push gains vertical angles (90°/270°) to match wipe variety
    Photo effect:
    - Enable print-simulation with subtle gallery settings
    (relief 0.30, ink-spread 0.15, sheen 0.18, warm white paper)
    Applies to every photo; the only active effect entry
    Timing:
    - Dwell time 12s → 16s for more contemplative viewing
    Matting:
    - Replace hardcoded fixed-image path (would 404 on every fresh install)
    with a commented template pointing to /var/lib/photoframe/backgrounds/
    Docs:
    - install.md custom mat backgrounds note now says to also uncomment the
    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
    [config.yaml]
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2026-05-29 Add fill-when-fits matting for near-aspect-ratio photos
    Photos already close to the display's aspect ratio can now render
    full-bleed (cover-crop, no mat) to fully use a large display, instead
    of always being matted/letterboxed.
    The optional matting.fill-when-fits block has two knobs:
    - maximum-crop-percentage: eligibility threshold (resolution-independent
    aspect math); also requires the image fit within max-upscale-factor.
    - skip-matting-probability: biased coin for eligible photos (1.0 always
    fills, 0.0 never, in between mixes).
    Evaluated per photo before mat selection, so ineligible photos fall
    through to normal selection and the sequential/random/fixed pools are
    untouched. Full-blee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
    [config.yaml, viewer.rs]
2026-05-30 Fix button vs schedule race with an explicit override state machine
    The scheduler only honored manual *wake* overrides (via last_manual_awake),
    checked solely in the sleep branch. A manual *sleep* during a scheduled wake
    window was invisible, so the scheduler re-woke the frame within ~100ms — the
    "tucking in" message would flash and photos resumed.
    Replace the asymmetric logic with a symmetric override model on FrameState:
    Override = Unset | ForceWake | ForceSleep
    A press records an override toward its own target. Each scheduler tick computes
    the schedule's desired mode, then reconcile_override() clears the override once
    the schedule agrees with it (stateless equivalent of "reset at t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
    [config.yaml, main.rs]
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2026-05-30 Add five new transition kinds: dissolve, radial-wipe, venetian-blinds, crossfade-zoom, iris
    - dissolve (index 5): threshold value-noise by progress; params softness + scale
    - iris (index 7): regular-polygon SDF aperture reveal with rotation; params blades/softness/center/rotation
    - radial-wipe (index 8): Euclidean or Manhattan distance reveal from center; params center/softness/shape
    - venetian-blinds (index 9): horizontal/vertical stripe reveal; params stripe-count/softness/orientation
    - crossfade-zoom (index 10): cross-fade with per-plane scale; params zoom/current-zooms-in/next-zooms-in
    Each transition is wired through config.rs (TransitionKind, TransitionMode, structs, defaults,
    builder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
    [config.yaml, viewer.rs]
2026-05-30 Add showcase mode: labeled auto-enumerating tour of every effect
    showcase.enabled activates a self-maintaining tour of all 9 mats and 9
    transitions without editing any config. Key pieces:
    - Config: new showcase block (config-model ShowcaseConfig + Configuration.showcase)
    with enabled, caption, dwell-ms, fixed-image-path fields.
    - Synthesis: Configuration::apply_showcase_overrides() (called in validated())
    builds sequential transition/matting lists from TransitionKind::ALL /
    MattingKind::ALL. Fixed-image is omitted when no path is given.
    Exhaustiveness tests assert counts match ALL lengths so future effects
    automatically appear.
    - Mat label threading: mat_kind: Option<MattingKind>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
    [mod.rs, viewer.rs]
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2026-05-31 Document effect catalog in README; activate all effects in config.yaml
    - README: add a compact "Transitions & mats" table listing all 9 transitions
    and 9 mats with one-line descriptions, pointing to the showcase tour,
    config.yaml (commented examples), and docs/configure.md (full reference).
    - config.yaml: uncomment the 5 new transitions (dissolve, radial-wipe,
    venetian-blinds, crossfade-zoom, iris) and 5 new mats (gradient, vignette,
    cinematic-blur, passe-partout, drop-shadow) into the active lists so the
    example config exercises every built-in effect. fixed-image stays commented
    (needs an operator-supplied backdrop path).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
    [config.yaml]
2026-05-31 Fix showcase caption: persist last transition, drop garbage glyph, add legible color
    Three fixes to the showcase caption overlay:
    - Stale/wrong label after a transition: the caption read the live
    transition_state, which is None once a transition finishes, so it fell back to
    "transition: —". Now WakeScene remembers the most recent transition kind
    (set whenever a transition starts) and the caption shows that plus the current
    photo's mat — i.e. "the transition that just happened, and the current mat".
    - Garbage characters: the None-fallback used a non-ASCII em-dash that rendered
    as tofu under the caption's system font. Replaced with ASCII "none" (and the
    fallback is now rarely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
    [mod.rs, viewer.rs]
2026-05-31 Fix showcase caption: record transition kind at start; outline for legibility
    - "transition: none" forever: maybe_start_transition assigned
    self.transition_state directly, bypassing the setter, so last_transition_kind
    never updated. Record the kind there (it's already in scope) so the caption
    names the running/just-finished transition.
    - Inconsistent readability: a single drop-shadow still washed out on mid-tone
    mats (blur/studio/gradient). Replace it with a full 8-direction black outline
    around the light-cyan fill so the caption reads on any background.
    [mod.rs]
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2026-05-31 config.yaml: mirror showcase defaults so the tour is the out-of-box experience
    Set every transition and mat entry to the same defaults the showcase tour
    synthesizes (all mats at minimum-mat-percentage 6.0; default transition
    durations/params; studio/passe-partout bevel 3.0; single-angle wipe/push with no
    jitter; fixed-color single black swatch). Now a user who likes the showcase can
    keep config.yaml as-is and get the same look (minus labels), or tweak/delete
    entries. Inline comments point at the common customizations.
    [config.yaml]
2026-05-31 Add list-expansion for orientation/shape; unify vignette/drop-shadow color spec
    Compact multi-variant config in the style of wipe's angle-list:
    - venetian-blinds: `orientations: [horizontal, vertical]` expands into one slot
    per orientation (singular `orientation` still works).
    - radial-wipe: `shapes: [circle, diamond]` expands into one slot per shape
    (singular `shape` still works).
    Unify the mat color story:
    - vignette and drop-shadow now take a `colors:` list of StudioMatColor (so they
    accept `photo-average` like fixed-color/studio/passe-partout) and expand into
    one slot per color. Singular `color:` remains as a convenience alias and now
    also accepts `photo-average`. Resolved per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
    [config.yaml, viewer.rs]
2026-05-31 Standardize one-or-many keys: color alias for all color mats; drop shape/orientation singulars
    Apply a consistent rule — a singular alias exists only where the value is a
    composite (an [r,g,b]/photo-average color), where `[[...]]` nesting is awkward
    and an easy foot-gun; scalar-valued lists are plural-only.
    - Add `color` singular alias to `studio` and `passe-partout` (parity with
    fixed-color/vignette/drop-shadow; accepts photo-average; guards against the
    `colors: [24,24,28]` mistake).
    - Drop the singular `shape`/`orientation` keys added earlier; radial-wipe uses
    `shapes: [...]` and venetian-blinds uses `orientations: [...]` only (a single
    value is just a one-element list, e.g. `[c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
    [config.yaml]
2026-05-31 Rename wipe/push angle keys: angle-list-degrees->angles, angle-jitter-degrees->angle-jitter
    Harmonize the last list key with the simple-plural style (shapes/orientations/
    colors). `angles` is the per-direction list; `angle-jitter` is the ± randomizer.
    Both are still degrees (documented). Error messages, the unknown-field
    suggestion list (also dropped the vestigial `angle-selection`), config.yaml,
    docs/configure.md, and tests all updated. Internal Rust field names are
    unchanged (not user-facing).
    [config.yaml]
2026-05-31 Clear clippy warnings and fix the doomed compositor-init retry
    - Resolve all clippy findings without #[allow]: struct-init for the showcase
    builder + `if` instead of match-for-equality; drop no-op `.min(255)` on u8
    casts (vignette overlay, cinematic-blur darken); refactor render_drop_shadow to
    take a DropShadowParams struct and drop two unused canvas args (11→6 args).
    - Replace the EventLoop creation retry loop with a single attempt: winit forbids
    recreating an EventLoop in-process, so retrying could never recover and instead
    masked the real cause with "EventLoop can't be recreated". Now a missing
    compositor fails fast with an actionable message (run inside the Wayland
    sessio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
    [viewer.rs]
2026-05-31 Add config-version schema key + tests that the shipped configs validate
    - New top-level `config-version` key (default 1, SUPPORTED_CONFIG_VERSION=1).
    validated() rejects a version this build doesn't understand with an actionable
    message, instead of a confusing per-key unknown-field error. Bump only on a
    breaking schema change.
    - Add it to config.yaml and showcase.yaml (both `config-version: 1`) and document
    it in docs/configure.md.
    - Tests: config-version accept/reject; plus golden tests that the repo's
    config.yaml and showcase/showcase.yaml parse AND validate() — this is the
    guard that would have caught the angle-key rename before it shipped.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
    [config.yaml]
2026-05-31 Prep for 1.0: track Cargo.lock (cargo update), bump versions, doc polish
    - Stop gitignoring Cargo.lock and commit it (reproducible builds on the Pi);
    refreshed by `cargo update`. Workspace builds and tests pass on the new lockfile.
    - Bump all workspace crates 0.1.0 -> 1.0.0.
    - LICENSE/README copyright 2025 -> 2026; README transition count nine -> eight
    (iris removed); photoframe --help about-string; operate.md fixes
    (toggle-state command casing, scp -> rsync for photo transfer).
    [main.rs]
2026-05-31 buttond: re-resolve sway socket per command + back off failed retries
    buttond cached the sway IPC socket path once at startup and injected it as
    SWAYSOCK on every command. The socket filename embeds sway's PID, so when the
    greetd-launched compositor restarted, buttond stayed pinned to the dead socket
    for the rest of its lifetime — every screen-on/off/state command failed with
    "Unable to connect to .../sway-ipc.<uid>.<old-pid>.sock", and the frame never
    woke. Forwarding the stale SWAYSOCK also defeated powerctl's own rediscovery,
    since it trusts an inherited SWAYSOCK whose (orphaned) socket file still exists.
    SwayEnvironment now keeps only the stable runtime dir and re-resolves the live
    so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
    [main.rs]
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2026-06-05 playlist: schedule photos on a virtual timeline instead of a shuffle-bag
    Replace the duplicate-into-a-shuffled-VecDeque playlist with a virtual-time
    (exponential-clock) scheduler: a min-heap keyed by a per-photo "next show
    time", where each shown photo is rescheduled a random gap ahead with mean
    1/weight. Weight is now continuous (max(1, new_multiplicity * 0.5^(age/
    half_life))) rather than an integer multiplicity.
    This fixes the prior model's structural problems:
    - inventory changes no longer rebuild the deck and wipe "already shown"
    progress; adds/removes are O(log n) incremental heap ops
    - weighting duplicates no longer cluster into bursts
    - no back-to-back repeats at lap seams (there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
    [main.rs]
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2026-06-05 buttond: non-blocking screen-off delay + wake_up self-heal
    - go_to_sleep no longer blocks the single event-loop thread with thread::sleep
    for the screen-off delay (default 3.5s). It records the Asleep viewer state
    immediately (so the level-triggered scheduler settles) and arms a deferred
    power-off; the main loop fires it via poll_pending_power_off once the deadline
    passes, so button presses -- including a double-press shutdown -- keep being
    serviced during the delay. A wake during the window cancels the pending
    power-off; a single press during the window cancels the sleep and wakes. A
    failed power-off is retried (bounded) instead of silently leaving the panel on.
    - wake_up now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
    [main.rs]
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2026-06-05 hardening: guard empty surface caps + retry setup network fetches
    - viewer: GPU (re)init indexed caps.formats[0] / caps.alpha_modes[0] without
    checking the surface capability lists are non-empty, panicking the always-on
    viewer if get_capabilities() ever returns empty (lost/incompatible surface on
    the resume/recovery path). Fall back gracefully and exit the loop (matching
    the existing GPU-init error handling) instead of panicking.
    - setup: add curl --retry to the rustup-init and font downloads so a transient
    network blip during provisioning doesn't abort the stage.
    [viewer.rs]
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2026-06-05 style: cargo fmt --all
    Apply rustfmt across the workspace. The photoframe crate and config-model had
    pre-existing formatting drift; this brings the tree to a clean 'cargo fmt --check'
    state for 1.0. No functional changes.
    [main.rs, mod.rs, viewer.rs]
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2026-06-06 wifi-manager: replace unmaintained 'users' crate with libc::getuid()
    cargo audit flags users 0.11 for RUSTSEC-2025-0040 (vulnerability: root appended
    to group listings), RUSTSEC-2023-0040 (unmaintained), and RUSTSEC-2023-0059
    (unsound unaligned read). wifi-manager only used it for get_current_uid(); switch
    to libc::getuid() (as buttond already does), dropping the dependency entirely.
    The vulnerable group-listing API was never used here, but this clears the
    advisory and removes the unmaintained/unsound crate from the tree.
    [main.rs, mod.rs]
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2026-06-06 buttond/setup: survive startup races (sway-not-ready, binary-not-yet-installed)
    A clean Pi install surfaced two transient crash-loops that self-healed but
    tripped the postcheck:
    - buttond exited 1 when its initial screen-state probe ran before sway had
    created its IPC socket (buttond starts After=graphical.target, but the kiosk
    session's sway comes up a beat later). The state is re-detected on every
    toggle and reconciled by the scheduler, so initial detection is now
    non-fatal: log a warning and default to Awake instead of crash-looping.
    - buttond.service and photoframe-wifi-manager.service crash-looped with
    203/EXEC during the system stage, before the application stage installed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
    [main.rs]
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2026-06-07 fix(viewer): cache the showcase caption to a texture to stop dropped/truncated glyphs
    The showcase caption re-shaped, re-measured, re-uploaded glyphs, and drew in a single pass every frame. After the overlay's GPU completion was made non-blocking, that exposed a race: captions rendered before their glyphs were resident, blanking letters ("studio" -> "stud o", "gradient" -> "grar ient") and, when measured mid-shape, truncating the text and its backing box ("passe-partout" -> "passe-parto").
    Now the caption (dark backing + text) is rendered into a small offscreen texture only when the text or surface changes, shaping fully (shape_until_scroll) before measuring, then composited as one premulti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
    [mod.rs]
2026-06-07 test(viewer): GPU readback regression test for the showcase caption
    Renders a caption into the offscreen cache, reads it back, and asserts the backing panel fills the cache (alpha) and the glyphs actually render (cyan text pixels) — guarding the dropped/truncated-glyph regression. Skips when no GPU adapter is present. Adds COPY_SRC to the cache texture so it can be captured/read back.
    [mod.rs]
2026-06-07 fix(buttond): retry screen power-off forever with backoff + gate on Wayland session
    On a cold boot in a sleep window, buttond could show the asleep screen but leave the monitor on. buttond owns the DPMS power-off (powerctl), starts at graphical.target (greetd active != compositor ready), and gave up after ~30 attempts — before the Sway session was reachable — permanently losing the power-off until the next schedule change.
    poll_pending_power_off and power_off_now now re-arm with exponential backoff (reusing retry_backoff, 1s->60s) and never give up; a wake/toggle still cancels the pending power-off so it never fights the user. Drops MAX_POWER_OFF_ATTEMPTS and POWER_OFF_RETRY_INTERVAL.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
    [main.rs]
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2026-06-07 fix(viewer): stop trimming the caption glyph atlas
    The showcase caption shares one long-lived TextAtlas across scenes; atlas.trim() between scenes evicted glyphs, and re-adding them on the Pi's V3D driver dropped/garbled specific ones (intermittent, history-dependent — which is why the single-render test passed but the live tour failed). The caption's glyph set is tiny and fixed, so the atlas reaches a small steady state and never needs trimming. Guarded by the caption_glyphs_survive_atlas_churn test.
    [mod.rs]
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
